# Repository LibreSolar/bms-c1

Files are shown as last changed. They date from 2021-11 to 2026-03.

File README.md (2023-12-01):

# Libre Solar BMS C1

 Tested prototype, only minor issues left.

This repository contains the files for ongoing development of the Libre Solar BMS C1.

**Remark:** This BMS was previously named **BMS 16S100 SC**. It was renamed to C1 (with C for compact/centralized) because the maximum current and supported number of cells depend on the parts actually populated on the PCB, so these specs should not be encoded in the PCB name.

The development of this BMS is funded by the [EnAccess foundation](https://enaccess.org).

Schematic: [PDF file](build/bms-c1.pdf)

Bill of Materials: [CSV file](build/bms-c1_bom.csv) or [interactive HTML BOM](https://libre.solar/bms-c1/bms-c1_ibom.html)

Firmware repository: [LibreSolar/bms-firmware](https://github.com/LibreSolar/bms-firmware)

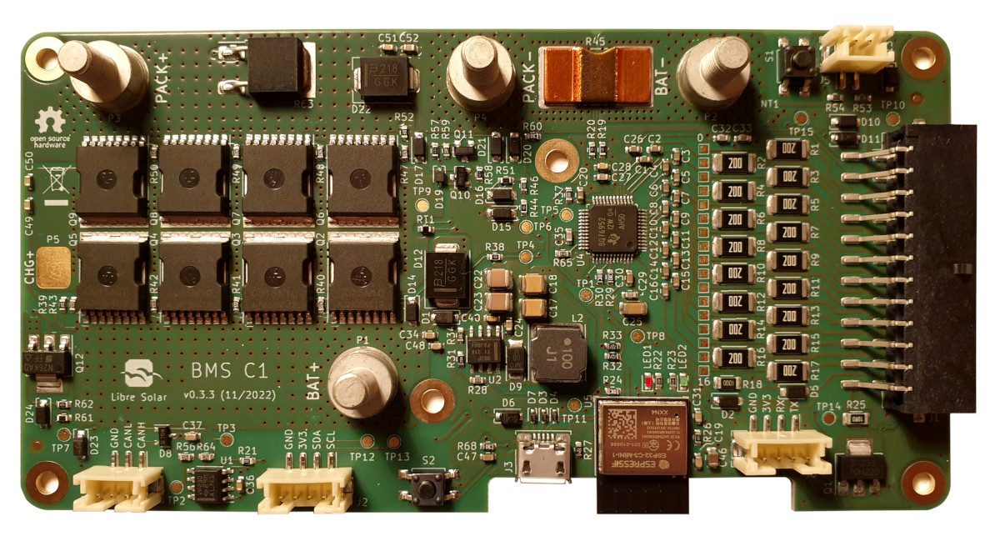
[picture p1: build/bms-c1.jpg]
BMS C1


User manual: [libre.solar/bms-c1/manual/](https://libre.solar/bms-c1/manual/)

Mechanical CAD file: [bms-c1.FCStd](housing/bms-c1.FCStd)

Mechanical BOM: [bms-c1_bom_mechanical.csv](housing/bms-c1_bom_mechanical.csv)

Heat sink drawings: [10003_BackPlateAsm.pdf](housing/10003_BackPlateAsm.pdf)

Test report: [testing/v0.3](testing/v0.3/README.md)

## Features

- 3 to 16 Li-ion cells in series
- Continuous current: 70-100A (depending on used MOSFETs and heat sink)
- Cell types: LiFePO4, Li-ion NMC and others (customizable)
- Measurements
  - Cell voltages
  - Pack voltage
  - Pack current
  - Pack (2x), MOSFET and shunt temperatures
- Based on Texas Instruments bq76952
- Integrated high-side MOSFET switch and current sensor
- Espressif ESP32-C3 microcontroller
- Communication interfaces:
  - CAN
  - RS-485 (connector shared with CAN)
  - USB (CDC-ACM and JTAG)
  - USART
  - I2C
  - Bluetooth Low Energy
  - WiFi
- Hardware features
  - 4-layer PCB
  - M5 screw terminals
  - Heat sink at back side
- Applications
  - Off-grid storage
  - Light-electric vehicles (LEV)

## Firmware

The firmware is developed in a separate repository [LibreSolar/bms-firmware](https://github.com/LibreSolar/bms-firmware).

## License

The hardware is licensed under the [CERN Open Hardware Licence Version 2 - Weakly Reciprocal](LICENCE).

Documentation is licensed under the [Creative Commons Attribution-ShareAlike 4.0 International (CC BY-SA 4.0) License](https://creativecommons.org/licenses/by-sa/4.0/).

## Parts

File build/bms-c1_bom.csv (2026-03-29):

Reference | Value | Datasheet | Footprint | Qty | DNP | Manufacturer | PartNumber | Remarks | Description
C1,C2,C3,C4,C5,C6,C7,C8,C9,C10,C11,C12,C13,C14,C15,C16,C26 | 220nF |  | LibreSolar:C_0603_1608 | 17 |  | Samsung Electro-Mechanics | CL10B224KA8NNNC | min. 25V, X7R
C17,C18 | 47µF |  | LibreSolar:C_1206_3216 | 2 |  | Samsung Electro-Mechanics | CL31A476MPHNNNE | min. 10V, X5R
C19,C21,C24,C28,C31,C34,C36,C37,C40,C48,C49,C50,C51,C52 | 100nF |  | LibreSolar:C_0603_1608 | 14 |  | Samsung Electro-Mechanics | CL10B104KC8NNNC | min. 100V, X7R
C20 | 2.2µF |  | LibreSolar:C_0603_1608 | 1 |  | Samsung Electro-Mechanics | CL10A225KP8NNNC | min. 10V, X7R
C22,C23 | 2.2µF |  | LibreSolar:C_1206_3216 | 2 |  | Samsung Electro-Mechanics | CL31B225KCHSNNE | min. 100V, X5R
C25 | 1µF |  | LibreSolar:C_1206_3216 | 1 |  | Samsung Electro-Mechanics | CL31B105KCHNNNE | min. 100V, X5R
C27,C29,C32,C33,C35,C38 | 100pF |  | LibreSolar:C_0603_1608 | 6 |  | Samsung Electro-Mechanics | CL10C101JC8NNNC | 100V, C0G/NP0
C30,C47 | 1µF |  | LibreSolar:C_0603_1608 | 2 |  | Samsung Electro-Mechanics | CL10A105KA8NNNC | min. 10V, X5R,min. 25V, X5R
C39 | 47uF |  | Capacitor_SMD:CP_Elec_10x10 | 1 |  | KYOCERA AVX | AEK1010470M100R | min. 100V
C46 | 10µF |  | LibreSolar:C_0805_2012 | 1 |  | Samsung Electro-Mechanics | CL21A106KPFNNNE | min. 10V, X5R
D1,D13 | PMEG10010ELRX |  | LibreSolar:D_SOD-123F | 2 |  | Nexperia | PMEG10010ELRX | Alternative: Nexperia PMEG10030ELPX
D2,D5,D10,D15,D16,D20 | BAT46W |  | LibreSolar:D_SOD-123 | 6 |  | Diodes Incorporated | BAT46W-7-F | Alternative: MCC BAT46WHE3-TP
D3,D4 | ESD5B5.0ST1G | https://www.mouser.de/datasheet/2/308/1/ESD5B5_0ST1_D-2311335.pdf | LibreSolar:D_SOD-523 | 2 |  | onsemi | ESD5B5.0ST1G
D8 | PESD2CANFD |  | Package_TO_SOT_SMD:SOT-23 | 1 |  | Nexperia | PESD2CANFD24V-TR | Alternative: onsemi ESDONCAN1LT
D9 | VSS8D3M10-M3/I |  | Diode_SMD:D_SOD-128 | 1 |  | Vishay | VSS8D3M10-M3/H | Alternative: Nexperia PMEG10030ELPX
D11 | 3.6V |  | LibreSolar:D_SOD-123 | 1 |  | onsemi | MMSZ4685T1G
D12 | SMCJ70A |  | LibreSolar:D_SMC | 1 |  | Bourns | SMCJ70A | Alternative: Diodes Inc. SMCJ70A-13-F
D14,D17,D21,D24 | 16V | https://www.mouser.de/datasheet/2/115/DIOD_S_A0003550771_1-2542306.pdf | LibreSolar:D_SOD-123 | 4 |  | Diodes Incorporated | MMSZ5246B-7-F | Alternative: Vishay MMSZ5246B-HE3-08
D19 | 5.1V |  | LibreSolar:D_SOD-323 | 1 |  | Diodes Incorporated | BZT52C5V1S-7-F | Vishay BZX384C5V1
D22 | MURS360 |  | LibreSolar:D_SMC | 1 |  | Diodes Incorporated | MURS360 | Alternative: Other MURS360
D23 | 75V | https://www.mouser.de/datasheet/2/115/DIOD_S_A0003550771_1-2542306.pdf | LibreSolar:D_SOD-123 | 1 |  | Diodes Incorporated | MMSZ5267BT1G
FID1,FID2 | Fiducial | ~ | Fiducial:Fiducial_1mm_Mask2mm | 2
H1,H2,H3,H4,H5,H6 | MountingHole | ~ | MountingHole:MountingHole_3.2mm_M3_Pad_TopBottom | 6
J1 | MicroFit 2x12 | ~ | Connector_Molex:Molex_Micro-Fit_3.0_43045-2410_2x12-1MP_P3.00mm_Horizontal | 1 |  | Würth | 662024231722 | Mating connector: 662024113322
J2,J6 | B4B-PH-SM4 | ~ | Connector_JST:JST_PH_B4B-PH-SM4-TB_1x04-1MP_P2.00mm_Vertical | 2 |  | JST | B4B-PH-SM4-TB(LF)(SN) | Alternative: Würth 620304124022
J3 | USB_C_Receptacle_USB2.0 | https://www.usb.org/sites/default/files/documents/usb_type-c.zip | Connector_USB:USB_C_Receptacle_GCT_USB4105-xx-A_16P_TopMnt_Horizontal | 1 |  | GCT | USB4105-GF-A
J4 | B3B-PH-SM4 | ~ | Connector_JST:JST_PH_B3B-PH-SM4-TB_1x03-1MP_P2.00mm_Vertical | 1 |  | JST | B3B-PH-SM4-TB(LF)(SN) | Alternative: Würth 620303124022
J5 | B2B-PH-SM4 | ~ | Connector_JST:JST_PH_B2B-PH-SM4-TB_1x02-1MP_P2.00mm_Vertical | 1 |  | JST | B2B-PH-SM4-TB(LF)(SN) | Alternative: Würth 620302124022
L2 | 22µH |  | LibreSolar:Bourns_SRN8040TA | 1 |  | Bourns | SRN8040-220M | Alternative: Tayo Yuden NR8040T220M
LED1 | LED red |  | LED_SMD:LED_0603_1608Metric | 1 |  | Lite-On | LTST-C190KRKT | red
LED2 | LED green |  | LED_SMD:LED_0603_1608Metric | 1 |  | Lite-On | LTST-C190KGKT | green
LOGO1 | OPEN_HARDWARE |  | Symbol:OSHW-Logo_5.7x6mm_SilkScreen | 1
LOGO2 | LIBRE_SOLAR |  | LibreSolar:LIBRESOLAR_LOGO | 1
NT1 | NetTie | ~ | NetTie:NetTie-2_SMD_Pad0.5mm | 1
P1,P2,P3,P4 | CONN_01X01 |  | LibreSolar:Wuerth_PowerOne_SMD_LF990005 | 4 |  | Erni | 225852-E | Alternative: Würth LF990005
P5 | CONN_01X01 |  | Connector_Wire:SolderWirePad_1x01_SMD_5x10mm | 1
Q1 | DMN10H220LE | ~ | Package_TO_SOT_SMD:SOT-223 | 1 |  | Diodes Inc. | DMN10H220LE | 100V, >2A, Alternative: IRFM120ATF
Q2,Q3,Q4,Q5,Q6,Q7,Q8,Q9 | IPT012N08N5 | ~ | Package_TO_SOT_SMD:Infineon_PG-HSOF-8-1_ThermalVias | 8 |  | Infineon | IPT012N08N5 | Alternative: Huayi HYG012N08NS1TA
Q10 | BSS84 |  | LibreSolar:SOT-23 | 1 |  | Nexperia | BSS84AK,215 | at least -20V
Q11 | BSS123N | ~ | LibreSolar:SOT-23 | 1 |  | Infineon | BSS123N H6327
Q12 | ZXMP10A17GTA | ~ | Package_TO_SOT_SMD:SOT-223-3_TabPin2 | 1 |  | Diodes Incorporated | ZXMP10A17GTA | Alternative: IRFL9110TRPBF
R1,R2,R3,R4,R5,R6,R7,R8,R9,R10,R11,R12,R13,R14,R15,R16,R17 | 20 |  | LibreSolar:R_2010_5025 | 17 |  | Yageo | RC2010JK-0720RL
R18 | 100 |  | LibreSolar:R_1206_3216 | 1 |  | Yageo | RC1206FR-07100RL
R19,R20,R38,R44 | 100 |  | LibreSolar:R_0603_1608 | 4 |  | Yageo | RC0603FR-07100RL
R21,R37 | 0R |  | LibreSolar:R_0603_1608 | 2 |  | Yageo | RC0603FR-070RL
R22,R23,R46 | 1k |  | LibreSolar:R_0603_1608 | 3 |  | Yageo | RC0603FR-071KL
R24,R26,R62 | 1M |  | LibreSolar:R_0603_1608 | 3 |  | Yageo | RC0603FR-071ML
R25 | 10 |  | LibreSolar:R_1206_3216 | 1 |  | Yageo | RC1206FR-0710RL
R27,R35,R53,R54 | 5.1k |  | LibreSolar:R_0603_1608 | 4 |  | Yageo | RC0603FR-075K1L
R28,R65 | 82k |  | LibreSolar:R_0603_1608 | 2 |  | Yageo | RC0603FR-0782KL
R29,R30,R60,R68,RT1,RT2 | 10k |  | LibreSolar:R_0603_1608 | 6 |  | TDK,Yageo | NTCG163JF103FT1S,RC0603FR-0710KL
R31 | 35.7k |  | LibreSolar:R_0603_1608 | 1 |  | Yageo | RC0603FR-0735K7L
R32,R33 | 2.2k |  | LibreSolar:R_0603_1608 | 2 |  | Yageo | RC0603FR-072K2L
R34 | 52.3k |  | LibreSolar:R_0603_1608 | 1 |  | Yageo | RC0603FR-0752K3L
R39,R52,R59 | 10M |  | LibreSolar:R_0603_1608 | 3 |  | Yageo | RC0603FR-0710ML
R40,R41,R42,R43,R47,R48,R49,R50,R57 | 47 |  | LibreSolar:R_0603_1608 | 9 |  | Yageo | RC0603FR-0747RL
R45 | 300µ |  | LibreSolar:R_Shunt_5931_Kelvin | 1 |  | Vishay | WSLP5931L3000FEA | Alternative: Bourns CSS2H-5930R-L300F
R51,R61 | 68k |  | LibreSolar:R_0603_1608 | 2 |  | Yageo | RC0603FR-0768KL
R56,R64 | 62R |  | LibreSolar:R_0603_1608 | 2 |  | Yageo | RC0603FR-0762RL
R58 | 470 |  | LibreSolar:R_0603_1608 | 1 |  | Yageo | RC0603FR-07470RL
R63 | 40 | https://www.mouser.de/datasheet/2/54/pwr163-777985.pdf | LibreSolar:Bourns_PWR163 | 1 |  | Bourns | PWR163S-25-40R0FE
S1,S2 | SW_PUSH |  | Button_Switch_SMD:SW_SPST_TL3305A | 2 |  | E-Switch | TL3305AF160QG
TP1,TP2,TP3,TP4,TP5,TP6,TP7,TP8,TP9,TP10,TP12,TP13,TP14,TP15 | TestPoint | ~ | TestPoint:TestPoint_Pad_D1.5mm | 14
TP16,TP17,TP18,TP19,TP20,TP21,TP22,TP23,TP24,TP25,TP26,TP27,TP28,TP29,TP30,TP31,TP32 | TestPoint | ~ | TestPoint:TestPoint_Pad_1.0x1.0mm | 17
U1 | SN65HVD230 | http://www.ti.com/lit/ds/symlink/sn65hvd230.pdf | Package_SO:SOIC-8_3.9x4.9mm_P1.27mm | 1 |  | Texas Instruments | SN65HVD230DR | Alternative: SN65HVD230QDR
U2 | SN65HVD75 | http://www.ti.com/lit/ds/symlink/sn65hvd11-ht.pdf | Package_SO:SOIC-8_3.9x4.9mm_P1.27mm | 1 |  | Texas Instruments | SN65HVD75DR | Alternative: ISL3178E
U3 | LMR38010 | https://www.ti.com/lit/ds/symlink/lmr38010.pdf | LibreSolar:SOIC-8-1EP_3.9x4.9mm_P1.27mm_EP2.4x3.1mm_ThermalVias | 1 |  | Texas Instruments | LMR38010SDDAR | Alternative: LMR38020SDDAR
U4 | BQ76952 | https://www.ti.com/lit/ds/symlink/bq76952.pdf | Package_QFP:TQFP-48_7x7mm_P0.5mm | 1 |  | Texas Instruments | BQ76952PFBR
U5 | ESP32-C3-MINI-1 | https://www.espressif.com/sites/default/files/documentation/esp32-c3-mini-1_datasheet_en.pdf | Espressif:ESP32-C3-MINI-1 | 1 |  | Espressif Systems | ESP32-C3-MINI-1-N4

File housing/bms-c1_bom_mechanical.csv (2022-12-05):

Component | Quantity | Description | Material | Supplier | Part Number / Type | Remarks
1 | 4 | Cable lugs 25mm², M5 | Copper | Klauke | 704F5 | Other supplier or cross-section possible depending on application.
2 | 4 | Nut, M5 | A2 stainless steel | any
3 | 4 | Washer, M5 | A2 stainless steel | any
4 | 6 | Screws for fixation, M3, ISO 7380-2 | A2 stainless steel | any
5 | 1 | Thermal pad | 0.5 mm, >1 W/m.K | Henkel / Bergquist | GAP PAD A2000 | Only required for high current, other supplier with similar material properties possible.
6 | 1 | Heat sink | Aluminum | Fischer Elektronik | SK553 | Only required for high current, other supplies/types possible.
7 | 1 | Cell connector | Plastic | Würth Elektronik | 662024113322
8 | 1 | Button connector + wires |  | JST | PH, 2-pin | Optional, depending on application.
9 | 1 | CAN connector + wires |  | JST | PH, 3-pin | Optional, depending on application.
10 | 1 | Serial connector + wires |  | JST | PH, 4-pin | Optional, depending on application.
11 | 1 | I2C connector + wires |  | JST | PH, 4-pin | Optional, depending on application.

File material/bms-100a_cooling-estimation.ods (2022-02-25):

Boundary conditions |  |  | Heat transfer
Ambient temperature | 40 | °C | Heat sink to ambient
Current (RMS) | 100 | A | Delta temperature | 36.0 | K
 |  |  | Temperature | 76.0 | °C
MOSFETs
MOSFET type | Infineon IPT015N10N5 |  | MOSFETs to heat sink
Rds(on) @120°C | 2 | mOhm | RthJC,single | 0.20 | K/W | typical, max: 0.4
Area below MOSFET | 90 | mm² | RthVias,single | 0.71 | K/W | approx. 30 K/W each according to KiCad calculator
Number of thermal vias | 42 | per MOSFET | RthTIM,single | 5.56 | K/W
Number of FETS in parallel | 4 |  | Rth,total | 0.11 | K/W
Number of FETS in series | 2 |  | Temperature | 77.1 | °C
Heat loss | 10 | W
 |  |  | Shunt to heat sink
Shunt |  |  | RthVias,single | 0.23 | K/W
Resistance | 0.5 | mOhm | RthTIM,single | 3.68 | K/W
Area below pads + bus bar | 136 | mm² | Rth,total | 3.91 | K/W
Number of thermal vias | 128 | incl. surrounding ones | Temperature | 95.6 | °C
Heat loss | 5 | W
Thermal interface material (TIM)
Thickness | 0.5 | mm
Heat conductivity | 1 | W/m.K
Heat sink (Fischer SK406)
Length | 140 | mm
Thermal resistance | 2.4 | K/W

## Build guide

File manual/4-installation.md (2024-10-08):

# Installation

**Attention**: The maximum operating voltage of the BMS is 60V. The 16s configuration is only feasible for LFP cells. For NMC cells, a maximum number of 14 cells may be used.

## Mechanical Design

The board dimensions are 70x135 mm² so that it can be easily integrated into existing housings with typical 18650 or 2170 cells.

BMS mounted on a heat sink

Depending on the current requirements and ambient temperatures, a heat sink may be required. For good thermal contact, a thermal interface material (e.g. Henkel/Bergquist GAP PAD A2000) is required, as shown in above picture.

## Connections

Below picture shows the connections of the cells, the 10k thermistors (NTC1 and NTC2) and the high power cables.

BMS connections for 16s

The BMS is powered through the BAT+ terminal. If only the cell connector is mounted, the power is provided through the additional BAT+ wire in the cell connector, which has to be connected to the last cell's positive terminal.

The BMS cannot be powered through the USB port only.

### Power connections

The high power terminals have an M5 thread and allow to fit wires of up to 35 mm² cross-section.

The nuts and washers should be made from stainless steel to avoid corrosion with copper cable lugs.

The wires must be properly fixed in the housing to reduce stress on the soldered terminals on the PCB.

The fixing torque for the nuts is 2.2 Nm. Use of a torque wrench is highly recommended.

### Signal connections

The MPC3 / Microfit connector must be equipped with properly crimped wires connected to the cells and the thermistors. Würth sells [pre-crimped wires](https://www.we-online.com/de/components/products/em/connectors/wire-to-board/wr_mpc3/wr_mpc3_pre_crimped_wire) so that no crimping tool is needed (the low-force type is recommended). These wires can be cut in half and connected to the application specific wiring harness.

The first signal connection and the very last one (respectively shown in grey and orange in the connection diagram) are used for powering up the BMS.

Both NTCs have to be connected and indicate a valid temperature range for the BMS to allow charging/discharging.

### Less than 16 cells

- Route the last wire of the harness (shown in orange) to the wire before the last Microfit pin.
- Short the unused cell connections:
  - on the PCB using the exposed pads as per the schematic below in cyan
  - or in the wiring harness directly.

BMS connections for 12s

See also the [BQ76952 documentation](https://www.ti.com/product/BQ76952) for further details.

### Test wiring harness

In order to test out the BMS, a test harness as shown in below picture can be used instead of an actual battery pack. The harness must be powered with a lab power supply set to 12V for the example with a 4s configuration. The resistor divider simulates individual cell voltages (here around 3V).

BMS test harness for 4s configuration

### Connection order

1. Connect the fully wired cell connector. (Note the two separate connections to the first cell's negative terminal)
2. Connect the BAT- terminal.
3. Connect the BAT+ terminal (with a fuse in line, as shown).
4. Connect load or charger.

## Communication ports

The CAN, UART and I2C communication ports use JST PH connectors. The pinout is marked on the PCB.

The I2C is shared with the BQ76952. It must be ensured that this communication is not disturbed by another component on the I2C bus.

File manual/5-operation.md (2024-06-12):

# Operation

## Firmware flashing

If no firmware is flashed on the board, make sure the board is powered through the cell connector. The power wires BAT+ and BAT- are optional.

The firmware is flashed through the USB port. Follow the instructions in the [Firmware documentation](https://libre.solar/bms-firmware/src/dev/building_flashing.html).

## Start-up

In order to wake up the BMS chip, short-press the ON/OFF button S1 (top-right corner).

If the button is long-pressed for at least 3 seconds, the BMS will go into low-power shutdown mode.

A custom push-button as part of the battery housing can be connected to the connector J5 next to the button.

## LED indications

The BMS is equipped with two status LEDs with below indications:

Red LED:

| Status | Meaning |
|---|---|
| off | Discharging finished and battery is empty |
| on | Discharging allowed (current below idle threshold) |
| blinking slowly | Discharging active (current above idle threshold) |
| flashing quickly | Discharging error (UV/OT/UT/OC/SC) |

Green LED:

| Status | Meaning |
|---|---|
| off | Charging finished and battery is full |
| on | Charging allowed (current below idle threshold) |
| blinking slowly | Charging active (current above idle threshold) |
| flashing quickly | Charging error (OV/OT/UT/OC) |

## Communication Setup

Device information, configuration values and measurements can be explored using the [ThingSet protocol](https://thingset.io/). This protocol is used for the serial interface as well as the Bluetooth communication.

For details regarding the protocol consider the specification linked above. The basic setup is explained below.

### USB Serial

The USB virtual COM port exposes log data and the Zephyr shell. Among other commands, the shell can also be used for communication using the ThingSet protocool.

A terminal program like `picocom` is recommended:

```
picocom /dev/ttyACM0
```

The shell command for the ThingSet protocol is `thingset`. Either prefix it for every command or `select thingset` to switch into ThingSet mode.

```
select thingset
?Meas
:85 {"rPackVoltage_V":13.71,"rStackVoltage_V":13.91,"rPackCurrent_A":0.05,"rBatTemp_degC":29.4,"rICTemp_degC":34.2,"rMOSFETTemp_degC":31.8,"rSOC_pct":100.0,"rErrorFlags":0,"rBmsState":3,"rCellVoltages_V":[3.495,3.497,3.486,3.495,0.000,0.000,0.000,0.000,0.000,0.000,0.000,0.000,0.000,0.000,0.000,0.000],"rCellAvgVoltage_V":3.493,"rCellMinVoltage_V":3.486,"rCellMaxVoltage_V":3.497,"rBalancingStatus":0}
```

When using the shell, the quotation marks in JSON data have to be escaped. See below for an example:

```
=Conf {\"sCellOvervoltage_V\": 3.8}
:84
```

### UART Serial

The serial interface uses a baud-rate of 115200 bps. Depending on the operating system, you can use different tools to communicate with the serial interface manually.

For Linux [CuteCom](https://sourceforge.net/projects/cutecom/) is recommended, as it stores a history of previous commands.

The [Serial2Websocket Python script](https://github.com/ThingSet/thingset-serial2websocket) can be used as a basis for own scripts to use the monitoring data.

### BLE

The generic [ThingSet app](https://github.com/ThingSet/thingset-app) can be used to connect to the BMS via Bluetooth LE.

For own developments see the BLE transport layer specification on the ThingSet website and consider the implementation of the device side in the [ThingSet Zephyr SDK](https://github.com/ThingSet/thingset-zephyr-sdk).

## Configuration

The ThingSet protocol itself allows to discover available data items for configuration, so this manual will only use some examples for demonstration purposes.

### Read measurements and battery status

Use the following command to get the current state of the battery, including all current, temperature and voltage measurements:

```
?Meas
```

### Configure battery type

The configuration for a particular cell type and battery size can be preset with suitable default values using the two executable data items `xPresetNMC` for NMC cells and `xPresetLFP` for LFP cells. The functions expect a parameter defining the nominal capacity of the battery in Ah.

For an LFP battery with 45 Ah, send the following command to the BMS:

```
!Conf/xPresetLFP [45]
```

The expected response if the parameters were successfully set:

```
:84 0
```

### Adjust thresholds

The current configuration can be determined with the following command:

```
?Conf
```

Individual parameters can be adjusted with a command as shown below (using the overvoltage threshold as an example):

```
=Conf {"sCellOvervoltage_V": 3.8}
```

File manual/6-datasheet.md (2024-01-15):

# Datasheet

--------------------------------------------------------------------------------------------
Feature                             Value                   Comment
----------------------------------  ----------------------- ------------------------------------
**Battery**

Nominal voltage range               12 V to 48 V

Maximum voltage                     70 V

Maximum current                     70 A - 100 A            Depending on ambient conditions and
                                                        heat sink

Self consumption                    < 20 mA                 Exact value t.b.d.

Shutdown current                    < 1 mA                  Exact value t.b.d.

Cell types                          LFP, NMC and others     Customizable through firmware

**Interfaces**

CAN 2.0

RS-485 (connector shared with CAN)

USB CDC-ACM

UART serial

I2C

Bluetooth

**Protection**

Over-/undervoltage

Overcurrent / Short circuit

Over-/undertemperature

**Environmental conditions**

Operating ambient temperature       -10 °C to +50 °C

Storage temperature                 -20 °C to +60 °C

Humidity                            <95%, non-condensing

**Mechanical design**

Screw terminals                     M5, torque: 2.2 Nm

Weight                              t.b.d.

Dimensions                          70 mm x 135 mm
----------------------------------  ----------------------- ------------------------------------

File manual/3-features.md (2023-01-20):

# Features

## System overview

The BMS is the heart of every Li-ion battery. It is needed to equalize series connected cells and protect the battery from current, voltages and temperatures outside the allowed operating range.

Below figure shows a complete battery system with the integrated BMS.

Overview of the BMS integrated into a Li-ion battery pack.

This BMS has the following high-level features:

- Flexible and fully Open Source design
- Suitable for 12V, 24V or 48V systems (up to 16 LFP cells in series)
- Continuous currents of up to 100A

With above specifications it is suitable for the following applications:

- Poductive use appliances like milling machines
- Energy storage for AC mini-grid applications with up to 4 kVA inverters
- Second-life batteries built e.g. from recycled EV batteries
- Generic off-grid energy storage e.g. in caravans

## Hardware

BMS Overview

### Board design

All electronics components (power and control) are integrated into a single PCB in order to reduce cost and size.

The board contains the following main subsystems:

- Power part (top left)
  - High current terminals
  - MOSFETs (4 in parallel, 2 in series for bi-directional switching)
  - Current measurement shunt

- Control part (bottom right)
  - Microcontroller: ESP32-C3
  - BMS ASIC: Texas Instruments BQ76952
  - Internal power supply
  - Communication interfaces (CAN, UART, I2C, USB, Bluetooth)

### MCU: ESP32-C3

The [Espressif ESP32-C3](https://www.espressif.com/en/products/socs/esp32-c3) is a single-core microcontroller featuring Wi-Fi, Bluetooth 5 (LE) and CAN (called TWAI by Espressif). It is based on the open-source RISC-V architecture.

### BMS IC: BQ76952

The [Texas Instruments BQ76952](https://www.ti.com/product/BQ76952) was selected as the BMS IC as it offers a good compromise between accuracy, features and cost.

Features according to Datasheet:

- Battery monitoring capability for 3-series to 16-series cells
- Integrated charge pump for high-side NFET protection with optional autonomous recovery
- Extensive protection suite including voltage, temperature, current, and internal diagnostics
- Two independent ADCs
- Support for simultaneous current and voltage sampling
- High-accuracy coulomb counter with input offset error < 1 uV (typical)
- High accuracy cell voltage measurement < 10 mV (typical)
- Wide-range current applications (±200-mV measurement range across sense resistor)
- Integrated secondary chemical fuse drive protection
- Autonomous or host-controlled cell balancing
- Multiple power modes (typical battery pack operating range conditions)
- NORMAL mode: 286 uA
- Multiple SLEEP mode options: 24 uA to 41 uA
- Multiple DEEPSLEEP mode options: 9 uA to 10 uA
- SHUTDOWN mode: 1 uA
- High-voltage tolerance of 85 V on cell connect and select additional pins
- Tolerant of random cell attach sequence on production line
- Support for temperature sensing using internal sensor and up to nine external thermistors
- Integrated one-time-programmable (OTP) memory programmable by customers on production line
- Communication options include 400-kHz I2C, SPI, and HDQ one-wire interface
- Dual-programmable LDOs for external system usage
- 48-pin TQFP package (PFB)

### Balancing

The BMS features passive balancing with up to 100 mA.

### Protective switches

The positive battery terminal can be disconnected by the BMS for safety reasons or upon demand of the user via a communicatoin interface.

The disconnect switches are N-channel MOSFETs in a back-to-back configuration to be able to interrupt current in both directions (see also BQ76952 datasheet). In order to allow the high currents, 4 MOSFETs are connected in parallel.

The bottom side of the PCB can be attached to a heat sink to dissipate the heat at high continuous currents.

The cell connector has a pin to trigger a fuse at the pack positive terminal as a secondary protection if the MOSFETs fail short.

### Current measurement

The current is measured using a shunt, located in the negative voltage path of the battery pack. The shunt voltage is amplified by the BQ76952 ASIC and read by the MCU.

Time-critical safety features like overcurrent and short circuit protection are implemented directly in the ASIC and can be calibrated via firmware.

### Cell and thermistor connectors

The cells and thermistors are connected to the BMS using [Molex Micro-Fit](https://www.molex.com/molex/products/family/microfit_30) or [Würth WR-MPC3](https://www.we-online.com/katalog/en/em/connectors/wire-to-board/wr_mpc3) series connectors.

Both series are pin-compatible and there are even more compatible connectors in the market for this popular series. The connectors can handle up to 5A, which is sufficient even for active balancing.

### Power connectors

The BMS is designed for up to 100A continuous current, depending on ambient temperatures, heat sink and actually fitted MOSFETs.

Würth high-power solder terminals with M5 threads are used for wire-to-board connections.

## Communication interfaces

One major advantage of an Open Source design is its extensibility and adaptation to specific requirements.

In order to provide the hardware interfaces required to add custom extensions, two options are offered. Communication between multiple BMSs or other devices like charge controllers can be achieved via CAN bus, while the addional interfaces like I2C and UART can be used for extension of the board with internal features like displays.

The MCU features built-in WiFi and Bluetooth communication.

The serial and Bluetooth communication interfaces use the [ThingSet protocol](https://thingset.io/) by default, which allows to read measurement values from the BMS as well as store custom configuration.

## Firmware

The firmware is based on [Zephyr RTOS](https://www.zephyrproject.org/) and thus allows for easy integration of additional communication features. The latest Zephyr long-term support release is in the process of being certified for functional safety according to IEC 61508.

Amongst all features inherited from underlying Zephyr, the BMS firmware has the additional BMS-specific features:

- Monitoring and configuration using the [ThingSet](https://thingset.io/) protocol (mapping to MQTT, CoAP and HTTP possible)
  - Serial interface
  - CAN bus
  - I2C
  - Bluetooth
  - WiFi
- SOC estimation based on coulomb counting
- Configuration options
  - Pack layout
    - Cell chemistry (LiFePO4, NMC, NCA)
    - Nominal capacity
    - Number of cells
    - Thermistor type
    - Shunt resistor
    - Custom open circuit voltage (OCV) look-up table
  - Protection
    - Discharge short circuit limit (A)
    - Discharge short circuit delay (us)
    - Discharge over-current limit (A)
    - Discharge over-current delay (ms)
    - Charge over-current limit (A)
    - Charge over-current delay (ms)
    - Cell target charge voltage (V)
    - Cell discharge voltage limit (V)
    - Cell over-voltage limit (V)
    - Cell over-voltage error reset threshold (V)
    - Cell over-voltage delay (ms)
    - Cell under-voltage limit (V)
    - Cell under-voltage error reset threshold (V)
    - Cell under-voltage delay (ms)
    - Discharge over-temperature (DOT) limit (°C)
    - Discharge under-temperature (DUT) limit (°C)
    - Charge over-temperature (COT) limit (°C)
    - Charge under-temperature (CUT) limit (°C)
    - Temperature limit hysteresis (°C)
  - Balancing
    - Enable automatic balancing.
    - Balancing cell voltage target difference (V)
    - Minimum cell voltage to start balancing (V)
    - Current threshold to be considered idle (A)
    - Minimum idle duration before balancing (s)

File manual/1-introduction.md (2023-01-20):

# Introduction

The Libre Solar BMS C1 is a flexible Open Source Battery Management System (BMS) suitable for various applications.

This manual describes the usage and most important functions of the BMS. Please visit [learn.libre.solar](https://learn.libre.solar) for general information about battery management systems, charge controllers and other devices for DC energy systems.

Read this manual carefully and make sure you understand everything before starting with installation of the BMS.

Same as the hardware and firmware of the BMS, also this manual is Open Source. If you find any errors or have suggestions for improvement, please contribute to [the repository on GitHub](https://github.com/LibreSolar/bms-c1/).

## Project background

The main target of the project behind this BMS is to provide a solid technical basis for custom developments of organizations working in the energy access sector.

The project is funded by the [EnAccess Foundation](https://enaccess.org/).



The development is driven by the Libre Solar and EnAccess Communities. Visit the following websites for most recent updates:

- EnAccess Community: [community.enaccess.org](https://community.enaccess.org/)

- Libre Solar Community: [talk.libre.solar](https://talk.libre.solar/)

Hardware and firmware source files are published on GitHub:

- Hardware Repository: [github.com/LibreSolar/bms-c1](https://github.com/LibreSolar/bms-c1)

- Firmware Repository: [github.com/LibreSolar/bms-firmware](https://github.com/LibreSolar/bms-firmware)

## Disclaimer

This user manual has been written and checked with care and to the best of our knowledge.

Libre Solar assumes no liability for the accuracy, completeness or quality of the information provided. Liability claims against the team for material, physical or immaterial damages caused by the use or non-use of the information provided or by the use of incorrect and/or incomplete information are excluded.

All information and instructions are non-binding. Libre Solar reserves the right to change, supplement or delete parts of the pages or the entire document without prior notice.

## License

This user manual document is licensed under the Creative Commons Attribution-ShareAlike 4.0 International (CC BY-SA 4.0) License.



The full license text is available at [https://creativecommons.org/licenses/by-sa/4.0/](https://creativecommons.org/licenses/by-sa/4.0/).

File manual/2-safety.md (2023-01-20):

# Safety Instructions

- The BMS shall only be used for the intended application.

- The maximum voltage and current of the connected batteries or loads must not exceed the limits of the BMS.

- Ensure that the BMS is configured correctly for the used battery type.

- Install the device considering general best practices for electrical and mechanical installations in accordance to laws in your country.

- An additional fuse must be installed as close to the battery positive terminal as possible.

- As sparks can occur during connection of the battery wires, don't install the BMS close to any flammable materials.

- The wire cross-section has to be large enough to handle at least the maximum specified current of the BMS.

- Use insulated tools only.

- Fix the wires outside the BMS to provide a strain relief and reduce forces on the terminals.

- Mount the device on a solid, non-inflammable material only. Depending on the ambient conditions and the average current, a heat sink may be required.

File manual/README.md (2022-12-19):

# User Manual

This user manual uses [Pandoc](https://pandoc.org/) to auto-generate PDF and HTML files based on markdown content.

It can be easily integrated into existing repositories and deployed via [gh-pages](https://pages.github.com).

Please install the most recent Pandoc package to get best results on your local computer.

## Content editing

The text of the manual is located in the *.md files in this folder. Images are stored in the `images` folder.

## PDF generation

PDF files are generated using LaTeX, so a working LaTeX engine needs to be installed on your system already (e.g. texlive incl. extra fonts). The manual uses the [Eisvogel](https://github.com/Wandmalfarbe/pandoc-latex-template) template.

```
make pdf
```

## HTML generation

The HTML template is based on the great [mdBook](https://github.com/rust-lang-nursery/mdBook) theme, which was simplified and adjusted a bit to suit the needs of a manual.

```
make html
```

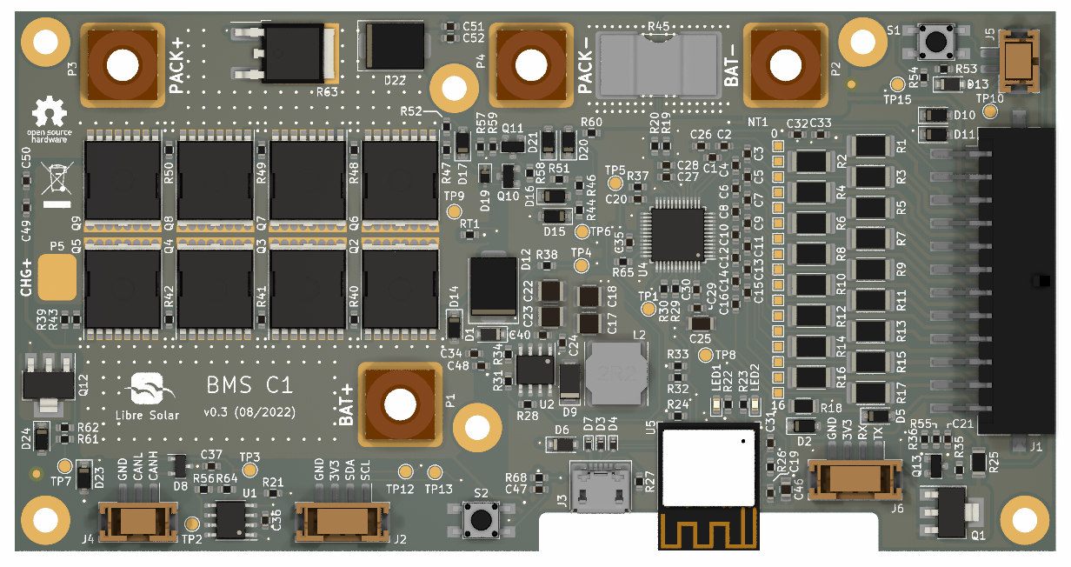
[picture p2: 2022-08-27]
manual/images/bms-c1.png

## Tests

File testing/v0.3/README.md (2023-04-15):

# Test Report

This report describes the tests performed with the Libre Solar BMS C1 v0.3 board released as part of the project funded by EnAccess foundation.

The testing was started with firmware commit [ff09cfe](https://github.com/LibreSolar/bms-firmware/tree/ff09cfed5e36c725bdfe6951e77a32af43480faa).

During testing some bugs were fixed. The final working firmware commit after testing is [408d783](
https://github.com/LibreSolar/bms-firmware/tree/408d783656e0310491120b7033ddef3bc76ef599).

## 1 Test setup and equipment

### 1.1 Test setup

Except for the balancing tests, all tests were performed without an actual battery. Instead, a bi-directional power supply (see below for equipment details) was used to simulate a battery. The cell voltages were generated with a voltage divider network between the positive and negative power supply terminal.

For the performance tests, the BMS was mounted to a heat sink. Other tests without high current requirements were partly done without a heat sink attached.

The below picture shows the setup of the BMS during testing.

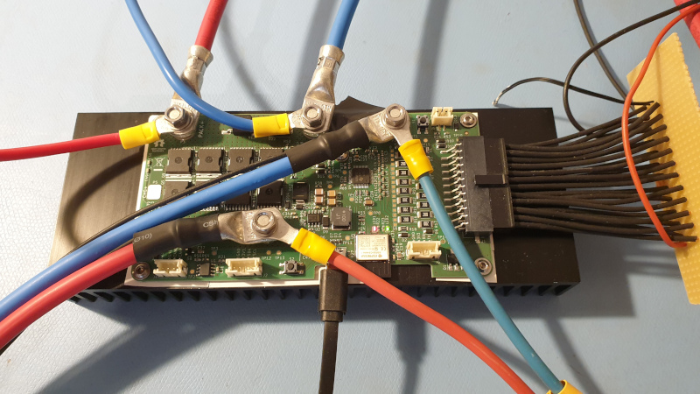
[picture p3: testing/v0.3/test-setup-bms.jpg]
Test setup: BMS


### 1.2 Used equipment

The following equipment was used for the tests:

- Elektro-Automatik EA-PSI 9200-50 power supply
- Elektro-Automatik EA-PSB 10080-120 bi-directional power supply
- Fluke 87 V Multimeter
- FLIR E8 thermal camera
- Rohde & Schwarz HMO1002 Oscilloscope
- Linux computer

Below picture shows the different power supplys during the performance test.

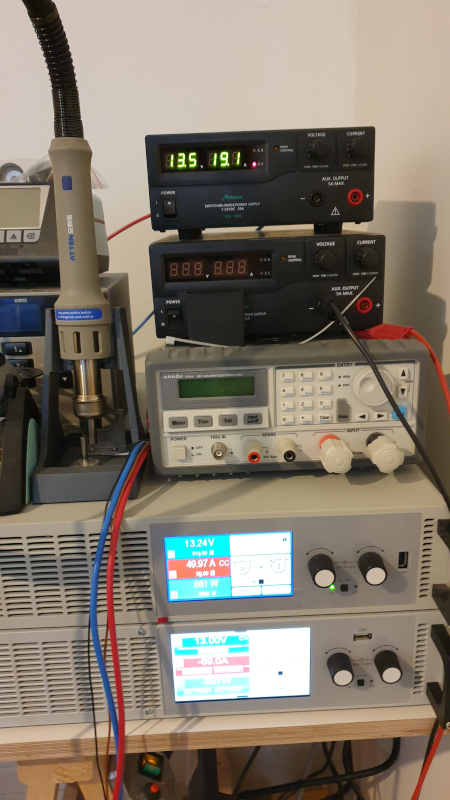
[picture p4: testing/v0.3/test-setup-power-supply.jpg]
Test setup: BMS


## 2 Communication tests

### 2.1 USB serial



#### Device under test (DUT)

Libre Solar BMS C1, v0.3.3, Node ID: D91E6099D8B390DB

#### Requirements

- Serial communication with a host computer must work reliably.
- Flashing new software through the serial port must work.

#### Test description

The BMS was powered up and connected to the host computer with a USB cable. New firmware was flashed to the board. Afterwards ThingSet commands were sent to the device and it was checked if a a valid response was received.

Previous issues with disconnected serial port during Bluetooth operation were resolved in the firmware.

### 2.2 UART serial



#### Device under test (DUT)

Libre Solar BMS C1, v0.3

#### Requirements

- Serial communication with a host computer must work reliably through a USB to serial converter (e.g. FTDI).

#### Test description

The devicetree of the BMS board (`bms_c1.dts`) was adjusted such that the `uart0` is used for ThingSet commnication.

Afterwards, a USB to serial converter was connected to the built-in connector J6 and the communication was tested (both sending and receiving direction).

### 2.3 I2C



#### Device under test (DUT)

Libre Solar BMS C1, v0.3.3, Node ID: D91E6099D8B390DB

#### Requirements

- The BMS communicates successfully with the bq76952 chip.

#### Test description

There were several issues with the Zephyr I2C driver for the ESP32-C3:

1. [Clock stretching not long enough](https://github.com/zephyrproject-rtos/zephyr/issues/51351)

    The bq76952 requires long clock stretching in the I2C communication, which was working fine with STM32 MCUs, but not with the ESP32-C3 driver. The fix was provided to Zephyr upstream, see above issue for links and further details.

2. [Pin glitches during start-up](https://github.com/zephyrproject-rtos/zephyr/issues/51250)

    This issue is still not fixed and the root cause is unknown. However, the BMS makes a second attempt to communicate with the bq76952 chip, which will succeed if the first one failed because of the glitches.

Finally, I2C communication is working reliably.

### 2.4 CAN



#### Device under test (DUT)

Libre Solar BMS C1, v0.3.3, Node ID: BD43AA35DB492F4A

#### Requirements

- The BMS completes the automatic node address assignment process as specified in the ThingSet protocol.
- The BMS sends out live measurement data.

#### Test description

The BMS was connected to a CAN bus and the traffic was logged on a Linux host system.

Output on serial debug console:

```
I: Using CAN node address 0x01
```

Messages on the bus logged on Linux host with `candump`:

```
  can0  1E007101   [5]  FA 41 3C 00 00
  can0  1E007201   [5]  FA 41 3E B8 52
  can0  1E007301   [5]  FA 00 00 00 00
  can0  1E007401   [5]  FA 41 90 66 70
  can0  1E007501   [5]  FA 41 9B 99 A0
  can0  1E007701   [5]  FA 41 92 00 00
  can0  1E007C01   [5]  FA 40 2B 3C E0
  can0  1E007E01   [1]  00
  can0  1E007F01   [1]  03
  can0  1E008001   [6]  90 FA 40 3F 8D 50
  can0  1E008101   [5]  FA 40 3F 81 07
  can0  1E008201   [5]  FA 40 3F 1A A0
  can0  1E008301   [5]  FA 40 3F BE 77
  can0  1E008401   [1]  00
```

## 3 MOSFET circuit tests

### 3.1 Pre-discharge circuit



#### Device under test (DUT)

Libre Solar BMS C1, v0.3

#### Requirements

- The pre-discharge MOSFET should charge the bus through the pre-discharge resistor before switching on the main MOSFETs.

#### Test description

The Oscilloscope was connected as follows:

- Yellow (CH1): PDSG (TP7)
- Blue (CH2): DSG (TP6)

The BMS was switched on twice under different conditions.

1. `BAT+` and `BAT-` terminals open

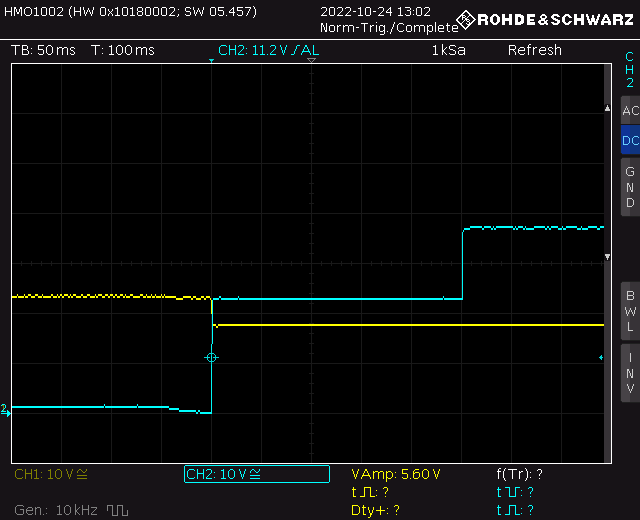
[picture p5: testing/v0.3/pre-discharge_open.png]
Pre-discharge open


2. `BAT+` and `BAT-` terminals connected to 1200 µF electrolytic capacitor

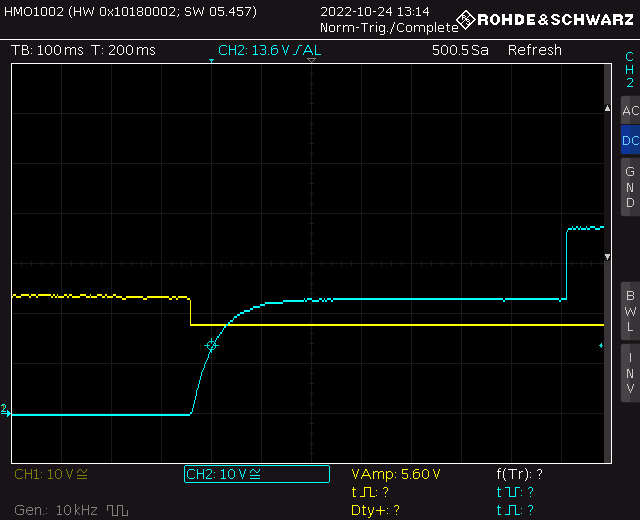
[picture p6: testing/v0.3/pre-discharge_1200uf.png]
Pre-discharge 1200uF


As shown in the second oscilloscope shot, if there is a large bus capacitance, the discharge MOSFET gate driver is switched on with a delay and only after the bus voltage has reached the battery pack voltage.

### 3.2 Switching of Power MOSFETs



#### Requirements

- The charge and discharge MOSFETs can be switched on and off individually via ThingSet.

#### Test description

Below operations were performed and the voltages measured with the multimeter.

1. The BMS is put into normal operation.
2. The ThingSet command `=Input {"wChgEnable":false}` is sent to the BMS to switch off the charge path of the MOSFETs.
3. The ThingSet command `=Input {"wChgEnable":true}` is sent to the BMS to switch on the charge path of the MOSFETs again.
4. The ThingSet command `=Input {"wDisEnable":false}` is sent to the BMS to switch off the discharge path of the MOSFETs.
5. The ThingSet command `=Input {"wDisEnable":true}` is sent to the BMS to switch on the discharge path of the MOSFETs again.

#### Test results

The following table shows the measured voltage for the individual steps.

| Step  | BAT+ | CHG+ | PACK+ |
|---|---|---|---|
| 1 | 11.97 V | 11.97 V | 11.97 V |
| 2 | 11.97 V | 11.71 V | 11.71 V |
| 3 | 11.97 V | 11.97 V | 11.97 V |
| 4 | 11.97 V | 11.97 V |  0.05 V |
| 5 | 11.97 V | 11.97 V | 11.97 V |

Both MOSFETs switch off and on as expected.

### 3.3 Balancing



#### Requirements

- Configured voltage thresholds are considered.
- No adjacent cells are balanced.

#### Test description

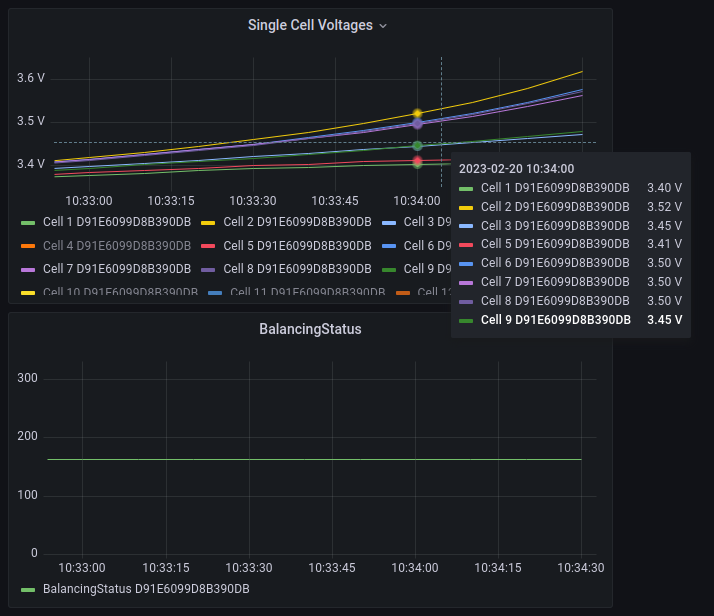
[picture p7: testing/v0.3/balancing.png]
Balancing


The balancing target voltage difference (parameter `Conf/sBalTargetVoltageDiff_V`) is set to 0.01 V (10 mV). Afterwards a battery pack with 8 cells is charged at low rate and the balancing status register is observed.

The `rBalancingStatus` has a value of `162`, which means that cells 2, 6 and 8 (bits 1, 5 and 7) are balanced.

Cell 7 cannot be balanced at the same time as it is adjacent to cells 6 and 8. The algorithm is working correctly.

### 3.4 BMS on/off button / connector



#### Requirements

- A long-press (>3 seconds) switches off the battery.
- A short press for a sleeping battery turns on the battery again.

#### Test description

Long-press the button to switch off the BMS and turn it on afterwards.

The button works as required.

## 4 Protection tests

These tests go beyond the requirements of IEC 62619, which does not contain an undervoltage test.

The following configuration for LFP cells is used for the protection tests (the current thresholds were set to very low limits for testing purposes):

| `Conf` Parameter | Value |
|---|---|
| `sNominalCapacity_Ah` | 50.0  |
| `sShortCircuitLimit_A` | 200.0 |
| `sShortCircuitDelay_us` | 195 |
| `sDisOvercurrent_A` | 13.3  |
| `sDisOvercurrentDelay_ms` | 320 |
| `sChgOvercurrent_A` | 13.3  |
| `sChgOvercurrentDelay_ms` | 320 |
| `sDisMaxTemp_degC` | 45.0  |
| `sDisMinTemp_degC` | -20.0 |
| `sChgMaxTemp_degC` | 45.0  |
| `sChgMinTemp_degC` | 0.0 |
| `sTempLimitHysteresis_degC` | 5.0 |
| `sCellOvervoltage_V` | 3.8 |
| `sCellOvervoltageReset_V` | 3.4 |
| `sCellUndervoltage_V` | 2.5 |
| `sCellUndervoltageReset_V`  | 3.1 |
| `sBalTargetVoltageDiff_V`:  | 0.010 |
| `sBalMinVoltage_V`: | 3.3 |
| `sBalIdleDelay_s`: | 1800  |
| `sBalIdleCurrent_A`: | 0.1 |

### 4.1 Overvoltage protection



#### Requirements

The BMS switches off the charge MOSFET when the overvoltage threshold `Conf/sCellOvervoltage_V` is reached and switches the MOSFET on again after the voltage drops to threshold `Conf/sCellOvervoltageReset_V`.

#### Test description

The voltage at the power supply is increased from 3.3 V to approx. 3.7 V per cell. After a few seconds the voltage is further increased to approx. 3.9 V per cell.

At the end, the voltage is decreased below 3.4 V per cell.

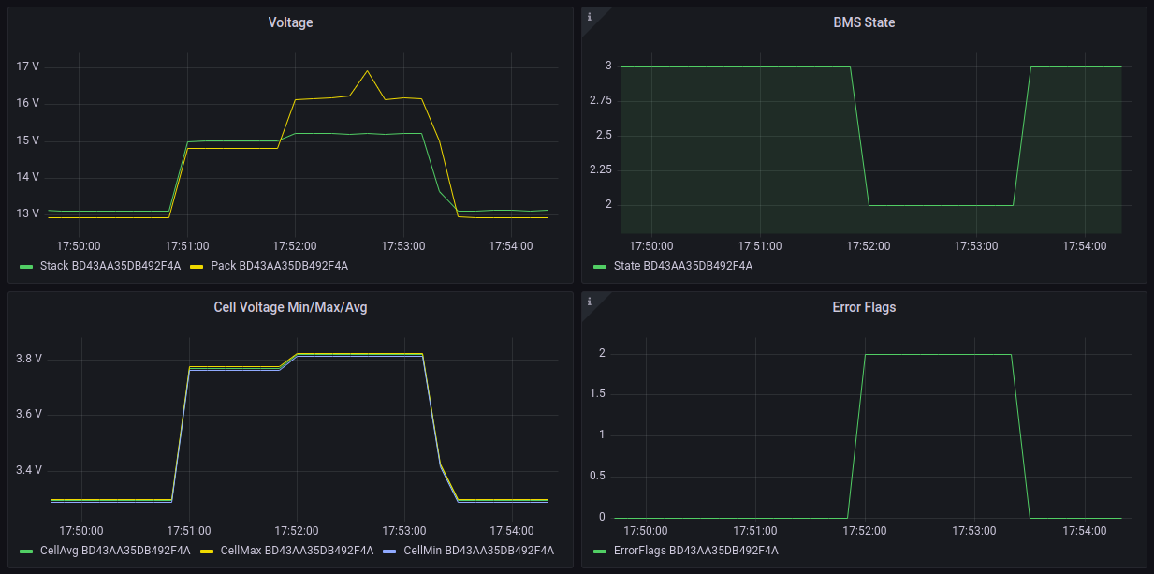
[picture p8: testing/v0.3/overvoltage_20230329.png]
Overvoltage test


As shown in above picture, the overvoltage is detected correctly and the BMS flags a cell overvoltage error. The charge MOSFET is disabled (state 2).

After reaching voltages below the reset threshold of 3.4 V again, the BMS goes back to normal operation.

### 4.2 Undervoltage protection



#### Requirements

The BMS switches off the discharge MOSFET when the undervoltage threshold `Conf/sCellUndervoltage_V` is reached and switches the MOSFET on again after the voltage rises above threshold `Conf/sCellUndervoltageReset_V`.

#### Test description

The voltage at the power supply is decreased from 2.6 V to approx. 2.4 V per cell.

At the end, the voltage is increased above 3.1 V per cell.

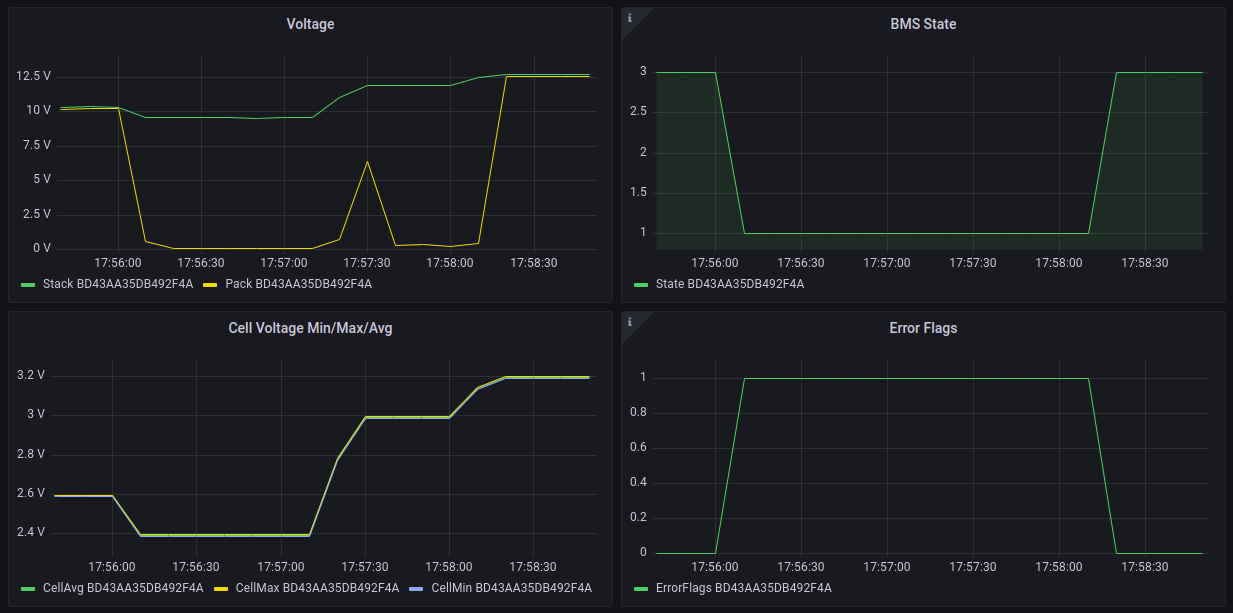
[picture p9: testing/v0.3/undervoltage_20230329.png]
Overvoltage test


As shown in above picture, the undervoltage is detected correctly and the BMS flags a cell undervoltage error. The discharge MOSFET is disabled (state 1).

After reaching voltages above the reset threshold of 3.1 V again, the BMS goes back to normal operation.

### 4.3 Charge overcurrent protection



#### Requirements

The BMS switches off the charge MOSFET when the charge overcurrent threshold `Conf/sChgOvercurrent_A` is reached and switches the MOSFET on again after the current changes direction.

#### Test description

A power supply is connected to the PACK terminals and provides charging current (positive sign) of around 13 A. After a few seconds, the current is increased to 14 A.

To reset the error, a discharging current of 1 A (negative sign) is applied via an electronic load.

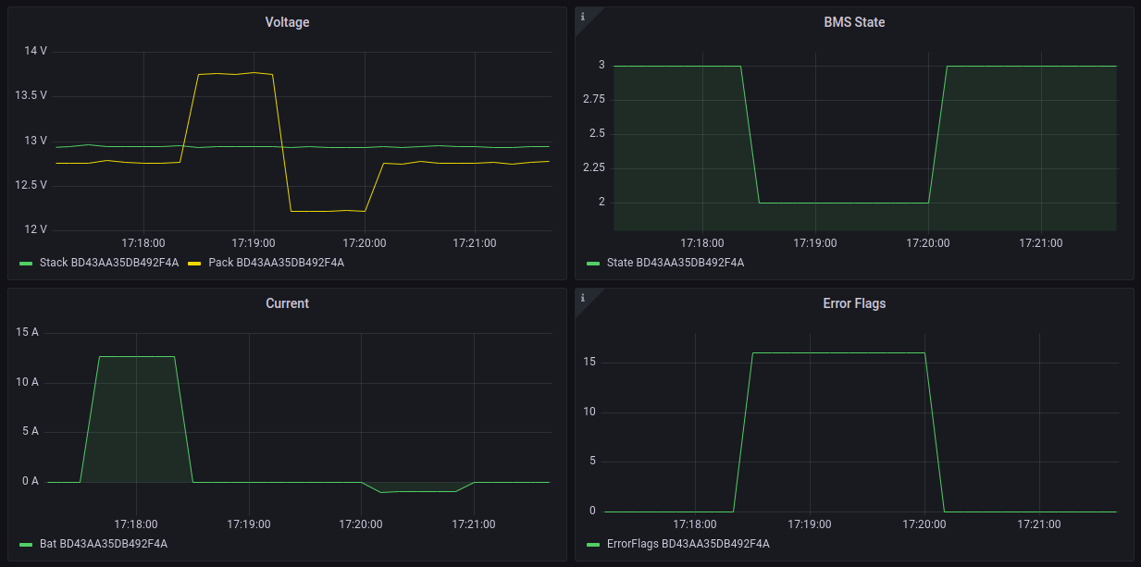
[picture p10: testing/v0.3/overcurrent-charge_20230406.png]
Charge overcurrent test


As shown in above picture, the charge overcurrent is detected correctly and the BMS flags a charge overcurrent error (16). The charge MOSFET is disabled (state 2).

After observing the current in the opposite direction, the error is cleared and the BMS goes back to normal operation.

### 4.4 Discharge overcurrent protection



#### Requirements

The BMS switches off the discharge MOSFET when the discharge overcurrent threshold `Conf/sDisOvercurrent_A` is reached and switches the MOSFET on again after the current changes direction.

#### Test description

An electronic load is connected to the PACK terminals and provides discharge current (negative sign) of around 13 A. After a few seconds, the current is increased to 14 A.

To reset the error, a charging current of 1 A (positive sign) is applied via a power supply.

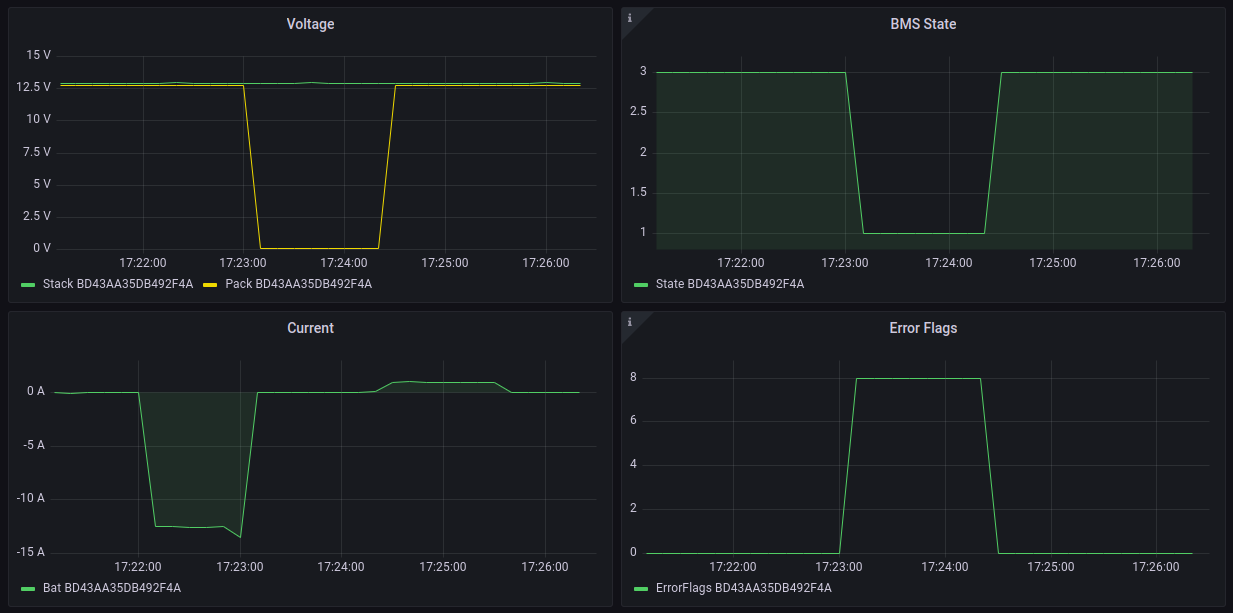
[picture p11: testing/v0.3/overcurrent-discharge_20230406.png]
Discharge overcurrent test


As shown in above picture, the discharge overcurrent is detected correctly and the BMS flags a discharge overcurrent error (8). The discharge MOSFET is disabled (state 1).

After observing the current in the opposite direction, the error is cleared and the BMS goes back to normal operation.

### 4.5 Overtemperature protection



#### Requirements

The BMS switches off the discharge MOSFET when the temperature threshold `Conf/sDisMaxTemp_degC` is reached and switches the MOSFET on again after the tempreature drops below above threshold by `Conf/sTempLimitHysteresis_degC`.

The BMS switches off the charge MOSFET when the temperature threshold `Conf/sChgMaxTemp_degC` is reached and switches the MOSFET on again after the tempreature drops below above threshold by `Conf/sTempLimitHysteresis_degC`.

#### Test description

The cell temperature sensor is heated up with a hot air gun so that it reaches approx. 50 °C. Afterwards the sensor is allowed to cool down to ambient temperature.

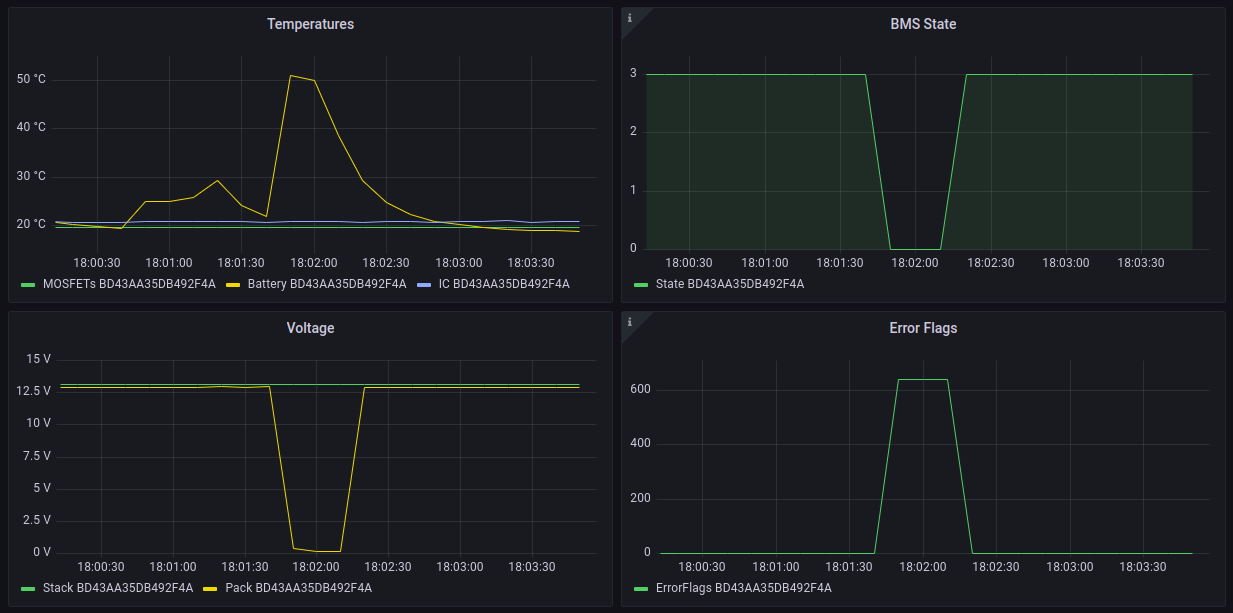
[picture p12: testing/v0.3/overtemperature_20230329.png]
Overtemperature test


As shown in above picture, the overtemperature is detected correctly and the BMS flags a discharge and charge overtemperature (512 + 128). Both MOSFETs are disabled (state 0).

As soon as the temperature drops below the reset threshold, the BMS goes back to normal operation.

## 5 Performance tests

### 5.1 Thermal performance



#### Requirements

The MOSFET and shunt temperatures should stay below 80 °C at 20 °C ambient temperature for the maximum rated current over a period of 60 minutes.

80 °C is a rather conservative requirement which may be adjusted depending on the actual application.

#### Test description

The available test equipment only allowed to sink the maximum rated current of 100 A, but not source the same amount of current. For this reason, the 20 A power supply and the 50 A power supply were connected in parallel.

As the voltages of the small power supply were unstable at 20 A, its current was reduced to 19 A, leading to a total of 69 A provided as charge current through the PACK terminals. The bi-directional power supply was connected to the BAT terminals to sink the same amount of current. The BAT voltage was set to 13 V.

#### Test results

Below graph shows the current profile and temperature rise of the internal sensors over time. The ambient temperature was approx. 18 °C.

Temperatures during performance test

Below thermal camera image shows the temperature distribution at the end of the test (after 60 minutes).

Thermal Image: Performance Test

As it can be seen, the shunt resistor is the most critical component and rises to 45.6 °C, equivalent to a delta of 27.6 K vs. ambient.

Assuming linear behavior, the expected temperature increase of the shunt resistor for 100 A can be estimated with:

$$
\Delta T_{100A} = \Delta T_{69A} * \frac{100^2}{69^2} = 58 K
$$

This means that the temperature would stay slightly below 80 °C at an ambient temperature of 20 °C.

The MOSFET internal resistance increases with temperature, leading to higher losses at higher temperatures. However, the MOSFET temperatures are only around 40 °C during the test, so there is more margin than for the shunt resistor.

The performance requirements of the BMS are met.

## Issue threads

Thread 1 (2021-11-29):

Choosing internal power supply buck regulator

EarthLord, 2021-11-29:
Some options are

- Rohm's [BD9G341](https://octopart.com/search?q=BD9G341&currency=USD&specs=0) or [BD9G500](https://octopart.com/search?q=BD9G500&currency=USD&specs=0)
- [MIC28512](https://www.mouser.in/c/?q=mic28512) available in Mouser. 2A output capability may not be enough if you want to support power for driving contactors and also a cellular modem. There are higher rating Microchip parts but they aren't available.

martinjaeger, 2021-11-29:
Hi Prithvi and thanks for your suggestions!

I'm currently considering the [TI LMR16020](https://www.ti.com/product/LMR16020), which is in stock at TI and at LCSC. There is also a 3A version (LMR16030) available.

Only problem: The 65V absolute maximum input voltage is a bit tight for 48V applications. There is also the [LMR38020](https://www.ti.com/product/LMR38020) with 80V nominal max, but it's not in stock anywhere. You can only get some pre-production samples from TI.

Compared to the proposed Rohm part, the LMR16020 has much better light load efficiency, which is quite important for this application, I think. The MIC28512-1 variant looks good as well in terms of light load efficiency. However, it has a quite unique footprint and I guess it would be easier to find a second source part for an SOIC-8 footprint (even though manufacturers seem to deliberately choose pin assignments that are incompatible to other parts, even e.g. within TI).

At the moment I'm not planning to add contactor drivers to the power PCB, as it will have the MOSFETs.

I was planning to set the power supply output voltage to 4V so that it can feed a GSM modem. The MCU and other parts of the circuit would then be powered by a low-current LDO providing 3.3V output. Do you think that makes sense?

EarthLord, 2021-11-29:
LMR38020 looks great with 45uA Iq. We had done a survey a few months ago and this wasn't available then.

65V absolute limit is a no go when considering various battery pack possibilities, especially since 15s NMC packs can reach quite close to this limit. We got some 2nd life EV packs of this sort.

Yes, we have a similar architecture of 4.2V and then an LDO for 3.3V. 4.2V because it also powers a charger IC for a backup battery. In case of this BMS, even 3.7 or 3.8V could work to reduce some loss from the LDO, depending on the dropout voltage of the LDO.

martinjaeger, 2021-11-29:
Good to know that you have 15s NMC packs. I wonder why they are 15s. Did you choose to put that many cells in series or did they come as a pre-assembled module with that many cells. As far as I know, most 48V batteries in automotive applications based on NMC cells only have 12s or 13s.

One option to be able to use a 60V-rated SMPS is to add a source follower between battery and input to reduce the voltage for such (I guess seldom) types of batteries. I've done that for the [MPPT 2420 HC](https://github.com/LibreSolar/mppt-2420-hc/) in order to allow power supply from up to 80V at the solar panel side. This will of course impact efficiency. It would be better to avoid this extra effort and have an SMPS that supports enough input voltage.

We could just try to get the pre-production sample of the LMR38020 from TI and hope that towards the end of next year it will be available from actual production. We can't really predict availability of parts anyway and whichever SMPS we choose, there will be some risk involved that it's not going to be available.

EarthLord, 2021-11-29:
The 15s pack was from the EV OEM. I guess they were aiming for 60V pack.

Yes, looks like LMR38020 is the best bet at this time.

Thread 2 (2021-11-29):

WSMS5515 as shunt resistor

EarthLord, 2021-11-29:
Two possible issue with this resistor

- 5% tolerance, although this can be mitigated by storing a calibration value in the MCU on manufacturing
- Using this resistor as a connection point for BAT- and PACK- would put quite a bit of mechanical stress on the resistor with lugs connection with 25 mm2 wires.

What value of resistance is planned to be used and is 3W power dissipation with the resistor enough?

EarthLord, 2021-11-29:
An alternative could be to use Wurth connectors for BAT- and PACK- and use a 1% SMD shunt resistor such as this [8W, 1%, 0.5 mOhm SMD resistor](https://www.mouser.in/ProductDetail/KOA-Speer/PSL2NTEBL500F?qs=5aG0NVq1C4yLtsrj1PD%252BsQ%3D%3D) with a layout like as described in this [article](http://www.analog.com/media/en/analog-dialogue/volume-46/number-2/articles/optimize-high-current-sensing-accuracy.pdf) by ADI to implement Kelvin connection.

martinjaeger, 2021-11-29:
Yep, 5% tolerance is indeed not ideal, but it could be calibrated in firmware during end-of-line check to increase accuracy.

I do agree that the connection could create stress. We could try to support the shunt using the plastic enclosure.

Based on maximum heat dissipation in the shunt (3W), the ideal value would be 300 µOhm (for 100A max. continuous current). However, this variant is currently not in stock anywhere. Mouser only has the 100 µOhm type. I've still got to check the resulting resolution for the bq76952.

The alternative SMD resistor you suggested looks good. I've used similar parts from Bourns in the [BMS 8s50 IC](https://github.com/LibreSolar/bms-8s50-ic). However, I'm a bit concerned with the 100A current pushed through one rather small SMD soldering connection. Also 8W heat dissipation seems quite a lot for such a small component without attaching it directly to a heat sink.

Many other BMSs use multiple SMD resistors in parallel, see e.g. this [Pylontech teardown](https://powerforum.co.za/topic/8524-pylontech-us2000-plus-teardown/).

Do you have experience with current in the 100A range on "normal" PCBs? Which copper thickness would you think is required for the PCB?

Thanks also for the link to the document regarding kelvin connection. I've always connected from below in the center of the resistor, but if the other connection is more accurate I'm happy to follow the paper. Might get tricky if we have multiple resistors in parallel, though.

EarthLord, 2021-11-30:
The manufacturers of the SMD resistors seem pretty confident of their capability to handle the power dissipated. For example [PSJ2NTEBL500F](https://www.digikey.in/en/products/detail/koa-speer-electronics-inc/PSJ2NTEBL500F/10396748) says the thermal resistance is 6.7 °C/W, so with say a bad ambient temperature of 50°C, a 100 A current through this will get it to 83.5°C, while still staying within the rated power.

Yes, I saw the Pylontech teardown recently too. I'm wondering how the accuracy of such a system is. The ADI article says how the soldering is done will influence the resistance quite a bit, although considering stencil and reflow soldering should give uniform current split among the resistors. The advantage of this is possible lower cost of say 8 quantity of 1%, 4 mOhm resistors than 1 of 0.5 mOhm 1% resistor of higher wattage.

The [tool to graph the error](https://www.ti.com/product/INA228#order-quality) of INA228 is interesting, if you've not seen it before. I guess something similar is also valid for bq76952 and this is important for Coulomb Counting.

We have not developed any circuitry with currents of magnitude of 100A. I'll get back here with results of testing another BMS's PDU of 2 Oz Cu and 75A continuous current.

Also take a look at LiBal's [iBMS](https://ehv.mydigitalpublication.co.uk/publication/?i=699826&article_id=3974942&view=articleBrowser&ver=html5). Its crazy what they have achieved in a 65mmx200mm board. Its capable of 100A continuous current and 200 mA balancing current.

martinjaeger, 2021-11-30:
The LiBal BMS is indeed very cool. Looks like the MOSFETs are on the bottom. I wonder how they can be attached to a heat sink.
Unfortunately, there is not much further information available. They'll probably have MOSFETs + current sensing in series on the high-side and GND is connected via one of the small connectors. Saves two high-power connections, but is not possible with bq76952. I wonder what the huge hole in the PCB on the right is for...

EarthLord, 2021-12-03:
Here's a result from a test where at the end of 12 min test the recorded temp is 80C (Flir camera shows 5C more than a Fluke thermal gun). The conditions are

- 30C ambient temperature
- 78A charging current
- IPB048N15N5ATMA1 MOSFET with Rds on max of about 5 mOhm
- Test time of 12 min
- 2 Oz Cu board

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

We'll do a longer test and get back.

martinjaeger, 2021-12-03:
Thanks for uploading the test results. So the heat dissipation should be around 5 Ohms / 6 * 2 * (80A)^2 = 10.6W, which is quite similar to the configuration mentioned in #3 at 100A. So it looks promising in general. Did you have any heat sink / spreader attached at the bottom or was it just in free air?

EarthLord, 2021-12-04:
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

There are two bus bars at the bottom and it was in free air.

martinjaeger, 2023-04-15:
The chosen SMD shunt performs well for 100A, see test report.

Closed 2023-04-15.

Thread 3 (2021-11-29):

Necessity for two WP-BUCF connectors in parallel?

EarthLord, 2021-11-29:
Two Würth WP-BUCF power connectors are planned for Bat+ and Pack+ each. The possible issues with this are

- majorly the increase in cost for 2x of these costly connectors
- Lugs are designed in such a way that the bottom surface is made completely flat and thus provide max contact with terminal block. The 180 degree flip of one lug may not provide enough contact.
- Also depending on torquing of the screw, the resistance of connection would vary, thus not splitting the current in half.

An alternative would be to use one of [7461383](https://octopart.com/search?q=7461383&currency=USD&specs=0) only such that it can handle all the current with its greater mating points with PCB and it is also sightly less expensive. For applications with vibrations it'll also be easier to apply thread lock glue.

If some space can be made at the corner of the PCB by moving the RJ45 connectors, M6 part also could be an option.

EarthLord, 2021-12-01:
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
A possible option would be to use parts from [Lugs Direct](https://lugsdirect.com/PCBsolderable-lugs.htm). The wires would have to use [these kind of termination](https://www.swaonline.co.uk/cable-terminations/copper-pin-terminals/uninsulated-reducing-pin) in order to use them, bare wires get corroded and increase resistance.
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

In an upcoming BMS from another vendor we'll be using [B2C-PCB-PT-HEX](https://lugsdirect.com/heavy-duty-pcb-terminals-pt-pcb.html) (shown in pic above). These particular connectors are used in APC inverters. It is rated to 115A and there are other connectors with higher rating with the same company.

As for as the connector in your screenshot, the max I've seen on [Aliexpress](https://www.aliexpress.com/item/32758412452.html) is M5 screw based that is supposedly rated upto 100A.

Yes, it makes assembly simpler with soldering than press fit, which is important for an open source project.

martinjaeger, 2021-12-01:
I'm currently checking out a new approach which avoids the expensive terminals completely. The idea is to use a custom-made (yet simple) copper bus bar of e.g. 2 mm thickness with a clinch nut pressed in from the back. The bus bar would be soldered directly onto the PCB and can spread the current as well as heat.

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

By using only SMD parts, we have a plain surface at the bottom which can be easily attached to a heat sink. It would need some milling to provide space for the clinch nuts, though. Maybe even a thick aluminum heat spreader is sufficient for cooling purposes, if e.g. attached to a housing outside wall.

This suggestion addresses some of the other points raised by @EarthLord aswell.

Ideal MOSFET in terms of heat dissipation would be [IPT015N10N5](https://www.infineon.com/dgdl/Infineon-IPT015N10N5-DS-v02_02-EN.pdf?fileId=5546d4624a75e5f1014ac94680661aff), where 4 in parallel should be sufficient. Rds(on) at 80°C is max. 2 mOhm, leading to a total of 1 mOhm (4p2s) and 10W of heat dissipation at 100A.

There are cheaper alternatives with higher Rds(on), also from other manufacturers.

EarthLord, 2021-12-02:
Looks great in many aspects - components assembly, connection of lugs, lowering resistance between MOSFETs and connectors, lower PCB copper thickness requirement and aesthetics. If needed the length of the board can be increased to have either 1. more spacing between the MOSFETs for better thermal performance or 2. make it 5p2s with maybe some DNP if its a lower rated requirement. H1, H2, H3 holes for attaching heat sink is also a good idea!

Feedback from our mechanical engineer - thing you've to keep in mind is not to use steel clinch nut with copper. They have different hardness and thermal expansion. So steel clinch nut won't be secure for longtime over multiple thermal cycling. Copper clinch nut on the other hand would be good, if they can be found.

martinjaeger, 2021-12-06:
> Feedback from our mechanical engineer - thing you've to keep in mind is not to use steel clinch nut with copper. They have different hardness and thermal expansion. So steel clinch nut won't be secure for longtime over multiple thermal cycling. Copper clinch nut on the other hand would be good, if they can be found.

I talked to [KVT](https://www.kvt-fastening.de/en/products/brands/pem/) about above point and they don't see any issue with different hardness and thermal expansion. The stainless steel nut (CLS variant) is suitable for copper and aluminum material. It is used in multiple different high-current applications. Also the old Tesla model S battery (and potentially newer ones as well, but I don't know) uses a clinched nut in a copper shunt.

photon-delight, 2022-02-19:
> The bus bar would be soldered directly onto the PCB and can spread the current as well as heat

How would these bus bars be soldered?

martinjaeger, 2022-02-25:
> How would these bus bars be soldered?

The idea is to solder them together with other components during the reflow process.

I have changed the design of the busbars to have press-fit studs instead of press-fit nuts because it avoids milling of the heat sink and it should also be easier for assembly because the cable lugs are kept in place already without the bolt. You can find an updated image in the main Readme of the repository.

Closed 2023-04-15.

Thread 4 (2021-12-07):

Plan for board to board connections

EarthLord, 2021-12-07:
What would be the plan for board to board connections? As I can see one would be for BMS <-> PDU and other would be for BMS <-> wireless communication board.
Is the plan to use direct board to board connection or with a cable, say FRC cable in between?

martinjaeger, 2021-12-07:
That's exactly what I've started to work on yesterday. I'm currently thinking of a simple pin header between power board and control board.
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

For connection of the comms board I'd suggest to use the UEXT connector, which works both with ribbon cables or a direct pin-header connection. A GSM board would need an additional power connector (e.g. JST XH or PH) as the ribbon cables are too small for 2A over a longer distance.

I'm also considering to remove the RJ45 connectors from the board and route CANH and CANL into another MicroFit type connector. The RJ45 jacks should be accessible from the outside of the battery housing. Having them directly at the board of the BMS would restrict the design of the battery housing quite a lot.

What do you think?

EarthLord, 2021-12-09:
For UEXT connector board to board mounting, you are planning to use generic 5x2 female pin header?

Considering that UEXT standard specifies 3.3V for power, 4V can't be used for GSM communication anyway too. Like you said, a thicker wired 2 pin connector for 4V can be used present in case a module needs it.

With respect to BMS <-> PDU, would it be good to also have the possibility to have an option to mount the two separately, not one on top of other? Especially considering the PDU can heat up and this can affect the BMS in terms of accuracy and balancing current.
For this maybe a UEXT connector model would work for BMS <-> PDU?

With respect to CAN, yes a MicroFit type of connector makes more sense for the reason you mentioned.

martinjaeger, 2022-02-25:
I've had lots of back- and forth thinking for the connection between the control PCB and the power PCB and finally decided to go with two rather simple 1x6 pin sockets/headers with 2mm pin pitch.

Control PCB:

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

Power PCB:

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

## Reasons

- Cheap solution compared to other board-to-board connectors
- Stacking height is lower than with 2.54 mm pitch connectors (approx. 8 mm total)
- There was no space in the middle of the control PCB because of balancing resistors, etc.

Unfortuntately the connectors on the top PCB require an additional THT soldering process, but I did not find any viable solution for reflow soldering on top side. Bottom-entry sockets [like this one](https://www.we-online.com/katalog/de/PHD_2_54_SMT_DUAL_SOCKET_HEADER_BOTTOM_ENTRY_6100XX243021) are very expensive and require longer than normal pins at the bottom side.

BTW: All other parts on the top PCB are SMT. Only the optional UEXT header and the additional 5V aux. power supply connector are THT, but they will not be needed in many applications. The programming connector is press-fit (will post another issue with more details).

## Considered alternatives

- Flat ribbon cable -> not ideal from EMC perspective as the current sense connection should be as short and close to the BMS ASIC as possible.
- FPC -> similar issues as with flat ribbon cables
- Other board-to-board connectors: Usually very short distance between PCBs so that the MOSFETs and busbars of the bottom PCB don't fit anymore.

EarthLord, 2022-02-28:
Lots of valid points, makes sense to have this solution that you've proposed. Would it be better to have the two connectors next to each other so that FRC is also an option when developing/debugging when both boards need to be accessible?
Which means it'll be a dual row connector on both the sides and it'll be 2.54 mm pitch which increases the height too.
The other option is building a custom cable for the two 1x6 connections when debugging if needed when the two boards can't be stacked.

photon-delight, 2022-02-28:
I'm a bit concerned about the strength of these SIL SMD headers on the power PCB.  I would be more inclined to use  DIL SMD headers as they would be a bit more resilient against lateral force, and there seems to be enough space on the power PCB.  I understand that the two boards are mechanically secured using the 3 standoffs, but it would reduce the fragility of this PCB before being mechanically secured.

b0661, 2022-02-28:
Some thoughts about production when looking at the pictured boards:

- Usually you take the "long" side of a board to support in pick & place and soldering. One "long" side is only half, which is not optimal for mechanical support during production.
- Some of the components are very close to the board border which increases the risc of breakage during production. Also if you panelize several boards this is a risk of failure due to mechanical stress when cutting the boards .
- Are the board cutouts really necessary? Boards without cutouts are usually cheaper.
- There is only one fiducial in the picture, at the edge of the board (None on the power board?). Fiducials should (also) be placed near to the high density components. There is a higher risk of misplacement by one pin.

martinjaeger, 2022-02-28:
Thanks for all your feedback.

@photon-delight Would you suggest two 2x3 pin headers instead of the two 1x6 pin headers? Wouldn't they also have 6 legs soldered to the PCB, so the maximum lateral force would be the same?

@b0661

> * Usually you take the "long" side of a board to support in pick & place and soldering. One "long" side is only half, which is not optimal for mechanical support during production.

What do you mean exactly by long side? Do you mean that the ratio between long and short side is high for the power PCB so that it could bend?

> * Some of the components are very close to the board border which increases the risc of breakage during production. Also if you panelize several boards this is a risk of failure due to mechanical stress when cutting the boards .

Good point, the one large MLCC is really close to the edge. I'll try to move it further inside. In general the space was quite limited in some locations so that I couldn't keep much space at the edges.

> * Are the board cutouts really necessary? Boards without cutouts are usually cheaper.

Yes, I think they are necessary. The board height is limited to 65 mm so that it can fit at the end of a pack with typical 18650 Li-ion cells. Thats also why all connectors have to go out at the short sides of the PCB. The ESP32-C3 module antenna is best placed at the board edge, so we need to cut out the board in order to stay below the maximum height of the assembly. The smaller cut-outs next to the cell connector are necessary for the tool of the nuts for the cable lug.

> * There is only one fiducial in the picture, at the edge of the board (None on the power board?). Fiducials should (also) be placed near to the high density components. There is a higher risk of misplacement by one pin.

There are 2 fiducials on each board, but they don't have a `FID` marking. I actually forgot to make the `FID1` marking invisible because I don't think they need an identifier.

martinjaeger, 2022-02-28:
> Lots of valid points, makes sense to have this solution that you've proposed. Would it be better to have the two connectors next to each other so that FRC is also an option when developing/debugging when both boards need to be accessible? Which means it'll be a dual row connector on both the sides and it'll be 2.54 mm pitch which increases the height too. The other option is building a custom cable for the two 1x6 connections when debugging if needed when the two boards can't be stacked.

Probably we'd have to build a custom cable for debugging, as also the signals in the top and bottom connector are chosen such that they are close to their source/sink (e.g. discharge MOSFET side or charge MOSFET side), so they don't have to be routed across the entire board.

Light411, 2022-03-04:
Hey,

I do share concerns with what have been said above regarding the pin headers.
Have you considered pogo pins ? It has some perks, as it won't suffer from lateral forces and will have less chances to get teared out on the long term.
This is what I used to replace most of my headers in mezzanines and I'm really have with it. You basically separate the mechanical constraints from the electrical contact which is great.
https://www.mouser.fr/ProductDetail/Mill-Max/0906-0-15-20-76-14-11-0?qs=DGF5YW3GH8vs5H4c8CyXhQ%3D%3D

martinjaeger, 2022-03-11:
I have now updated the footprint such that the pad is below both sides of the connector. This allows to use parts with pin 1 left or right and in addition to that increases rigidity a bit as the pad size is bigger.

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

I'll try this out for the first batch and if it is not sufficiently stable we can use the 2x6 connector instead.

The pogo pins as suggested by @Light411 are quite expensive IMO. Also they don't seem long enough to cover the required distance between the board, so I'll keep that in mind as a backup solution if the current solution does not work well.

martinjaeger, 2023-04-15:
Board-to-board connections are not required in most recent design anymore.

Closed 2023-04-15.

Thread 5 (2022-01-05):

Footprints for thermal jumpers?

EarthLord, 2022-01-05:
Add footprints for thermal jumpers such as 0612 variants of [THJP series by Vishay](https://www.vishay.com/docs/60157/thjp.pdf)? The footprints can be from the common drain points of the MOSFETs and send heat to their source planes as well. They can be populated if necessary for additional heat sinking.
This [video by EEVBlog](https://www.youtube.com/watch?v=q3RhWuXFixU&t=782s) was where I got my insight into this interesting part.

martinjaeger, 2022-02-25:
Hi @EarthLord. Thanks for the suggestion.

I've just uploaded some thermal calculations for the heat sink. At least for the MOSFETs the transfer from the MOSFETs to the PCB and to the heat sink is not an issue. The thermal bottleneck is more the heat transfer from the heat sink ambient. So for applications with 100A requirement, the BMS will have to be thermally attached to the battery housing to transfer the heat out of the enclosure.

The shunt resistor is more critical in terms of temperature increase (as you also mentioned via e-mail). However, I hope that the bus bars will act as heat spreaders and improve the heat transfer towards the heat sink. As this is 3-dimensional heat transfer, it is more difficult to estimate, so I will have to do some testing.

EarthLord, 2022-02-25:
Okay yes, looks like shunt will get more toasty. Looking at the power derating curve of the [shunt resistor](https://www.koaspeer.com/pdfs/PSJ2.pdf), it looks like at higher current the temp increases which further decreases the power rating.

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

How about a shunt like one in this pic from Seplos BMS? I don't have any part numbers for this yet.

EarthLord, 2022-02-28:
I am unable to get the part number for shunt like the one in the pic above, which seems apt as it'll remove the need for bus bars as well for the -ve terminals as well as have better thermal performance. Its from [Seplos BMS](https://www.seplos.com/sale-13707067-can-bus-rs485-48v-200a-5-500ah-8s-16s-lithium-iron-phosphate-lifepo4-bms-monitoring-system-battery-m.html) where they are using this shunt for up to 200A.
It shouldn't be too expensive too since they are selling a BMS at 125 USD at single quantity.

martinjaeger, 2022-02-28:
The thermal performance could even be compared without a board change, as the WSBS8518 needs to be mounted somewhere outside the board anyway. It exceeds the maximum board height of 65 mm defined by the 18650 cells. The one in the Seplos BMS looks shorter, but I couldn't find any comparably small shunt resistor either during my previous research.

The problem with the solution with these large shunt resistors is the additional cost for the screw terminals on the PCB and that the Kelvin connection to the board is somewhat tricky.

Maybe we just need to go for 0.3 mOhm if the 0.5 mOhm SMD resistor gets too hot.

martinjaeger, 2022-03-10:
I won't add the thermal jumpers or the shunt resistor for the first batch, but we'll keep this open in case testing shows that performance of current design is not sufficient.

martinjaeger, 2023-11-02:
Testing showed that 100A work well without thermal jumpers.

Closed 2023-11-02.

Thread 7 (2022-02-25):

Choice of ESP32 variant

EarthLord, 2022-02-25:
C3 Mini module of ESP32 is chosen. Any reason for C3 vs say S2?

martinjaeger, 2022-02-25:
It's mainly due to space constraints. The "larger" ESPs are not available with a small footprint module. And compared to the STM32G0B1 the ESP32-C3 is still more powerful.

Would you have any particular use case which requires an ESP32-S2?

martinjaeger, 2022-02-25:
I just see that the S2 doesn't even have Bluetooth, which is the main reason for me to have ESP32 support.

Also I kind of like that the ESP32-C3 has a RISC-V core :)

EarthLord, 2022-02-25:
Sounds good. Just asked to understand your decision process. Yes, was quite a pleasant surprise when ESP32 C3 came out with a RISC-V ISA based core.

Closed 2022-02-28.

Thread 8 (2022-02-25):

Connector for programming

martinjaeger, 2022-02-25:
In previous designs I usually used normal 2.54 mm pin-pitch headers for programming. However, it is often quite tricky to connect the pins correctly with jumper wires during testing and even more for re-flashing in the field during prototype evaluation.

As a solution, there is the [Tag Connect](https://www.tag-connect.com/), which is widely used in the industry. However, it's around 40€ for a simple cable, which is available from a single vendor only.

Würth offers a [2.54mm pitch press-fit connector](https://www.we-online.com/catalog/en/REDFIT_IDC_SKEDD), which can be used with standard ribbon cables. The connector can be mounted permanently or it can be used temporarily for flashing and debugging only (using slightly larger hole diameters). There is also a [white-paper about use of this connector for debugging](https://www.we-online.com/catalog/media/o181100v410%20ANE004%20REDFIT%20IDC%20SKEDD%20Connector.pdf).

The connector is available e.g. via Digikey. I didn't look for compatible second sources, yet. However, also two normal 2.54 mm pin header rows could be soldered to the footprint to interface with jumper wires as a quick workaround if someone doesn't have the connector.

I suggest the following pinout:
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

A reset pin is not needed for SWD, as the MCU can be reset via the SWD interface itself. This leaves space for a serial interface for debugging in a 6-pin connector.

Let me know if there is a preference for a changed pinout. The boards are not ordered, yet.

CC @EarthLord

EarthLord, 2022-02-25:
Although we use Tag Connect, I agree that its quite costly for a simple cable. Würth connector is quite interesting, only somewhat bigger. Also I recently came across this idea for a programming connector, quite ingenious. Thoughts?
https://avdweb.nl/arduino/misc/mini-isp-connector

Once I had an experience where after entering deep sleep with STM32 I couldn't program it again without the reset pin. So maybe have reset instead of 3.3V? In any case the board can get power supply from elsewhere - even UEXT connector in the rare scenario where the board is not powered from a battery and it needs to be programmed/debugged.

If you can confirm reset isn't needed to program in any sleep state, then the current pinout is fine.

martinjaeger, 2022-02-25:
Ok, thanks for the insight regarding your issues with the reset from deep-sleep. So we should at least break out the reset pin to a test point so that it can be reached during debugging, just in case.

Unfortunately, the voltage pin is needed. It is not for powering the board, but for the programmer to detect the system voltage. As far as I understand, it is mandatory e.g. for Segger J-Link and also the STM32 nucleo boards have it.

The zigzag connection is neat, indeed. I knew the zigzag footprints as a soldering aid from Sparkfun Eagle libraries, but for programming it's also a nice idea.

I also like this one: https://hackaday.com/2016/02/08/local-hacker-discovers-card-edge-connectors/

But inside an enclosure the board edge may be hard to reach, so accessing it from the top is a must, IMHO.

martinjaeger, 2022-02-25:
Here is another [edge-connected solution](https://hackaday.com/2020/11/28/this-debug-connector-brings-your-issues-to-the-edge/) with an open standard: https://debug-edge.io/

It confirms that SWD cannot be used without the voltage pin (see the 4-pin version).

EarthLord, 2022-02-28:
Yes, the voltage sensing is needed for a programmer/debugger, although I usually connect this sensing pin to the 3.3V from the programmer itself, especially with nRF-DK boards to trick the programmer to think the power is fine.

As you say if accessing from top is needed, we can do the zig-zag pattern?

martinjaeger, 2022-02-28:
Yeah, I think I'll actually switch to normal pin header with zig-zag. I like the idea.

I'd probably keep 2.54 mm pin-pitch headers, though. The link you posted above seems to have 1.27 mm pitch. What do you think?

Maybe I'll just leave out the serial, so that one has to take the serial from the UEXT connector for debugging. It would leave us with a 5-pin single-row header, which is small enough.

EarthLord, 2022-02-28:
Regarding the pin header pitch, not sure if 2.54 mm one is be harder to insert in zig-zag because it is thicker and not as easy to bend. Its a small risk to figure out the zig-zag offset for 2.54 mm pitch. If there is space, can be experimented in first version.
Also, leaving the serial on UEXT for GSM would be good, so a UART dedicated for debugging/manufacturing would be useful.

martinjaeger, 2022-03-15:
I have switched to normal 2.54 mm pin headers now in order to get started with something that definitely works. I kept the debug serial as well.

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

For the zig-zag placement I'll maybe make a separate test board with multiple different hole patterns, but it's not top priority at the moment.

Closed 2023-10-09.

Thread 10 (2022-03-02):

Creepage distance Battery voltage

JochenKr, 2022-03-02:
The creepage distance for the battery voltage is only 0.3mm to GND.
To reduce the risk of arcing, it makes sense to increase the distance to at least 0.7mm in respect to IPC9592.

example:
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

martinjaeger, 2022-03-10:
Swapped the pins and increased the GND plane gap on top layer from 0.3 mm to 0.5 mm:

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

You suggested 0.7 mm, which would make quite a few GND planes on the top layer disappear. I'm wondering if 0.7 mm is only required for dirty / moisty environment, as it is violated by the IC anyways:

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

PDSG pin is pulled up to the battery voltage during normal operation and it's right next to a GND pin:

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

martinjaeger, 2022-03-15:
The influence of the impedance makes sense.

I've swapped the pins as suggested and increased the gaps to 0.5 mm for now. Leaving this open so that future revisions can be further improved.

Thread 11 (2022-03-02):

Ground on BQ76952

JochenKr, 2022-03-02:
The ground loop around the IC can be improved.
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

the best would be to have a solid GND plane below the IC. This seems not to be easy.
An improvement could be to put TS3 signal to bottom layer. By this there is a solid connection of GND on top layer possible,
By slightly moving RST_SHUT and TEMP4 it is possible to add two additional vias in that area to connect the planes.
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

martinjaeger, 2022-03-03:
Good spot. I also realized that the routing around the IC with the many traces in the bottom layer is not ideal. But also didn't want to go for a 4-layer PCB just because of that. I'll try to move things around a bit so that the top plane bridges the gaps created by the traces in the bottom plane better.

martinjaeger, 2022-03-10:
After watching [this amazing video](https://www.youtube.com/watch?v=ySuUZEjARPY&ab_channel=Altium) as recommended by @Light411 I finally decided to switch to a 4-layer PCB. I thought I'd get away with the cheaper 2-layer version, but routing around the IC proves to be really difficult. I guess the small cost increase will be worth the improved performance.

Light411, 2022-03-11:
Super happy that it was helpful ! I'm sure it will greatly improve the ground loops issues.
What layer stack-up will you choose ? Will you do

- Signal
- Ground
- Ground
- Signal

as suggested by Rick, with a routed VCC ?

martinjaeger, 2022-03-11:
Yes, exactly. I was previously mostly using:

- Signal
- Ground
- VCC (3V3)
- Signal

But after watching his video it seems to make more sense to have two GND layers and a routed VCC. Maybe the VCC can be partly flooded on the bottom layer, otherwise there would be very few traces only.

Closed 2022-03-15.

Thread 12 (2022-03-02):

Gate protection diodes of Mosfets

JochenKr, 2022-03-02:
The protection Z-diodes and pulldown resistors might not help against transients, as they are not close to the gates of the Mosfets.
For the case that transients occur, it might make sense to have a second pair of z-diodes for the left side Fets.

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

martinjaeger, 2022-03-11:
Done. Will be updated in next commit.

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

Closed 2022-03-15.

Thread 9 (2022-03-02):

5V Buck converter

JochenKr, 2022-03-02:
Noise on the Vcc of 5V supplied devices should be better if the GND is connected on the output caps of the buck converter.
An additional 0603 100nF Cap on the output side could improve noise on the 5V.

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

EarthLord, 2022-03-03:
Yes, also for all decoupling caps it'll be good to have vias close to its GND pad to reduce inductance. Page 29 of this slide has the recommendations https://web.mst.edu/~jfan/slides/Archambeault1.pdf

Its great to see the tight input-output and diode-output loops of the buck regulator :)

martinjaeger, 2022-03-03:
For the connection to GND I was roughly following the TI recommendations in the [LMR16030 data sheet](https://www.ti.com/lit/ds/symlink/lmr16030.pdf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):

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

In the datasheet of the LMR33630 it is even made more clear that they suggest to place the ground connection close to the IC and not close to the caps:

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

I've had devices with the LMR33630 in the EMC lab and they were perfectly fine, so I took a similar approach here.

In my understanding it is most important to have a **single** connection between the power supply GND and and the GND plane of the circuit. We could probably also place it close to the capacitors, but in that case we'd have to cut the plane on the top layer close to the U2 marking in order to avoid two different paths.

For the output side a smaller cap for high-frequency noise is probably not as important as for the input side, but looks like there is enough space, so I'll add one.

JochenKr, 2022-03-03:
Probably they did it to cool the IC?

It's definitely not urgent, especially as the currents will be very low.
I agree that the best solution should be to have one single GND connection.

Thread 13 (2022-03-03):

Thermal performance of balancing bleed resistors

EarthLord, 2022-03-03:
BQ76952 has 100 mA balancing current, relatively less. In any case, since the control board is small, just wanted to check if any rough thermal analysis was done on this matter?

martinjaeger, 2022-03-03:
Good point. I did thermal camera shots with the bms-8s50-ic in the past and the temperature increase was very low, something around 40°C at 20°C ambient. But it was a 4-layer PCB and the resistor value was 33R, so the situation will be a bit different here. I'll double-check and potentially try to add a bit more copper below the resistors.

martinjaeger, 2022-03-10:
As mentioned in the other PR, I'm switching to 4-layer PCB. In addition to that I added large pads on the top and bottom layers connected through thermal vias to spread heat, see below:

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

The picture doesn't show the two inner layers which provide another copper pour for heat spreading. This is very similar to previous designs and I'm confident it will provide enough heat removal.

martinjaeger, 2022-03-15:
Closing this now as I don't think there will be any issue with the updated design anymore. If testing shows different results we can re-open the issue.

Closed 2022-03-15.

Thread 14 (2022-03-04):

Voltage rating of D1 and D2 in bms-power-100a

EarthLord, 2022-03-04:
Considering we can use 16s NMC cells too, it would be better to get the 64V or next higher Reverse Stand off Voltage Vr rated SMC TVS diode in bms-power-100a boards for D1 and D2.

martinjaeger, 2022-03-10:
Currently we cannot use 16s NMC cells because of the limited voltage range of the power supply.

SMCJ70A have a maximum clamping voltage of 113V, which is beyond the rating of the MOSFETs. So we'd probably have to choose different TVS diodes and MOSFETs depending on the maximum number of expected cells. For usual 48V applications with 60V max the SMCJ60A are the right choice, I think. Do you agree?

EarthLord, 2022-03-11:
Oh, just saw that LMR16030 is only up to 60V. Would it be good to limit the number of cells usable with NMC just because of the power supply?
We have got supplies of 15s NMC packs, not 16s as of now. So it would be good if at least 15s NMC is supported. Unfortunately as you mentioned earlier, these SOIC parts aren't pin compatible.

For power supply some options that I can think of are

- Move to LMR38010 which is available and pin compatible with LMR38020. With this approach we can
  - support higher cell count with NMC
  - replace with LMR38020 when it becomes available and then GSM can be supported as well. Before that we can figure out external supply for development
  - TVS can be moved to SMCJ70A to support higher number of cells. With max clamping of higher voltage, yes the protection is reduced. For small power spikes, this 1.5kW TVS can work too, although there are 5kW and 8kW TVS in the same package too, which will offer better clamping if the developer thinks the application would experience higher spikes.
  - MOSFET could be 100V Vds for now I guess.
- Other option for higher input voltage options like we discussed in this https://github.com/LibreSolar/bms-16s100-sc/issues/1 What about the Rohm parts in there?
- Or LMR16030 for the first version and then hope there's better alternatives for the 2nd version so that higher num of cells can be catered to. Only thing is that it'll be an untested part of the 2nd version.

martinjaeger, 2022-03-11:
I'm afraid that the only viable option right now is to wait for the LMR38020 to become available and till then use the LMR16030.

- The LMR38010 seems to be a very new part (didn't know it before) and it is only available in TI stock, but for some reason I'm not able to order at TI, at least it was not possible in the past. They seem to ship only to distributors or US companies.
- As discussed before, the ROHM parts have bad light load efficiency, so they are not suitable for a BMS.

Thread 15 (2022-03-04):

Option for CAN bus split termination

EarthLord, 2022-03-04:
Can a split CAN termination be added with DNP marking so that there is an option to add this if needed

martinjaeger, 2022-03-10:
As far as I know, there is no SOIC-8 transceiver with standby pin, 3.3V I/O and split termination due to lack of pins.

Apart from that, I think it is necessary to leave termination to the application where the BMS is embedded into. If we add the termination to the PCB, how can we have multiple BMSs in parallel? Would we need to have different PCB versions with and without termination so that the ones in the middle of a bus would not have the termination resistors?

Victron and several other manufacturers use termination connectors which can be plugged into the first and last device of the daisy chain. Maybe these connectors can also have a basic form of split termination if they have a GND pin.

EarthLord, 2022-03-10:
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
Pic from this [TI article](https://e2e.ti.com/blogs_/b/industrial_strength/posts/the-importance-of-termination-networks-in-can-transceivers)
For split termination just GND of CAN transceiver is needed, right? Why would standby pin, 3.3V I/O be needed?

Yes, its a valid point that when multiple BMS are used or when other CAN devices are used, can termination can be designed according to the application. In any case if the footprint is there in the PCB, since it is an open source board if the developer wants, there is an option to populate the termination resistors. It adds to the flexibility the board offers.

In your schematic it is a Do Not Populate (DNP) part which is left open by default.

martinjaeger, 2022-03-11:
I meant that e.g. the TJA1042 transceiver we are using is available in a special variant for split termination, see [datasheet](https://www.nxp.com/docs/en/data-sheet/TJA1042.pdf), which stabilizes the voltage at 0.5 * VCC. However, the variant with split termination is only available for 5V I/O. If you want that spit pin + 3.3V I/O + standby, a larger package with >8 pins is needed.

Probably the split termination without the dedicated split pin is still better than standard termination, so we can consider it.

The space around the CAN transceiver and connector is pretty packed. I'll see if I find some space and if yes I can add the parts as DNP (as suggested).

EarthLord, 2022-03-11:
Thanks Martin. Didn't know of the Split potential output feature of transceivers, good to learn.

martinjaeger, 2022-03-15:
I didn't find the space for the 3 additional components without lots of shifting of other parts, so I'll leave this enhancement for a next revision.

martinjaeger, 2022-08-27:
Split termination was added in new design:

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

Closed 2022-08-27.

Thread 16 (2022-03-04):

Via for all decoupling caps to GND layer

EarthLord, 2022-03-04:
For all the decoupling caps in the project, it would be good to have one or two via to GND in layer 2 to have low inductance from capacitor GND pad. This is as described in https://web.mst.edu/~jfan/slides/Archambeault1.pdf especially page 29

martinjaeger, 2022-03-15:
Thanks for the link to the presentation. Very interesting.

I don't agree, though, that the top right one is **always** the best solution:

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

In the presentation the GND connection from the cap always goes to the GND plane and afterwards to the IC, which may be relevant for BGA packages. For packages with pins I would usually place the caps such that there is no via between the cap and the IC at all. The via is only used for topping up the cap with energy. This means that in order to make sure current for the IC only comes from the cap, the vias to supply the caps must be on the opposite side of the cap than the IC, so that the cap cannot be bypassed.

Here is an example for the CAN transceiver:
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

The 3V3 supply is probably ideal, whereas the 5V corresponds more to the "ugly" in the picture. However, I doubt that the "better" placement would make any difference. If it does, please let me know why.

Normally I do put vias very close to all decoupling caps, just not below the cap as this would require smaller via sizes and increase production cost. Did you spot any cap that was particularly flawed in terms of connection to GND / supply rail plane?

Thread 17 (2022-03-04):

Tracks running under Y1 resonator

Light411, 2022-03-04:
I do see two tracks running under Y1. I think it is possible to pull it a bit apart from the MCU to make sure there is no tracks beneath it.
I've read that the good practice is to have ground keepout under the crystal / resonator, with a ground island dedicated to the resonator and a via fence surrounding this ground island.
This helps protecting surrounding signals and prevent unwanted capacitance to disturb the crystal.
I would also suggest to have symmetrical tracks for Y1 to the MCU.

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
This is one of my most recent attempts at routing a crystal and taking these consideration into account.

martinjaeger, 2022-03-15:
Thanks for the valid comment. I've made the two traces with equal distances now and added some GND guard around the resonator.

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

Completely removing all traces close to below the resonator was not easily possible, but as the board has 4 layers now I don't think there will be any cross-talk through the layers.

Closed 2022-03-15.

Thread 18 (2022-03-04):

How to better stitch the ground plane ?

Light411, 2022-03-04:
I do have a concern regarding the bottom tracks that kind of break your ground plane apart.
I understand the routing constraints here, as it is a 2 layer PCB, but you should consider adding more via stitching from top to bottom to permit return currents to cross this ground plane discontinuity.

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

martinjaeger, 2022-03-15:
Board is now 4-layer with two inner layers being GND. There should not be any issue with interrupted GND plane anymore.

Closed 2022-03-15.

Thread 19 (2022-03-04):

U1 regulator might get hot

Light411, 2022-03-04:
It looks like it doesn't have a solid copper pour beneath it to share the world its heat :)
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

martinjaeger, 2022-03-15:
Added a copper plane for the 5V rail:

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

In addition to that, the board is now 4-layer, which will improve heat spreading as well.

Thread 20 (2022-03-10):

What dose this P-MOSFET do?

shivanshumahim, 2022-03-10:
Hi,
I am trying to understand the significance of this P channel MOSFET (Q9) in the Power section of the BMS.
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

I want to understand it's significance in both charging and discharging condition. I made a Falstad simulation with 1 discharge N MOSFET (Q5) and the P MOSFET. Relevant switches can be used to put the simulation in Charging/Discharging mode.
Simulation is in this [link](https://www.falstad.com/circuit/circuitjs.html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).

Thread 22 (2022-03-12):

Internal power supply paths

martinjaeger, 2022-03-12:
There are multiple options for the internal power supply of the BMS IC and the MCU. This issue collects some ideas and describes the current implementation.

The power supply has to fulfill the following features:

1. Not damage any parts of the circuit if the cells are connected before there is a solid GND connection through the BAT- wire.
2. The internal power supply shall not influence the cell voltage measurements (i.e. ideally not go through the balancing wires).
3. The system must go into a defined and safe state if the BAT+ wire is not connected (e.g. because the fuse between the BMS and the top-most cell is blown).

I have re-wired the cell connector such that there is an additional GND wire (also going to negative terminal of the first cell). This wire provides the GND connection for the BMS and is required according to the bq76952 datasheet (point 1 from above).

If the BAT+ pin is not connected, the MCU will currently not be powered and the bq76952 chip should stay in a low power mode. Other options would be to power only the MCU, but put it into a low power (emergency) mode, supplied from Cell 16+ through the balancing wire. There are some stuffing options and 0R resistors on the board for experimentation with different power supply paths.

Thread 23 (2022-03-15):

Via stitching between layer IN1 and layer IN2

Light411, 2022-03-15:
Hey Martin,

4 layers clearly made a difference :)
May I suggest you to add some more GND vias to better stitch your 2 internal ground layers ?
You do have quite a lot of signals transitioning from top to bottom but the return path has to also find it's way between In1 and In2 to follow the signal. You do have some spare space under U3 IC to add some extra GND vias, and also under and around U4.
This way you will make sure that at medium frequency, the return path will still be on the right GND plane at the closest to your signal, both on the top and bottom side.

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

martinjaeger, 2022-11-11:
Fixed with new v0.3 board design (now called BMS C1).

Closed 2022-11-11.

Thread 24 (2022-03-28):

C39 must be 100V and larger package

martinjaeger, 2022-03-28:
It exposed to battery voltage and should not be the usual 0603 50V type.

martinjaeger, 2022-08-27:
The power supply options of the bq chip are not used anymore in the new design. Issue is resolved.

Closed 2022-08-27.

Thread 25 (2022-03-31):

Power PCB: R2 has wrong package

martinjaeger, 2022-03-31:
Should be TO-263 and not TO-252.

EarthLord, 2022-05-13:
There are TO-252 based resistors as well. What load capacitance are you using to calculate the wattage of precharge resistor?

martinjaeger, 2022-05-13:
I assumed 5 mF bus capacitance and 60V.

Just realizing that the datasheet does actually say DPAK style: https://www.bourns.com/docs/Product-Datasheets/PWR163.pdf

It's definitely considerably larger, so I'll double-check the footprint dimensions.

martinjaeger, 2022-08-27:
Package is fixed in new revision.

Closed 2022-08-27.

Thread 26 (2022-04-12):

Switching off with button does not work

martinjaeger, 2022-04-12:
The TS2 / WAKE pin of the bq76952 is only pulled up during shutdown mode, but not during operation. Thus, the MCU cannot detect if the button is long-pressed to put the battery pack into sleep mode.

Even though the TS2 pin is a multi-purpose pin, it cannot be configured as an output, but only as a general purpose ADC input.

We need something like an additional external pull-up to the 3V3 rail.

EarthLord, 2022-05-13:
Not sure if I understand this situation completely, wouldn't the internal pull up on STM32 help?

martinjaeger, 2022-05-13:
You are right, that's probably sufficient. Will double-check this next week.

martinjaeger, 2022-08-27:
New circuit introduced in new design. Will close the issue after testing.

martinjaeger, 2023-04-15:
Fixed in current board design.

Closed 2023-04-15.

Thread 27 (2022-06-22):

Thermal performance of N-MOS switches

EarthLord, 2022-06-22:
Hello, just curious to see if any thermal performance numbers have come up from any initial tests.

EarthLord, 2022-07-06:
https://lcsc.com/product-detail/MOSFETs_HUAYI-HYG022N10NS1TA_C2925050.html might be an alternative that can be used in the interim.

martinjaeger, 2022-08-02:
Those HUAYI MOSFETs are indeed quite interesting. There is even one with almost the same specs as the originally planned IPT015N10N5: https://lcsc.com/product-detail/MOSFETs_HUAYI-HYG015N10NS1TA_C2979263.html

I did some research about the quality of that manufacturer and found that they actually produce for Infineon, so those MOSFET may be of good quality, but lower price: https://www.mouser.com/PCN/Infineon_20176A.pdf

@EarthLord do you have any experience with them?

EarthLord, 2022-08-04:
No, don't have experience with this manufacturer yet. I found them while looking for TOLL8 package mosfets during this shortage season. Maybe good to try them out based on your finding that they manufacture for Infineon.

martinjaeger, 2023-04-15:
Final test report including thermal performance tests was added to the repo:
https://github.com/LibreSolar/bms-c1/blob/main/testing/v0.3/README.md

Closed 2023-04-15.

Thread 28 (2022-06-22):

Current shunt footprint recommendation

EarthLord, 2022-06-22:
https://www.analog.com/media/en/analog-dialogue/volume-46/number-2/articles/optimize-high-current-sensing-accuracy.pdf This article of ADI provides some recommendation for a 4 point footprint for shunt. Would something like this be done in the next version?

Also based on thermal performance, a 5931 package SMD shunt might be better than a 3920 one?

martinjaeger, 2022-07-05:
Yes, taking the larger footprint makes a lot of sense and will be implemented in the next revision. The cost increase is quite low.

I will also update the sense traces, but probably not exactly like in the paper you linked, which is designed for much lower current. I don't want to waste any trace width in the high current path with the via outside the shunt, so I would place the traces towards the center of the shunt.

martinjaeger, 2022-08-27:
Implemented in newest revision:

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

Closed 2022-08-27.

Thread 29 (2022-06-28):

Charge pump capacitor value estimation

B-hafedh, 2022-06-28:
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

How do you estimate the charge pump capacitor value ?
 4*16nF*10=680nF

B-hafedh, 2022-06-28:
>
Thank you,
but there is no information about it in bq76952 datasheet, can you provide me the document please.
and i have another question: what is the role of the schottky diode & zener diode connected to VC0, i thought they are used for reverse polarity protection, but you already used a schottky diode connected to VC16.

martinjaeger, 2022-07-01:
It was not necessarily the datasheet. There are lots of documents for this chip provided by TI, I don't remember which one it was.

In any case you can also estimate the value yourself. It is a trade-off between startup-time (faster if capacitance is lower) and voltage drop during switch-on event (lower if capacitance is higher).

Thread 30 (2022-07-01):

ESP32 CAN bus

B-hafedh, 2022-07-01:
The ESP32 offers a CAN 2.0B interface(up to 1Mbit/s), and you use the STM32G0B1 CAN(FD) interface (up to 15Mbit/s).
So, my question is: can i use the ESP32 CAN to command an E-scooter Motor Control Board for example, or a 1Mbit/s speed is not enough ?

martinjaeger, 2022-07-01:
It depends on the E-scooter motor controller. Most probably classical CAN with around 500 kbit/s will be fine.

Closed 2023-11-02.

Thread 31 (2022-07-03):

BAT+, CHG+ and PACK+ voltage measurment

EarthLord, 2022-07-03:
I just realized that there's no provision for BAT+, CHG+ and PACK+ voltage measurement or did I miss it in some corner of the schematic? Or can BAT+ be measured independently by the BQ chipset?

martinjaeger, 2022-07-05:
Yes, you're right, it was missing. I've already included a PACK+ measurement in the next revision of the board (to be finished and published in a few weeks).

For bus pre-charge I think PACK+ is sufficient. What do you think CHG+ voltage measurement would be useful for?

EarthLord, 2022-07-05:
CHG+ is useful for triggering some alarm by detecting if there is an MOSFET issue of short circuit by measuring CHR+ when MOSFET.

martinjaeger, 2022-07-05:
Not sure if I understand what you mean. Could you elaborate a bit more?

I'd like to avoid a resistor divider at the CHG+ because it would continue draining the battery through the CHG MOSFET body diode even if the battery is in deep sleep.

EarthLord, 2022-07-06:
Sorry for the bad explanation. MOSFETs when stressed with over current go bad by short circuiting without gate control - but in our case the short circuit will have higher resistance than when turned on when operational. My intention was to be able to detect this situation. I forgot when I posted this that the MOSFET configuration is with the drains tied together. With source tied together its easier by checking the common source voltage when both MOSFETs are turned off.

With drain tied together it might be possible by accounting for the diode forward drop. Which ADC do you want to use for BAT+ and PACK+ measurement?

martinjaeger, 2022-08-27:
The bq does actually have its internal BAT+ and PACK+ measurements, so I decided to not use the MCUs ADC for this sort of measurement, as the voltage divider would also result in an additional continuous (very small) current flow. In addition to that, the ADC of Espressif chips is usually not very good...

Closed 2022-08-27.

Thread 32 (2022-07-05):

Cell Balancing

B-hafedh, 2022-07-05:
Do you think that internal cell balancing with I_Balance ~= 65 mA is sufficient for most applications, and why ??
what about power dissipation and the resulting heat ?

martinjaeger, 2022-07-05:
The resulting heat is not really an issue, but 65 mA may not be enough for applications with very large cells or cells with very inhomogeneous capacity or self discharge rate.

As always, it's a tradeoff between amount of functions/applications and cost. Active balancing costs **much** more than this rather simple passive balancing. That's why it was discarded for this BMS development targeting very cost-sensitive energy access applications.

Closed 2022-08-27.

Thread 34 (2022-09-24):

GPIO9 (BOOT) pin not broken out

martinjaeger, 2022-09-24:
Stupid mistake: I forgot to break out the above pin to enter the serial bootloader.

It's not an issue for normal flashing via the USB port with built-in Serial/JTAG interface, but having it available is very helpful if something goes wrong and the bootloader has to be triggered manually.

Closed 2022-09-30.

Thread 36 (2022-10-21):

Q12 has wrong pinout

martinjaeger, 2022-10-21:
This MOSFET should use the Q_PMOS_GDS symbol instead of Q_PMOS_GSD to fix the pinout.

Closed 2022-11-07.

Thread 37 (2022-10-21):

Hardware v0.3 Testing - Tracking Issue

martinjaeger, 2022-10-21:
This issue serves as a tracking issue for ongoing testing of the v0.3 hardware.

- [x] USB serial communication
- [x] UART serial communication
- [x] I2C communication (see https://github.com/LibreSolar/bms-firmware/issues/25)
- [x] CAN communication (see also https://github.com/zephyrproject-rtos/zephyr/pull/51100)
- [x] Pre-discharge circuit (see also https://github.com/LibreSolar/bms-c1/issues/36)
- [x] Turn on/off MOSFETs
- [ ] Balancing
- [x] BMS on/off button / connector
- [x] Voltage measurement
- [x] Current measurement
- [x] Temperature measurement
- [ ] Thermal performance
- [ ] Fuse circuit

martinjaeger, 2022-10-24:
Pre-discharge circuit is working with latest firmware (https://github.com/LibreSolar/bms-firmware/commit/45df96b652b82a5a4ae333608ed071bd70f83ed5). Below tests were performed with a 24V LFP-Battery.

Yellow (CH1): PDSG (TP7), Blue (CH2): DSG (TP6)

1. BAT+ and BAT- terminals open.

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

2. BAT+ and BAT- terminals connected to 1200 uF electrolytic capacitor.

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

The PDSG MOSFET is enabled first (P-channel MOSFET, i.e. gate pulled low) and pulls up the bus voltage through the resistor. The DSG follows the bus voltage. 250 ms after the bus voltage reached the battery voltage, the DSG FETs are enabled (gates 12V above battery voltage)

martinjaeger, 2022-11-01:
The current and voltage measurement results from the bq76952 are less accurate than expected.

An example from testing:

- Pack current
  - BMS 3.76 A
  - Fluke multimeter: 3.95 A
- Pack voltage
  - BMS 26.98 V
  - Fluke multimeter: 27.20 V

The root cause has yet to be investigated. The bq76952 features different calibration features which can be leveraged to improve the accuracy.

martinjaeger, 2022-11-14:
Which circuit problem do you have?

The LDO cannot handle the current required for the ESP32-C3.

martinjaeger, 2022-11-15:
It really depends. Also a CAN transceiver can draw considerable amount of current. I didn't do the math, but dropping voltage from 60V to 3.3V will dissipate a lot of heat even for very small currents. For ESP32-C3 with WiFi it's not feasible for sure.

Let me know if you did some calculations and you think it may be doable with LDO only.

martinjaeger, 2023-04-15:
Final test report was added to the repo, closing this issue.

https://github.com/LibreSolar/bms-c1/blob/main/testing/v0.3/README.md

Closed 2023-04-15.

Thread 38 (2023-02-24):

BMS-C1: Kicad Library

joshuasiumao, 2023-02-24:
Where can I find Kicad's library for those symbols, footprints,  and 3D files?

martinjaeger, 2023-02-24:
The symbol library is here: https://github.com/LibreSolar/kicad-symbols

Normally it should also work without the correct library path, as KiCad stores the symbol inside the schematic since v6.0.

Unfortunately I cannot publish the 3D files as they were partly downloaded from companies like Würth and they don't have an open license.

Closed 2023-02-24.

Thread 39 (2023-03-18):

Intention of CHG+ pad

nik21-nik, 2023-03-18:
Hi,

I have already checked the manual (I hope I have not overlooked anything, then sorry for that). I am not sure what the intention of the CHG+ pad in the PCB layout is. Obviously the port powers the I would call it "Predischarge circuit".
Is the exposed for the charger connection? Then why would I solder a cable onto a pad instead of using the power port connector like you did with BAT+, BAT-, PACK+ and PACK-.

Thank you!

martinjaeger, 2023-03-18:
The CHG+ pad is for experimenting. That's why it only got a zero-cost pad instead of a proper terminal.

Some users were suggesting to have separate charge and discharge paths as seen in many e-bike BMSs. However, in e-bikes these paths are in parallel, such that accidental overcharging through the discharge path cannot be interrupted. This was not an option for our BMS for safety reasons.

Using the CHG+ pad for chargers slightly increases the efficiency, as the heat dissipation in the DIS MOSFET can be avoided. In addition to that, a charger may be able to detect the battery even if it is in deep sleep mode.

nik21-nik, 2023-03-20:
Thank you very much for the explanation.

Closed 2023-03-20.

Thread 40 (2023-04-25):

D16 Schottky diode inverted?

LorenzoGuerro, 2023-04-25:
Hello,

I simulated the reverse polarity protection circuit and it somehow doesn't work. There is a whole amount of current flowing over the DSG pin through the Schottky diode D16 with a reversed charger. A Texas Instrument application document shows this diode inverted. Is not the R51 68k resistor meant to drive the gates and the (then inverted) diode to turn off the discharge MOSFETs faster?

Then, if there is a reversed charger connected, voltage drops over the R51 68k resistor.

martinjaeger, 2023-04-28:
Hi Lorenzo.

Thanks for reporting your findings.

As far as I can see, the [TI reference design](https://www.ti.com/tool/TIDA-010208) has the diode D37 in the same direction.

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

That being said, I haven't tested the reverse polarity circuit in real life yet, as I didn't have too many boards yet to potentially destroy them. I'll try to test it with one of the early prototypes by slowly increasing the reversed voltage with a current-limited power supply to see what happens.

Which software did you use for simulation of the circuit. Would you mind sharing the file if it's a freely available software like LTSpice?

LorenzoGuerro, 2023-05-02:
Please find here the simulation I made in Falstad Circuit Simulator: [simulation.zip](https://github.com/LibreSolar/bms-c1/files/11370771/simulation.zip)

Things I am unsure about:
The DSG pin outputs about 40V to drive the MOSFETs. Let's say we connect an inverted charger. Will the DSG pin still be on 40V or will it go to 0V?

Either way, if the DSG pin stays on 40V it will draw about 59mA with an inverted charger, which seems a lot. With DSG pin at 0V it will still draw around 6mA. Trying to invert the diode D16, almost no current will be drawn from the DSG pin, since voltage now drops over the 68kOhm resistor. (And of course turn off/on times of the MOSFETs change: What do we want? Fast turn off and slow turn on? Seems like we can't have both here.)

Please check the attached image of another TI design reference: [https://www.ti.com/lit/an/sluaa09a/sluaa09a.pdf](url)
The marked diode is inverted there.

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

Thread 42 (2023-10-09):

Thermal Performance Tests

pasrom, 2023-10-09:
### Introduction:
Our aim was to conduct a thermal investigation of the BMS to determine how hot it gets at a current of 100 A or more.

### Test Setup:
The picture below illustrates the BMS setup during the testing phase (with heatsink). The tests were performed without actual battery, as described [here](https://github.com/LibreSolar/bms-c1/blob/main/testing/v0.3/README.md#11-test-setup).
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

### Used Devices:
- Power source: E/A Power Supply PSB 10750-120
- Sink: Deutronic xxx
- Temperature measurements: "TIM QVGA/HD" thermal imaging camera
- Linux & Windows Computer

### Boundary Conditions:
- Ambient Temperature: ~24°C

### Test Scenarios:
Three different scenarios were tested:
1. **Without Heatsink**:
   - Current: 100 A
   - Measured Temperature: ~91°C after 35 minutes
   - BMS Position: horizontally on the table
   - The thermal camera image below displays the temperature distribution upon concluding the test, highlighting the MOSFETs as the area of highest temperature.
   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

2. **With Heatsink (1)**:
   - Current: 100 A
   - Measured Temperature: ~49°C after 25 minutes
   - BMS Position: 5 cm above the table (floating, cooling fins facing down to the table)
   -  The thermal camera image below displays the temperature distribution upon concluding the test, with the PCB layer of the shunt being the hottest area.
   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

3. **With Heatsink (2)**:
   - Current: 122 A
   - Measured Temperature: ~66°C after 4 hours
   - BMS Position: identical to Measurement 2
   - The thermal camera image below displays the temperature distribution upon concluding the test, with the PCB layer of the shunt being the hottest area.
   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

   - Below graph shows the current profile, temperature rise of the internal sensors and thermal camera temperature areas over time.
   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
### Conclusion
The BMS can comfortably manage over 100 A while maintaining a temperature within an acceptable range.
If feasible, the PCB layer should have a thickness greater than 70 µm to minimize the heating around the shunt.
Further work could involve identifying the maximum current that results in a temperature of around 80°C.

pasrom, 2024-10-22:
@martinjaeger I performed an 80 A test without the heatsink using the latest hardware.

## Test Setup:
Libre Solar BMS C1 v0.4.1 (03/2024)

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
<div style="display: flex; justify-content: space-between;">
  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
</div>
Left: 80 A power source. Right: 80 A sink.

## Boundary Conditions:

Ambient Temperature: ~21°C

## Test Scenario 80 A without heatsink

- Current: 80 A
- Measured Temperature: ~58°C after 60 minutes
- BMS Position: horizontally on the table
- The thermal camera image below displays the temperature distribution upon concluding the test, highlighting the MOSFETs as the area of highest temperature.

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

Below graph shows the current profile, temperature rise of the internal sensors and thermal camera temperature areas over time.
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

martinjaeger, 2024-10-24:
Nice, thanks for posting the test results!

pasrom, 2024-10-24:
I added the 100 A test without a heatsink to the post. I believe 80 A without a heatsink is acceptable at temperatures below 60 °C, but 100 A without one is not recommended because it reaches nearly 90 °C.

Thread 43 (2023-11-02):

Overvoltage and Undervoltage Testing Issue with BMS_C1 Board

Ananyaaynana, 2023-11-02:
Issue Description:

We are currently in the process of testing the BMS C1 board, specifically by subjecting it to overvoltage and undervoltage tests. The expected behavior during an overvoltage or undervoltage condition is that the voltage across the PACK+ and PACK- terminals should be 0V. To monitor this, we have employed an oscilloscope to probe TP4 (charge pin of BQ76952) and TP6 (discharge pin of BQ76952) on the board.

However, we have encountered an issue with the behavior of TP6 during undervoltage conditions. According to our expectations, TP6 should remain at 0V during an undervoltage condition, but we have observed that the voltage at TP6 is fluctuating instead of staying at a stable 0V. Simultaneously, TP4 exhibits the anticipated high voltage.

Steps to Reproduce:

    1) Set up the BMS C1 board for undervoltage testing.
    2) Monitor the voltage at TP6 using an oscilloscope.
    3) Observe the fluctuating voltage at TP6 during the undervoltage condition.

Expected Behavior:

During an undervoltage condition, the voltage at TP6 should remain stable at 0V.

Actual Behavior:

The voltage at TP6 fluctuates instead of staying at a stable 0V.

Additional Information:

We have attached a snippet of the oscilloscope output when the probe is positioned at TP6 to provide a visual representation of the issue.

Attachment:

https://github.com/LibreSolar/bms-c1/assets/131510581/0ddd5d20-eb06-470d-b959-e04d02ece42b

Environment:

    Board: BMC C1.
    Oscilloscope model: KEYSIGHT EDUX1052A.
    Testing conditions: Positive terminal of oscilloscope placed at TP6 and negative terminal connected to BAT-.

Impact:

This issue may affect the accuracy and reliability of the BMS C1 board's undervoltage protection, potentially leading to unintended consequences in real-world applications.

We kindly request assistance in investigating and resolving this issue to ensure the board's proper functionality under undervoltage conditions.

Labels: #testing #undervoltage

martinjaeger, 2023-11-02:
Thanks for posting this issue.

I could not reproduce the behavior with [latest main](https://github.com/LibreSolar/bms-firmware/tree/55c2ea2cf5a2658ad180f9c9eff17e8308848b03) firmware on a BMS C1 v0.3.3 board with 4s cells. Once the BMS goes into undervoltage state the TP6 stays at around 0V all the time and only goes up again after the battery voltage rises above the reconnect threshold.

Which firmware version did you use?

martinjaeger, 2023-11-07:
Did you also try with the most recent firmware?

Also: If it appears only on one board, it may actually be a hardware issue.

Ananyaaynana, 2023-11-10:
Follow-up: Live Data Not Publishing, and Board Shutdown Issue with Latest Firmware

Issue:
I tried updating to the latest firmware version "v23.1-1-g55c2ea2-dirty," but encountered two issues:

    Live data is not being published on Cutecom.
    The board shuts down when attempting to flash the code and can only be turned on using the S2 button.

Steps Taken:

To address the live data issue, I created an overlay file (as in https://libre.solar/bms-firmware/src/dev/customization.html) in the app folder with the following code:
{
    chosen {
        thingset,serial = &usb_serial;
    };
}

I then built and flashed the code using the "west flash" command. When attempting to monitor the board using the "west espressif monitor" command, I encountered the following output:
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

Additionally, when I tried to flash the code again, red and green leds turn off but there is voltage at the bat+, bat-, pack+ and pack-. When the leds are off the  "west espressif monitor"command  gives this:
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

On exiting the espressif monitor not able to flash code again. On holding down the S2 button the leds turn back on after blinking for a few seconds:
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

I would appreciate any guidance on resolving these issues. Specifically, I need help with:

    1) Diagnosing and resolving the issue with live data not being published on Cutecom.
    2) Understanding why the board is shutting down during code flashing and how to prevent this from happening.

Additional Information:

    Board Model:  Libre Solar BMS C1 (v0.3)
    Firmware Version: v23.1-1-g55c2ea2-dirty.

Ananyaaynana, 2023-11-11:
Follow-up: Live Data Not Publishing, and Board Shutdown Issue with Latest Firmware

Issue:
I tried updating to the latest firmware version "v23.1-1-g55c2ea2-dirty," but encountered two issues:

    Live data is not being published on Cutecom.
    The board shuts down when attempting to flash the code and can only be turned on using the S2 button.

Steps Taken:

To address the live data issue, I created an overlay file (as in https://libre.solar/bms-firmware/src/dev/customization.html) in the app folder with the following code:
{
    chosen {
        thingset,serial = &usb_serial;
    };
}

I then built and flashed the code using the "west flash" command. When attempting to monitor the board using the "west espressif monitor" command, I encountered the following output:
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

Additionally, when I tried to flash the code again, red and green leds turn off but there is voltage at the bat+, bat-, pack+ and pack-. When the leds are off the  "west espressif monitor"command  gives this:
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

On exiting the espressif monitor not able to flash code again. On holding down the S2 button the leds turn back on after blinking for a few seconds:
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

I would appreciate any guidance on resolving these issues. Specifically, I need help with:

    1) Diagnosing and resolving the issue with live data not being published on Cutecom.
    2) Understanding why the board is shutting down during code flashing and how to prevent this from happening.

Additional Information:

    Board Model:  Libre Solar BMS C1 (v0.3)
    Firmware Version: v23.1-1-g55c2ea2-dirty.

martinjaeger, 2023-11-11:
If an issue is unrelated to the topic of this issue, please open a new one.

Live data publication on the USB serial is now disabled by default. As mentioned in the [release notes](https://github.com/LibreSolar/bms-firmware/releases/tag/v23.1), the Zephyr shell is now exposed to the USB serial. In order to enable publication messages on the shell, enable it [here](https://github.com/LibreSolar/bms-firmware/blob/cb89c75b74e85a036b7c6243424e31c68b3b3018/app/boards/bms_c1.conf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).

Regarding your problem with flashing: Did you keep the serial monitoring on while you tried to flash (espressif monitor or CuteCom)? That's not possible, as flashing uses the same serial interface.

Ananyaaynana, 2023-11-11:
Okay I will raise a new issue.

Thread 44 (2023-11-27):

BMS non-responsive after working for a few minutes.

Morynmoh, 2023-11-27:
Test on BMS carried out with mild success.

BMS powered through cell connectors - 3 cells used. We were even able to connect to it via BLE using the Thingset App.

However, when we connected the BAT - and then BAT +, the unit became non-responsive. The status LED lights are all off and the unit cannot be found on BLE. Tried the reset S2 and on/off S1 buttons in vain.

martinjaeger, 2023-11-27:
Thanks for the report.

Did you also short the unused cell channels? Basically all cell connections from Cell3+ onwards?

Also can you see if there is something printed on the virtual COM port if you connect to the USB?

Does it restart if you disconnect BAT+ and BAT- again?

Morynmoh, 2023-11-27:
Thanks for the quick response.

We initially connected 3 cells without shorting the unused cell channels (which worked shortly). Later after the BMS went unresponsive, we connected all 16 cells (it didn't work).

It doesn't work when we disconnect BAT + and BAT -.

I will explore the virtual COM port option.

Morynmoh, 2023-11-27:
We have 16 cells but we trialed with 3cells to test the BMS. We only added upto 16 to see if that will turn on the BMS.

The battery voltage was 9.6V for the 3 cell.  ![Uploading 20231124_104350.jpg …]()

Morynmoh, 2023-11-29:
Hi @martinjaeger - The USB virtual is nonresponsive . The Serial com port issue.
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

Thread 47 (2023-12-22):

Clarification needed on copper thickness of inner PCB layers

Selvakumar58, 2023-12-22:
In the PCB notes, we see the following text:

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

However, in the Board setup, the details are as follows:

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

Here the units are in mils, but when converted to um, we get:

105 um outer layers
35 um inner layers

Which is the right one?

Regards,
Selva.

pasrom, 2023-12-22:
Hello @Selvakumar58,

Could you confirm if you are using the latest commit? I noticed that in [PR #46 of the LibreSolar/bms-c1 repository](https://github.com/LibreSolar/bms-c1/pull/46), there doesn’t seem to be any difference. If you are not on the latest commit, it might be worth updating to see if that addresses your issue.

Selvakumar58, 2023-12-26:
Hello @pasrom ,

We are using V0.3.3 (Commit no: b7895e0fe39fa203ef21a05e899bce7c4bfe8ab3) to build a few prototypes before transitioning to the latest commit.

Any thoughts on the copper thicknesses for this commit?

Regards,
Selvakumar.

pasrom, 2023-12-26:
From what I understand, @martinjaeger manufactures his boards with a 70 μm thickness for all four layers. It would be great if @martinjaeger could confirm this.

martinjaeger, 2023-12-27:
Correct. We manufactured the first batch with 70u for inner and outer layer because the originally intended 105u were not suitble for the small pin pitch of the bq76952.

Both myself an @pasrom have tested the boards and 70u turns out to be sufficient for 100A with a heat sink.

Selvakumar58, 2024-01-09:
Thank you

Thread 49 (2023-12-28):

Minor - correction on schematics

robm0162, 2023-12-28:
Just a couple of minor observations in file bms-c1.pdf - schematic for FET section.  Page is numbered 7/5 as is the next page - page numbering needs reset.

More importantly, on page 7/5 - the section showing the FETs for reverse polarity and CHG signals, the note in the bottom left corner says the gate resistors is 470ohm and bases a calculation on this, while the schematic shows these are 47ohm, not 470ohm.

martinjaeger, 2024-01-17:
Thanks @robm0162 for the report. I didn't even know that the schematic numbers can be assigned (or have to be assigned) manually.

Also the calculation is now fixed. The time constant was reduced to allow for shorter switch-off during short circuit conditions, so 47 Ohm is correct.

Closed 2024-01-17.

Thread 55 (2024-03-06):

Fix NPTH clearance in v0.4

devbotas, 2024-03-06:
aisler.net complains about this:
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

And indeed, one of those USB connector holes got electroplated, shorting 3V3 to GND.

I (hopefully) fixed my PCBs by drilling a slightly larger hole.

martinjaeger, 2024-03-06:
Thanks a lot for reporting this issue.

I had ordered one PCB for validating the design, which worked fine. However, the NPTH of the USB connector looks indeed wrong. Also the KiCAD DRC didn't complain about this. That's very annoying, as I have already ordered a batch of assembled boards.

Will fix the issue and keep you updated.

martinjaeger, 2024-03-07:
The good news is: I could stop the assembly just before placement of the parts. I will get the PCBs for double-checking. Most probably we will have to re-order them.

@devbotas Your bug report came just in time. Thanks again! If you like, I can send you a fully assembled v0.3.3 board for free, so that you can immediately start working with the BMS. Please send me an email (martin at libre solar) with contact details.

devbotas, 2024-03-07:
Great to hear! Although your PCBs may still be OK.  The electrical test of my first batch was fine (or maybe they didn't do it, I don't know), but it was lost in shipping. It is the second batch that resulted in faulty tests.

martinjaeger, 2024-03-17:
@devbotas FYI: I tested the insulation resistance of approx. 20 of the v0.4.0 boards with a Fluke 1507 and got >11 GOhm (max. of measurement range) for all of them for a test voltage of 1000 V. Looks like these PCBs were fine. However, the clearance should still be fixed, of course.

Please see the PR linked above for the fix.

devbotas, 2024-03-17:
So you've got lucky, nice 👍

Closed 2024-04-06.

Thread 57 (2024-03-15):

CAN bus testing

Ananyaaynana, 2024-03-15:
We want to perform CAN bus testing with firmware at commit: 50b5bc5bdae9ee7609a8f9edb43ee9fb062481d9 for a custom board similar to 0.4v bms_c1.

The test document gives a brief description of the CAN bus testing. What are the steps to be followed for testing the CAN bus?

martinjaeger, 2024-03-15:
The device should automatically start sending reports once connected to a bus.

The protocol is described [here](https://thingset.io/spec/v0.6/transports/can.html). Also see [here](https://thingset.io/spec/v0.6/annex/b_tools.html#can-under-linux) for some recommended tools to use under Linux.

Ananyaaynana, 2024-03-16:
Thank you for the reply.

Closed 2024-03-16.

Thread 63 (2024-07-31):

Support for daisy chaining (or otherwise connecting) multiple LibreSolar BMS for stackable energy storage packs

rexlee2, 2024-07-31:
To connect multiple BMS in daisy chain manner (e.g. to implement stackable energy storage module) it seems that using CAN 2.0 bus would be most appropriate.

Can 11 bit DIP switches be added to assign 11-bit CAN ID supported by CAN 2.0A standard? Given the price of batteries, I believe LibraSolar should assume that most residential and commercial applications will require an easy method of scaling LibreSolar BMS without having to load unique BMS software to every single BMS unit within energy storage pack.

Appreciate your feedback and consideration!

martinjaeger, 2024-07-31:
The ThingSet protocol (used by default by the Libre Solar BMS) does already support automatic node address assignment, see [here](https://thingset.io/spec/v0.6/transports/can.html#network-management) for the details.

Daisy-chaining is more an electrical question. You need to make sure that you only connect two BMSs in parallel which have the same SOC and capacity. So you'd need to start communication before you switch on the MOSFETs. This is currently not implemented, but could be done on top of ThingSet.

Connecting multiple batteries in series is currently not supported, as it would require MOSFETs rated with the resulting overall pack voltage, which is not the case.

rexlee2, 2024-08-01:
Thanks for the detailed explanation Martin! This helps a lot.
I understand that the BMS units need to communicate and ensure that the SOCs and other parameters are aligned. Any thought or comment on how similar SOC or voltage levels need to be before turning on the MOSFETs? I wonder if there is a SOC mismatch that would be considered unsafe for parallel connection.

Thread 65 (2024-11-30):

Power Terminal blocks

fl4p, 2024-11-30:
Hi,

I am curious, why do you use SMD power terminals for the battery connection?
These appear to have low availability and a bit pricy.
I think THT has better mechanical stability and can directly connect to all copper layers.

This would be a cheap alternatives:
[M6 Nut ](https://www.digikey.com/en/products/detail/w%C3%BCrth-elektronik/S93515/10123864)
[M5 Screw](https://www.digikey.com/en/products/detail/w%C3%BCrth-elektronik/S93514/10123859)

fotherja, 2024-12-05:
Yes, I agree. I feel THT terminal blocks would carry the currents to all 4 copper layers better and be more robust overall. This is a nice part: [16 pin M5 180A rated](https://www.mouser.co.uk/ProductDetail/Wurth-Elektronik/7461383?qs=lykWx4dhCCFZ0JBsRfYENw%3D%3D)

fotherja, 2024-12-05:
Yes, I agree. I feel a THT terminal block would better carry the current to all 4 copper layers and be more robust. Here a nice [M5 Nut 180 A solution](https://www.mouser.co.uk/ProductDetail/Wurth-Elektronik/7461383?qs=lykWx4dhCCFZ0JBsRfYENw%3D%3D)

martinjaeger, 2024-12-11:
Thanks for the suggestions, @fl4p and @fotherja.

We considered THT parts, but could not find any suitable parts for the required amount of current which are available at the usual distributors.

As far as I know, the parts you linked are not "normal" THT parts, but press-fit parts. We actually used press-fit parts in previous versions of this BMS, but finally decided against them because they require special PCB treatment which is more expensive and not available at all PCB manufacturers.

One more advantage of the SMD terminals is that the bottom of the PCB remains completely flat, so that it can be easily mounted to a heat sink. As soon as you have press-fit terminals or THT terminals you will need milling / cutouts in the heat sink.

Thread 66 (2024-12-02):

Use unused GPIOs when RS485 is deactivated

pasrom, 2024-12-02:
I propose utilizing the currently unused RS485_RE and RS485_R̅E̅ pins when RS485 communication is disabled. These GPIOs could be repurposed to control an external actuator or serve other similar tasks.

Before proceeding, it would be necessary to evaluate whether there is sufficient space on the PCB for this modification.

Looking forward to hearing your thoughts on this enhancement!

pasrom, 2024-12-05:
What do you think about expanding the existing UART-JST connector to add these two additional pins? It would actually make sense, as the UART can also be used as GPIO when not in use, providing a total of four GPIOs. This approach would minimize space requirements compared to adding a new connector. However, one drawback is that the existing cables would not be compatible, so new cables would be needed.

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

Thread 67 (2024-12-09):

Short-circuit protection behavior and results

pasrom, 2024-12-09:
### Description

The short-circuit test was performed to evaluate the behavior of the BMS under fault conditions and ensure proper protection mechanisms are in place. The test helps determine if the system correctly detects and reacts to a short-circuit event by shutting down the power section.

### Configuration and determination of actual short-circuit current

The short-circuit delay was set to 1, as outlined in [datasheet](https://www.ti.com/lit/ug/sluuby2b/sluuby2b.pdf) section 13.6.7.2 `Protections: SCD: Delay`, which should trigger an immediate shutdown of the power section. The configuration for the short-circuit delay is:

`thingset =Conf {"sShortCircuitDelay_us":1}`

The short-circuit current limit was configured to 0, theoretically resulting in a 33.3 A limit. However, the measured short-circuit current was 38.5 A, determined by gradually increasing the current until the BMS initiated a power shutdown. The configuration for the short-circuit current limit is:

`thingset =Conf {"sShortCircuitLimit_A":0}`

Figure 1 shows the current (yellow) and pack voltage (red) traces during the short-circuit event. The orange point marks the moment when the current reaches the shutdown point of the BMS, determined by gradually increasing the current.

<figure>
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
<figcaption>Figure 1: Measurement of the actual short-circuit current</figcaption>
</figure>

### Short circuit test

The short-circuit test was performed with a continuous current of 35 A, using a Deutronic electronic load to apply the short circuit. Figure 2 illustrates the test results, with the blue line representing the gate voltage, the yellow line showing the current, and the red line indicating the pack voltage. When the current exceeds 38.5 A, it takes ~40 µs to initiate the gate shutdown of the MOSFETs. In total, ~80 µs is required from detection to safely power down the output.

<figure>
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
<figcaption>Figure 2: Short-circuit test results</figcaption>
</figure>

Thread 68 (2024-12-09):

Voltage spike damaging LMR during power-on with power supply and electronic load

pasrom, 2024-12-09:
During recent testing #67 of the short-circuit shutdown via MOSFETs on the BMS C1, I noticed an issue where turning on the lab power supply with an attached electronic load occasionally causes a voltage spike that damages the LMR38010. After replacing it, the BMS C1 functions normally again. The following figure shows a successful shutdown where the power supply reached the configured voltage limit and turns off. Unfortunately, I couldn’t capture a failure case.

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

We suspect this issue might be caused by the interaction between the electronic load and the power supply.
Has anyone else experienced something similar?

martinjaeger, 2025-01-28:
Thanks @pasrom for reporting the issue. Only found time today to try to reproduce it.

I used a bi-directional power supply from EA for the BAT+/- side (set to 12V, +-10A) and a "normal" one connected to PACK+/- (set to 14.4V, 10A). I started with only 12V, as I had a resistor network ready for that voltage to simulate the single cell voltages.

I can see a voltage spike higher than the voltage provided by the power supply upon connection of the power supply to PACK+/-:

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

When switching the CHG MOSFET on/off via ThingSet `thingset =Input {\"wChgEnable\":true}`, the spike is much lower, most probably due to pre-charging.

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

I'm guessing that the voltage spike is coming from the inductivity of the wires. My wires were approx. 2m long (both on BAT and PACK side).

Normally, D12 (SMCJ70A) should cut off voltage spikes below the max. voltage of the LMR3810 (85V). So I'm not exactly sure why it got damaged.

Did you find out anything new in the meantime, @pasrom? And how did you measure the current in your experiment?

pasrom, 2025-01-29:
Thanks a lot for trying it out.

To measure the current, I used a Teledyne LeCroy CP150-6M.

Ah, that explains why I didn’t see the pre-charging, the MOSFETs are already opening automatically. I should test it as intended: starting the load only when the MOSFETs are disabled (thingset = Input {"wChgEnable": false}). Thanks for pointing me in this direction.

What do you think, could the maximum breakdown voltage (V<sub>BR</sub>) of 86 V interfere with the LMR38010, since it exceeds its absolute maximum rating of 85 V?
I could solder an SMCJ64A instead of the SMCJ70A and test it again. I already have a BMS where I desoldered the SMCJ70A after it was damaged by accidental overvoltage.

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

martinjaeger, 2025-02-03:
> I could solder an SMCJ64A instead of the SMCJ70A and test it again. I already have a BMS where I desoldered the SMCJ70A after it was damaged by accidental overvoltage.

I doubt it would make a huge difference. If we have peak currents after switching off far beyond 10A, the TVS diode won't be able to handle properly anyway. I'll try to come up with an LT spice simulation to how much energy the spikes would have for typical cable lengths and large currents.

Jan-vi, 2025-02-10:
Did you consider intrinsic inductors of power line and cells? Assume 1uH before Mosfet and 0,5uH behind Mosfet. To test Mosfet current breaking  capability, a maximum load inductor needs to be specified.  Big inductivity gives time to switch off early. On the other hand, current goes on when Mosfet switches off. For several microseconds, there is full current and battery voltage over drain/source. This requires to have a TVS for both drain and source of Mosfet with short GND connection. At switch-off moment, my battery voltage goes up to about 85 Volt.  For a few microseconds, the Mosfets SOA is challenged with several kilowatts to survive.

martinjaeger, 2025-04-30:
@pasrom Do you remember some more details of the setup where the overvoltage spike happened, which destroyed the LMR? We are building up a more detailed simulation model.

The following points would be interesting:
- Wire length and cross-section
- Cell capacity and internal resistance
- Pack voltage (or number of cells)

pasrom, 2025-05-09:
@martinjaeger thank you for doing a more detailed simulation model.
- **Wire length and cross‑section**
Wire length (one path): ~ 2 m
Cross‑section: 25 mm²
- **Cell capacity and internal resistance**
I used two bidirectional power supplies when this situation occurred:
  - Source: [PSB 1075-120](https://elektroautomatik.com/shop/de/produkte/programmierbare-dc-laborstromversorgungen/dc-bidirektionale-laborstromversorgungen/dc-bidirektionale-laborstromversorgu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)
  - Sink: [IT-M3900C](https://www.itechate.com/en/product/dc-power-supply/IT-M3900C.html)
- **Pack voltage**
Simulated pack voltage: 60 - 65 V

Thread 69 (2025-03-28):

Clarification on the necessity of Diode D9 in the circuit

vybhav-nag, 2025-03-28:
I was reviewing the BMS-C1 circuit diagram, and I noticed the presence of Diode D9. According to the IC datasheet, this component does not seem to be required. The datasheet specifies that the IC has built-in diode, making the external diode unnecessary in typical applications.

Could you please clarify the purpose of Diode D9 in this design? Is it necessary, and if so, what specific function does it serve in this context?

IC datasheet : https://www.ti.com/lit/ds/symlink/lmr38010.pdf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

Datasheet
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

BMS C1
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

martinjaeger, 2025-03-28:
Good spot. I'm not exactly sure anymore. We used to have a different (lower abs. max voltage) buck converter because the LMR38010 was not available at the time we made the design (chip crisis). Maybe I had some alternative part in mind when doing the most recent version of the schematic, which had the same pinout, but required a diode.

Looks like we could/should get rid of the diode.

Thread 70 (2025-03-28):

Clarification on C34, C48, C51, and C52 in the BMS-C1 Circuit

vybhav-nag, 2025-03-28:
I’ve noticed C34, C48, C51, and C52, each with a value of 100nF. It seems these capacitors could be intended for noise filtering or stability, but the exact purpose isn’t immediately clear from the circuit.

Can you confirm what these capacitors are primarily for? Are they critical for proper operation, or could the circuit function reliably without them.

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

martinjaeger, 2025-03-28:
Yes, exactly. The intention is for noise filtering. And we are using two in series for improved reliability. If one fails short, the other one still prevents a short between + and -.

The caps were taken from the TI reference designs. I haven't tried what happens if they are not present.

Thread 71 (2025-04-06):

does it support charging? or just monitoring?

jlmxyz, 2025-04-06:
Hi,
what is the functions of the BMS? so called "Battery Management Systems" are in fact "Battery Protections System" : over current/short circuit, reverse polarity, overcharge, undercharge, over temperature protections and some "monitoring" (how much go in and out, saving charge information) but for me they don't MANAGE the battery, eg they don't handle the charge which is the most important part....
best regards

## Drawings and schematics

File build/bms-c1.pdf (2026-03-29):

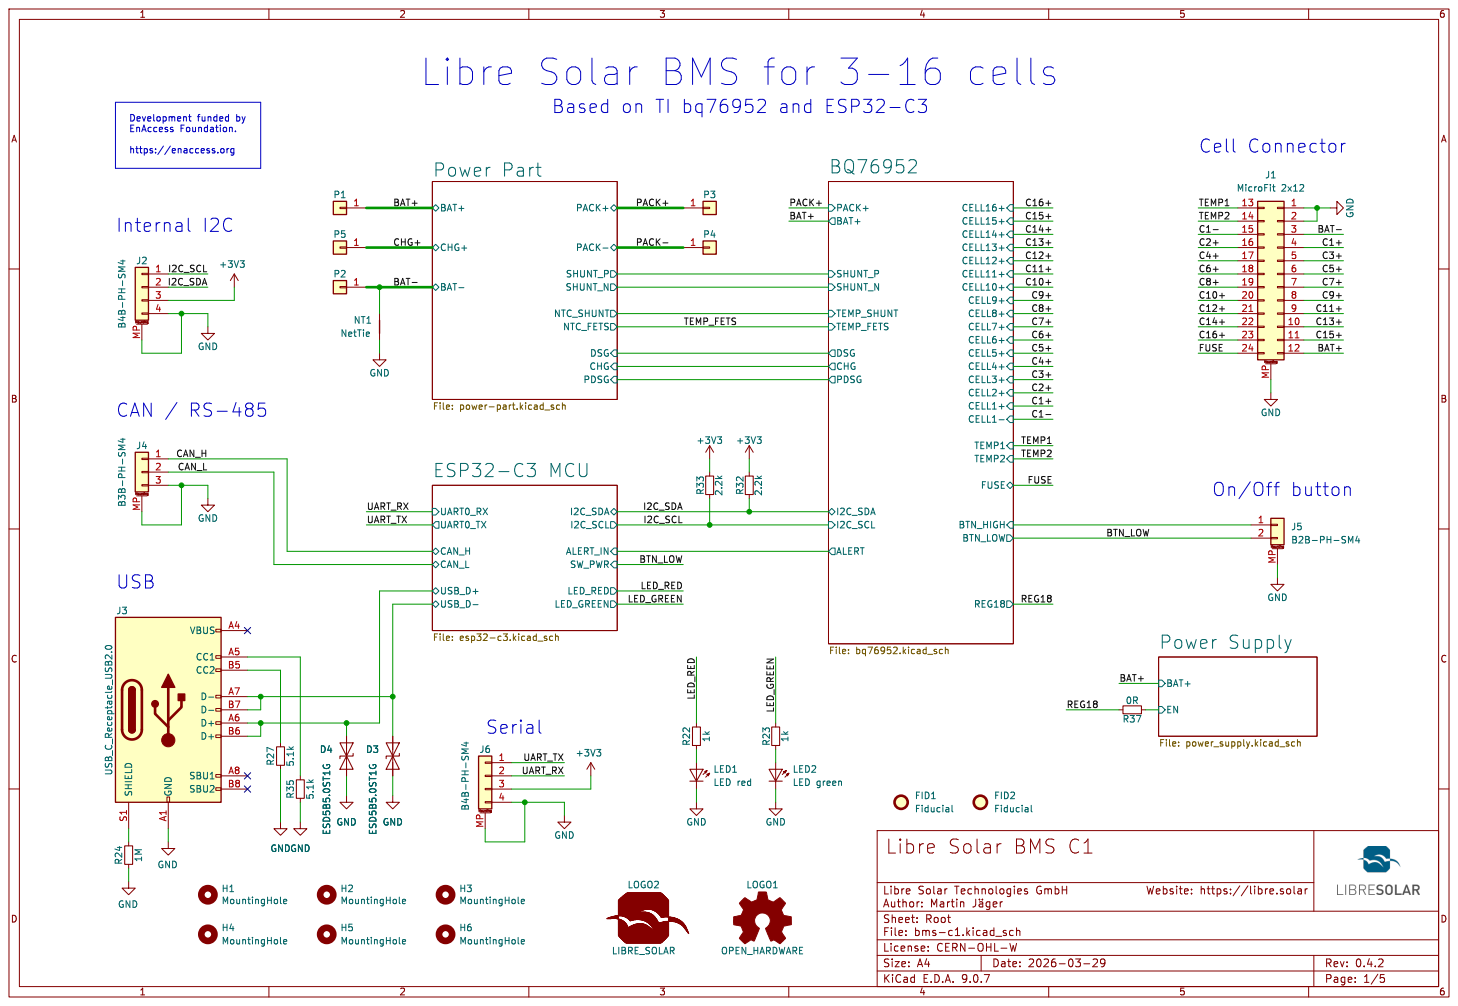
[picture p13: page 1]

Based on TI bq76952 and ESP32-C3

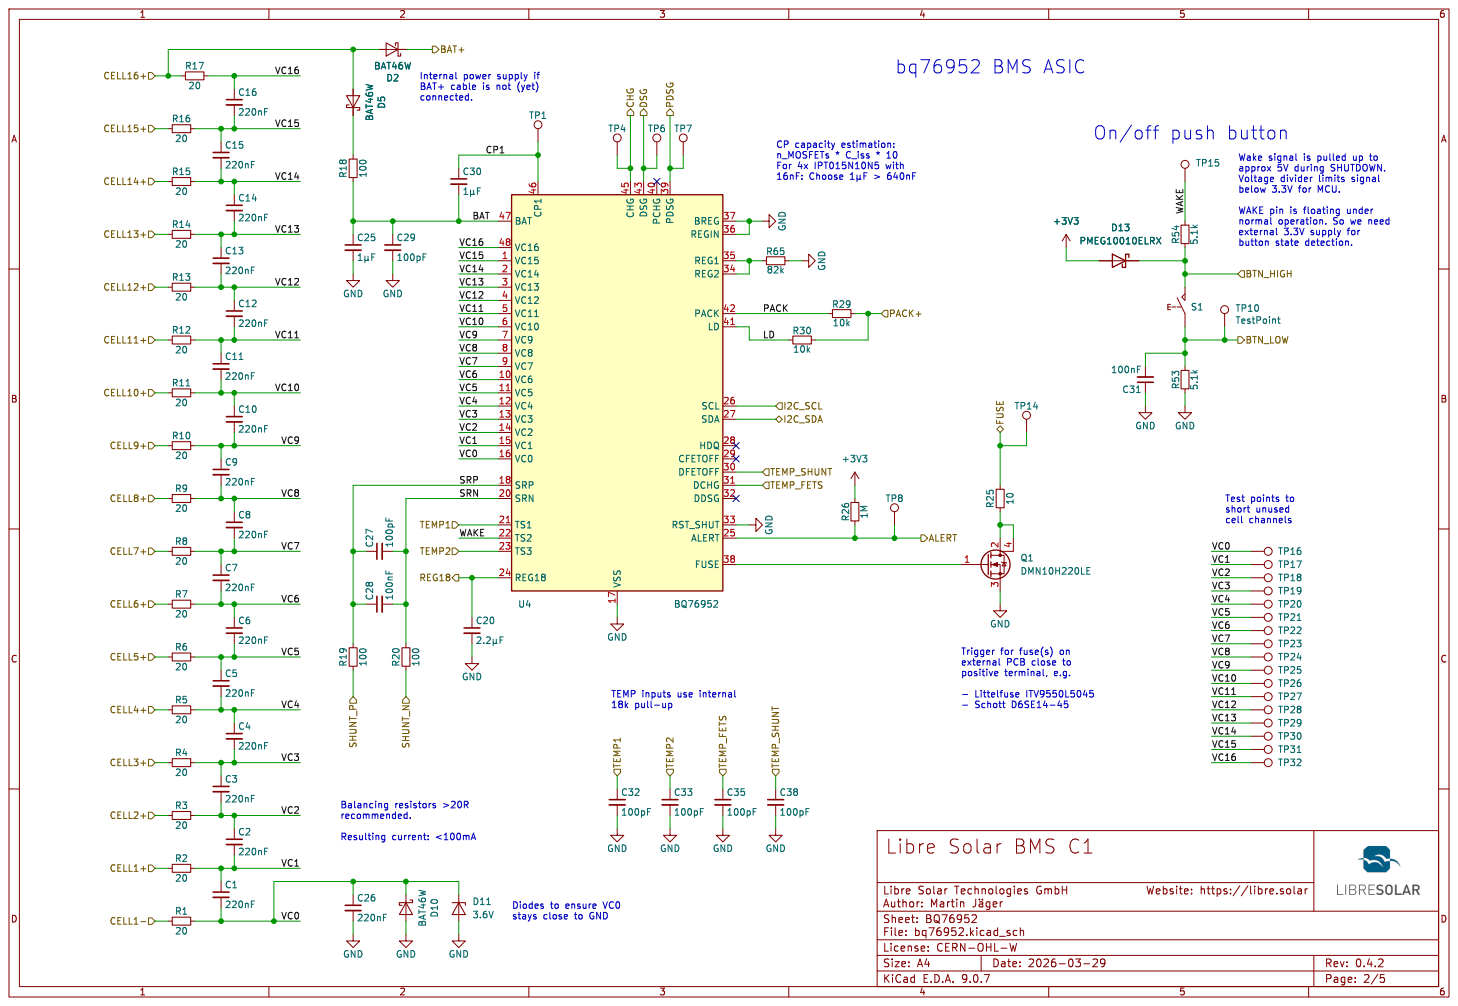
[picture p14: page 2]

Trigger for fuse(s) on

- Schott D6SE14-45 Diodes to ensure VC0

stays close to GND

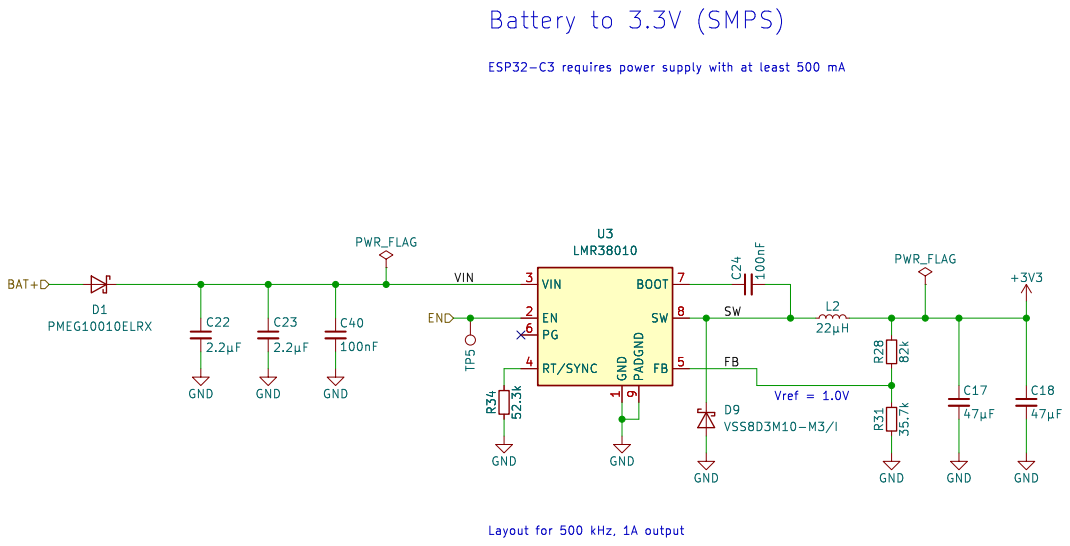
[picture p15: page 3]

FB Battery to 3.3V (SMPS)Vref = 1.0V

Layout for 500 kHz, 1A output U3
VIN

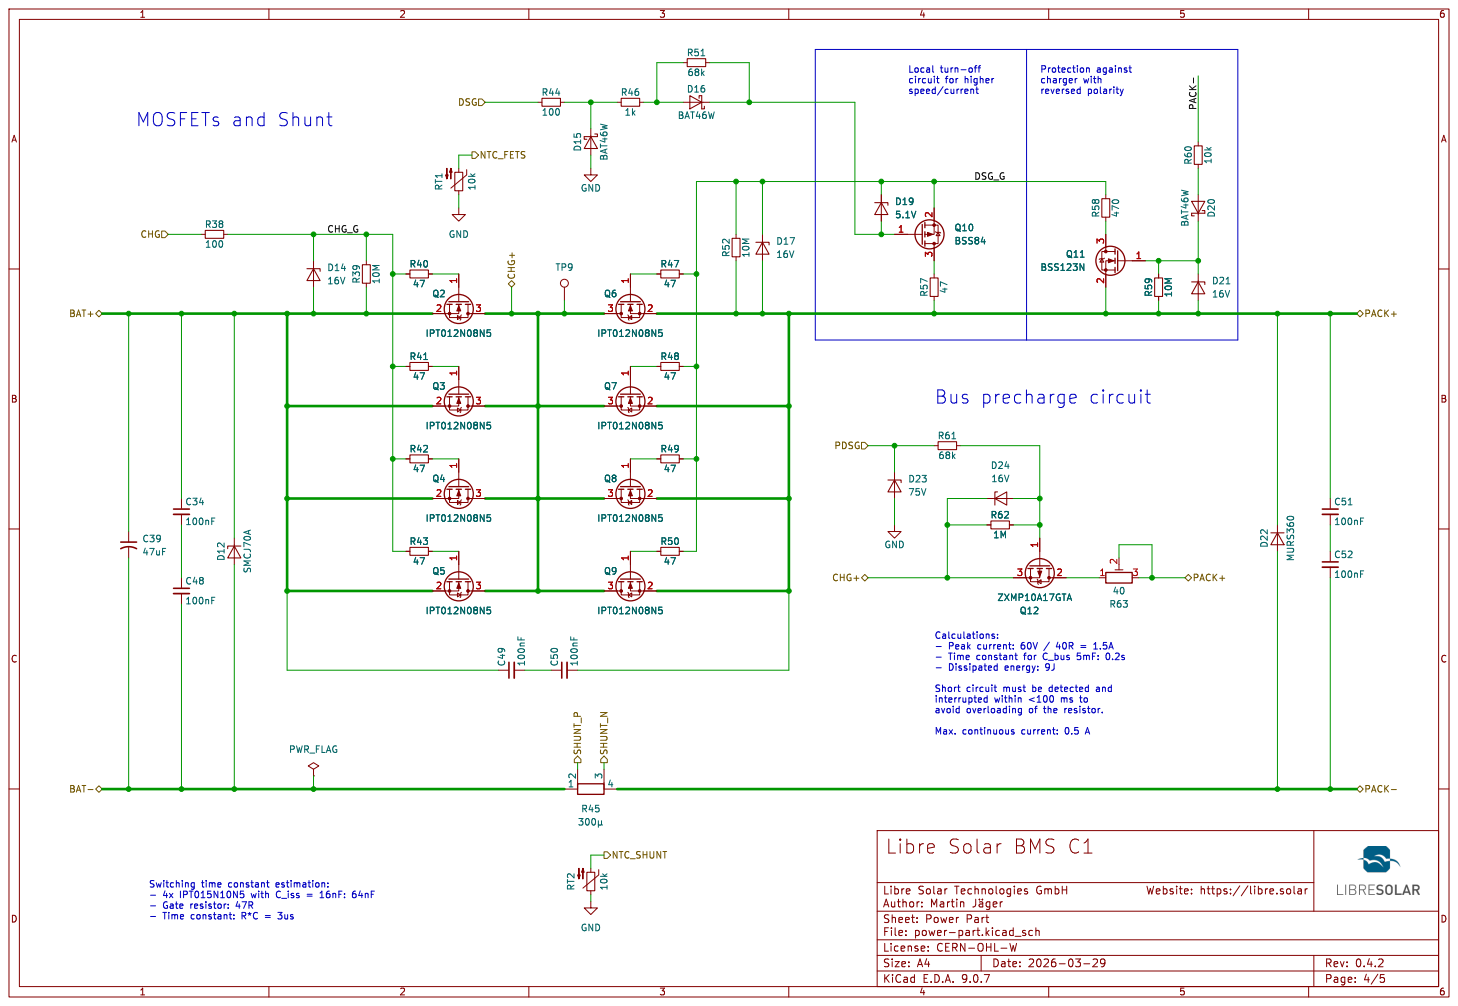
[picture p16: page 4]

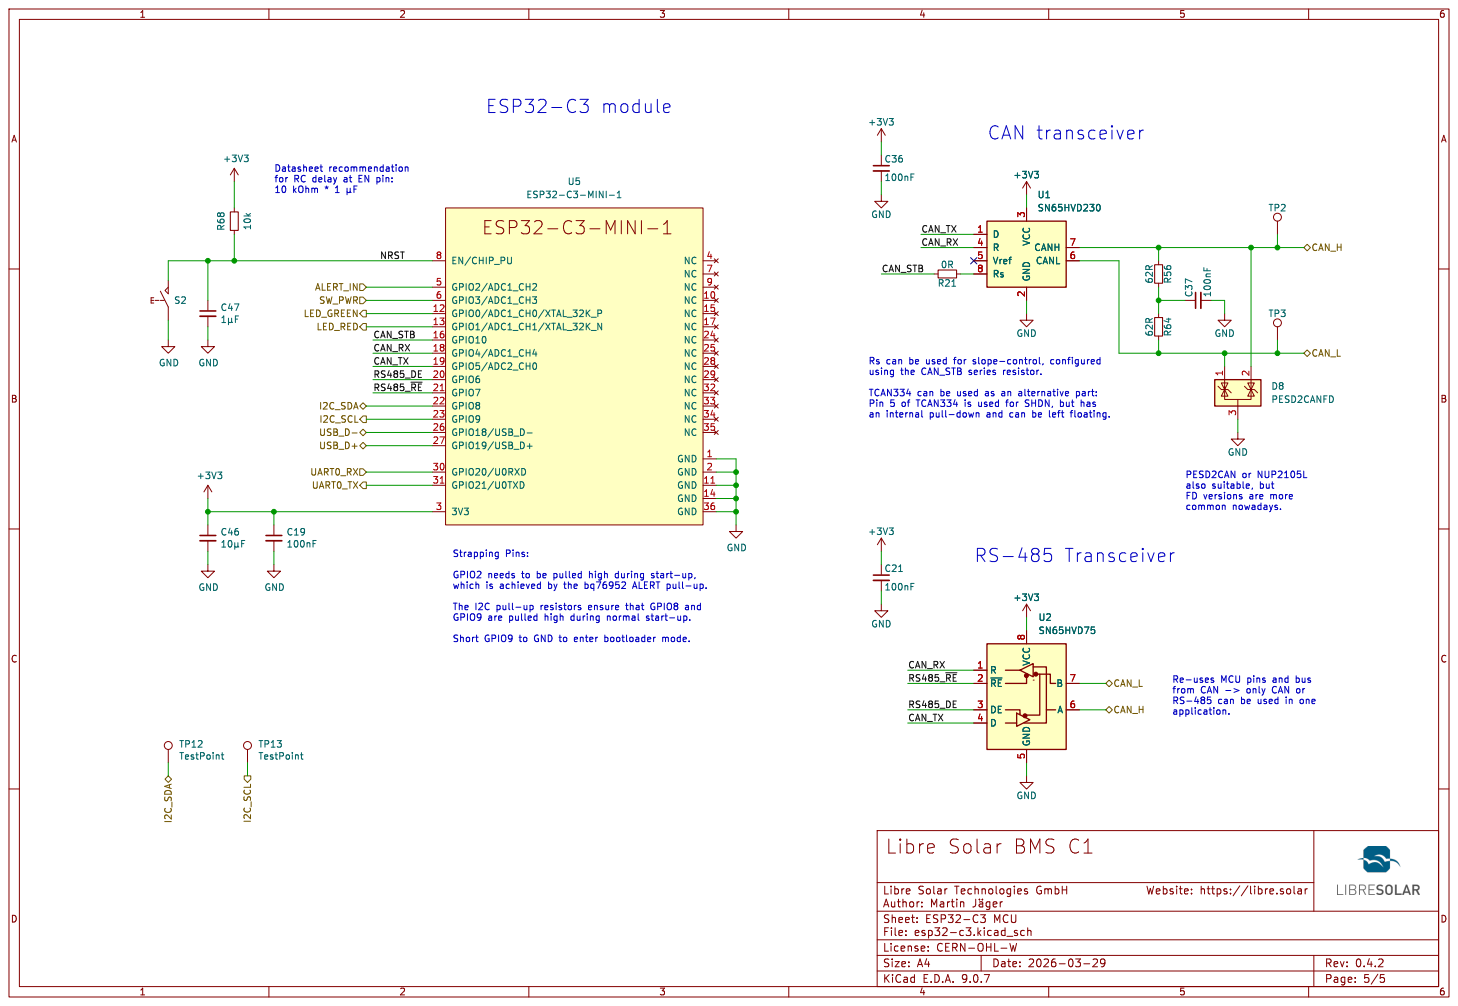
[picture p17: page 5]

for RC delay at EN pin: 10 kOhm * 1 þÿµF

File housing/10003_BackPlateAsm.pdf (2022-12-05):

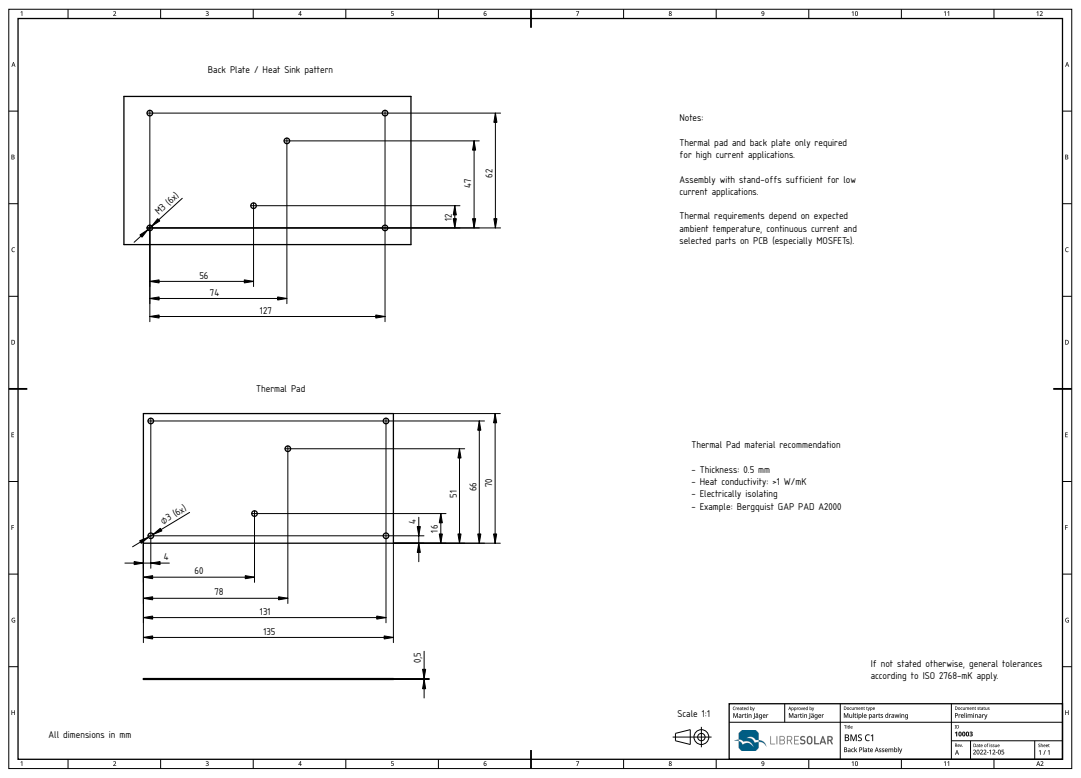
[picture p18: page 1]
Thermal Pad; Scale 1:1

Back Plate / Heat Sink pattern

Notes:
Thermal pad and back plate only required
for high current applications.
Assembly with stand-offs sufficient for low
current applications.
Thermal requirements depend on expected
ambient temperature, continuous current and
selected parts on PCB (especially MOSFETs).

Thermal Pad material recommendation
- Thickness: 0.5 mm
- Heat conductivity: >1 W/mK
- Electrically isolating
- Example: Bergquist GAP PAD A2000

If not stated otherwise, general tolerances
according to ISO 2768-mK apply.

All dimensions in mm

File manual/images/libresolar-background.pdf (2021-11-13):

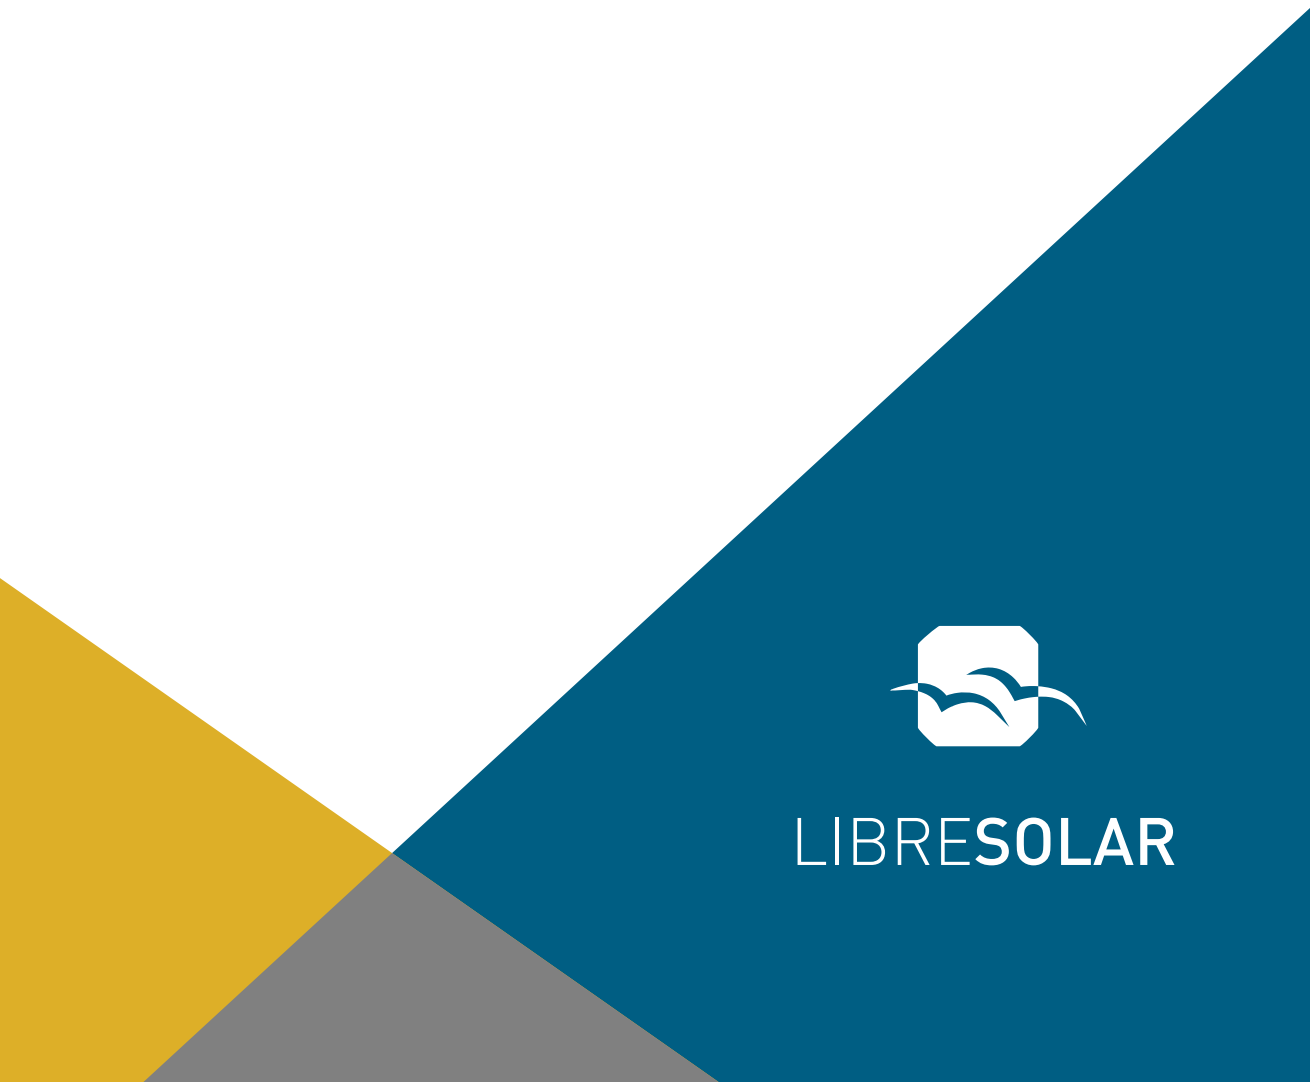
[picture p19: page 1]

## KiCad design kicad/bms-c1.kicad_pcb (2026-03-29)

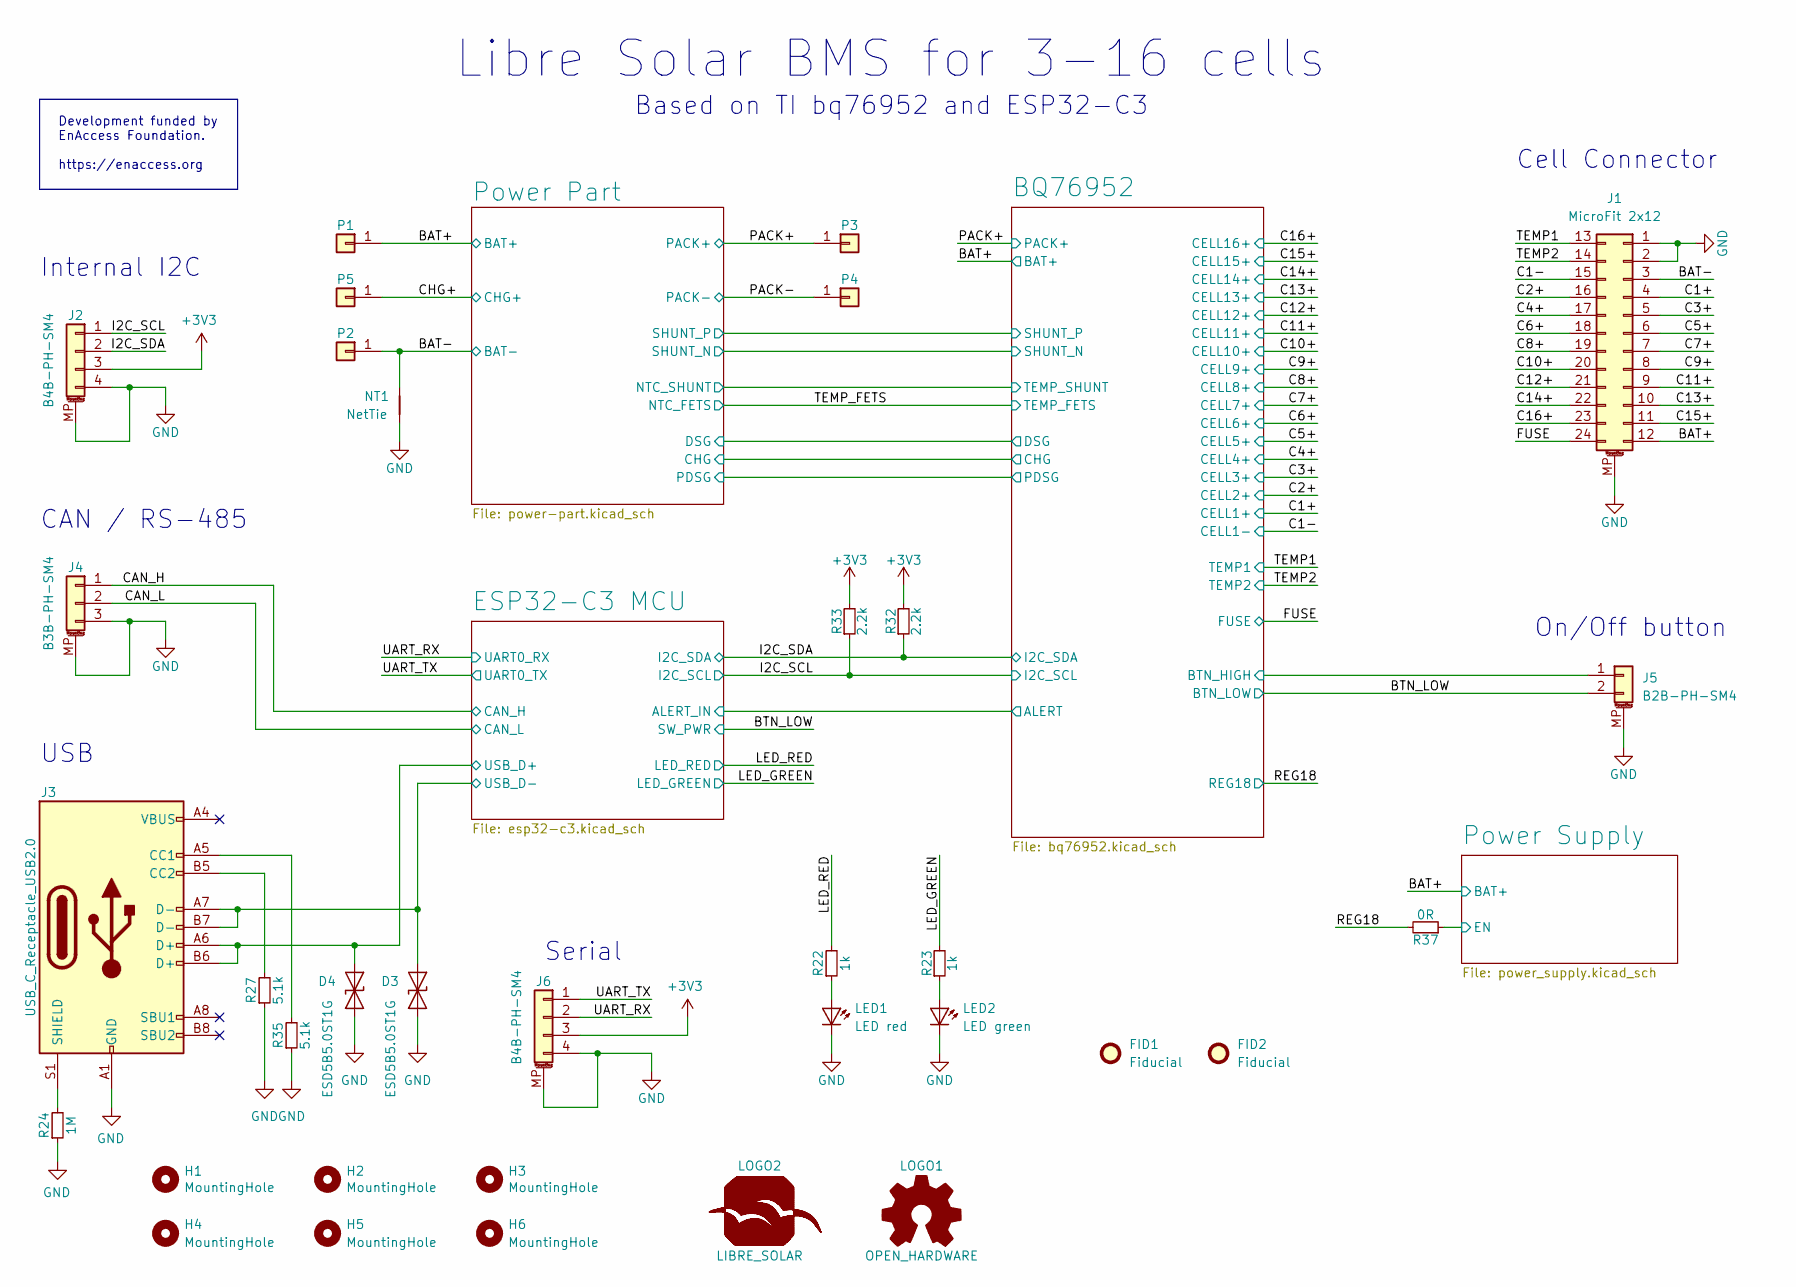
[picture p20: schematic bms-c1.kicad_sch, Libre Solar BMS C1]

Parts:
D3, D4: ESD5B5.0ST1G; D_SOD-523; PartNumber ESD5B5.0ST1G; LCSC C93623
FID1, FID2: Fiducial; Fiducial_1mm_Mask2mm
H1, H2, H3, H4, H5, H6: MountingHole; MountingHole_3.2mm_M3_Pad_TopBottom
J1: MicroFit 2x12; Molex_Micro-Fit_3.0_43045-2410_2x12-1MP_P3.00mm_Horizontal; PartNumber 662024231722
J2, J6: B4B-PH-SM4; JST_PH_B4B-PH-SM4-TB_1x04-1MP_P2.00mm_Vertical; PartNumber B4B-PH-SM4-TB(LF)(SN); LCSC C160354
J3: USB_C_Receptacle_USB2.0; USB_C_Receptacle_GCT_USB4105-xx-A_16P_TopMnt_Horizontal; PartNumber USB4105-GF-A
J4: B3B-PH-SM4; JST_PH_B3B-PH-SM4-TB_1x03-1MP_P2.00mm_Vertical; PartNumber B3B-PH-SM4-TB(LF)(SN); LCSC C160353
J5: B2B-PH-SM4; JST_PH_B2B-PH-SM4-TB_1x02-1MP_P2.00mm_Vertical; PartNumber B2B-PH-SM4-TB(LF)(SN); LCSC C160352
LED1: LED red; LED_0603_1608Metric; PartNumber LTST-C190KRKT; LCSC C94869
LED2: LED green; LED_0603_1608Metric; PartNumber LTST-C190KGKT; LCSC C125094
LOGO1: OPEN_HARDWARE; OSHW-Logo_5.7x6mm_SilkScreen
LOGO2: LIBRE_SOLAR; LIBRESOLAR_LOGO
NT1: NetTie; NetTie-2_SMD_Pad0.5mm
P1, P2, P3, P4: CONN_01X01; Wuerth_PowerOne_SMD_LF990005; PartNumber 225852-E; LCSC C3217898
P5: CONN_01X01; SolderWirePad_1x01_SMD_5x10mm
R22, R23: 1k; R_0603_1608; PartNumber RC0603FR-071KL
R24: 1M; R_0603_1608; PartNumber RC0603FR-071ML
R27, R35: 5.1k; R_0603_1608; PartNumber RC0603FR-075K1L
R32, R33: 2.2k; R_0603_1608; PartNumber RC0603FR-072K2L
R37: 0R; R_0603_1608; PartNumber RC0603FR-070RL

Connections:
+3V3: J2.3, J6.3, R32.2, R33.2; also elsewhere on the board
/BAT+: J1.12, P1.1; also elsewhere on the board
/BAT-: J1.3, NT1.1, P2.1; also elsewhere on the board
/BQ76952/BTN_HIGH: J5.1; also elsewhere on the board
/BTN_LOW: J5.2; also elsewhere on the board
/C1+: J1.4; also elsewhere on the board
/C1-: J1.15; also elsewhere on the board
/C2+: J1.16; also elsewhere on the board
/C3+: J1.5; also elsewhere on the board
/C4+: J1.17; also elsewhere on the board
/C5+: J1.6; also elsewhere on the board
/C6+: J1.18; also elsewhere on the board
/C7+: J1.7; also elsewhere on the board
/C8+: J1.19; also elsewhere on the board
/C9+: J1.8; also elsewhere on the board
/C10+: J1.20; also elsewhere on the board
/C11+: J1.9; also elsewhere on the board
/C12+: J1.21; also elsewhere on the board
/C13+: J1.10; also elsewhere on the board
/C14+: J1.22; also elsewhere on the board
/C15+: J1.11; also elsewhere on the board
/C16+: J1.23; also elsewhere on the board
/CAN_H: J4.1; also elsewhere on the board
/CAN_L: J4.2; also elsewhere on the board
/CHG+: P5.1; also elsewhere on the board
/ESP32-C3 MCU/USB_D+: D4.2 (A2), J3.A6 (D+), J3.B6 (D+); also elsewhere on the board
/ESP32-C3 MCU/USB_D-: D3.2 (A2), J3.A7 (D-), J3.B7 (D-); also elsewhere on the board
/FUSE: J1.24; also elsewhere on the board
/I2C_SCL: J2.1, R33.1; also elsewhere on the board
/I2C_SDA: J2.2, R32.1; also elsewhere on the board
/LED_GREEN: R23.2; also elsewhere on the board
/LED_RED: R22.2; also elsewhere on the board
/PACK+: P3.1; also elsewhere on the board
/PACK-: P4.1; also elsewhere on the board
/Power Supply/EN: R37.1; also elsewhere on the board
/REG18: R37.2; also elsewhere on the board
/TEMP1: J1.13; also elsewhere on the board
/TEMP2: J1.14; also elsewhere on the board
/UART_RX: J6.2; also elsewhere on the board
/UART_TX: J6.1; also elsewhere on the board
GND: D3.1 (A1), D4.1 (A1), J1.1, J1.2, J1.MP (MountPin), J2.4, J2.MP (MountPin), J3.A1 (GND), J3.A12 (GND), J3.B1 (GND), J3.B12 (GND), J4.3, J4.MP (MountPin), J5.MP (MountPin), J6.4, J6.MP (MountPin), LED1.1 (K), LED2.1 (K), NT1.2, R24.1, R27.1, R35.1; also elsewhere on the board
unnamed: J3.A5 (CC1), R35.2
unnamed: J3.B5 (CC2), R27.2
unnamed: J3.S1 (SHIELD), R24.2
unnamed: J3.A4 (VBUS), J3.A9 (VBUS), J3.B4 (VBUS), J3.B9 (VBUS)
unnamed: LED1.2 (A), R22.1
unnamed: LED2.2 (A), R23.1

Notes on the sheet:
Based on TI bq76952 and ESP32-C3
CAN / RS-485
Development funded by EnAccess Foundation. https://enaccess.org
USB
Serial
Libre Solar BMS for 3-16 cells
Cell Connector
Internal I2C
On/Off button

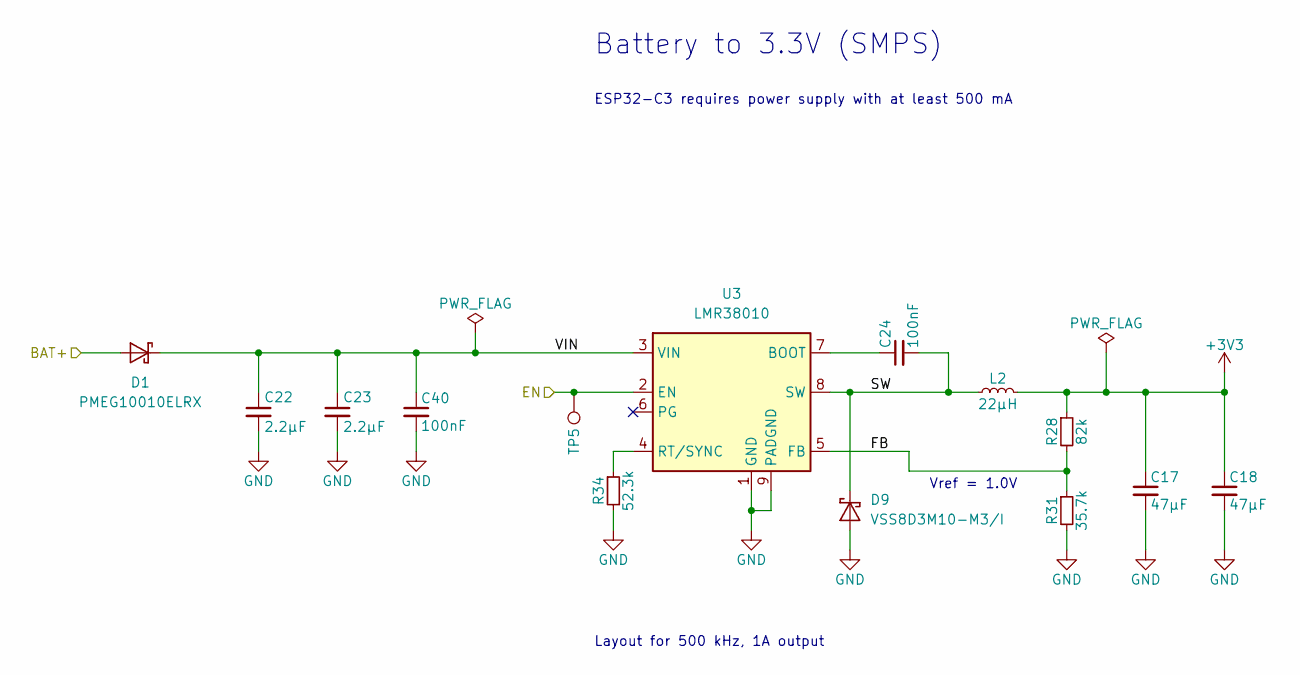
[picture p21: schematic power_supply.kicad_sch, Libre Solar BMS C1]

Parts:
C17, C18: 47µF; C_1206_3216; PartNumber CL31A476MPHNNNE; LCSC C525654
C22, C23: 2.2µF; C_1206_3216; PartNumber CL31B225KCHSNNE; LCSC C55151
C24, C40: 100nF; C_0603_1608; PartNumber CL10B104KC8NNNC; LCSC C15725
D1: PMEG10010ELRX; D_SOD-123F; PartNumber PMEG10010ELRX; LCSC C179426
D9: VSS8D3M10-M3/I; D_SOD-128; PartNumber VSS8D3M10-M3/H; LCSC C3760174
L2: 22µH; Bourns_SRN8040TA; PartNumber SRN8040-220M; LCSC C92946
R28: 82k; R_0603_1608; PartNumber RC0603FR-0782KL
R31: 35.7k; R_0603_1608; PartNumber RC0603FR-0735K7L
R34: 52.3k; R_0603_1608; PartNumber RC0603FR-0752K3L
TP5: TestPoint; TestPoint_Pad_D1.5mm
U3: LMR38010; SOIC-8-1EP_3.9x4.9mm_P1.27mm_EP2.4x3.1mm_ThermalVias; PartNumber LMR38010SDDAR; LCSC C3192337

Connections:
+3V3: C17.1, C18.1, L2.2, R28.1; also elsewhere on the board
/BAT+: D1.2 (A); also elsewhere on the board
/Power Supply/EN: TP5.1, U3.2 (EN); also elsewhere on the board
/Power Supply/FB: R28.2, R31.1, U3.5 (FB)
/Power Supply/SW: C24.2, D9.1 (K), L2.1, U3.8 (SW)
/Power Supply/VIN: C22.1, C23.1, C40.1, D1.1 (K), U3.3 (VIN)
GND: C17.2, C18.2, C22.2, C23.2, C40.2, D9.2 (A), R31.2, R34.2, U3.1 (GND), U3.9 (PADGND); also elsewhere on the board
unnamed: C24.1, U3.7 (BOOT)
unnamed: R34.1, U3.4 (RT/SYNC)

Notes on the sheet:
ESP32-C3 requires power supply with at least 500 mA
Layout for 500 kHz, 1A output
Battery to 3.3V (SMPS)
Vref = 1.0V

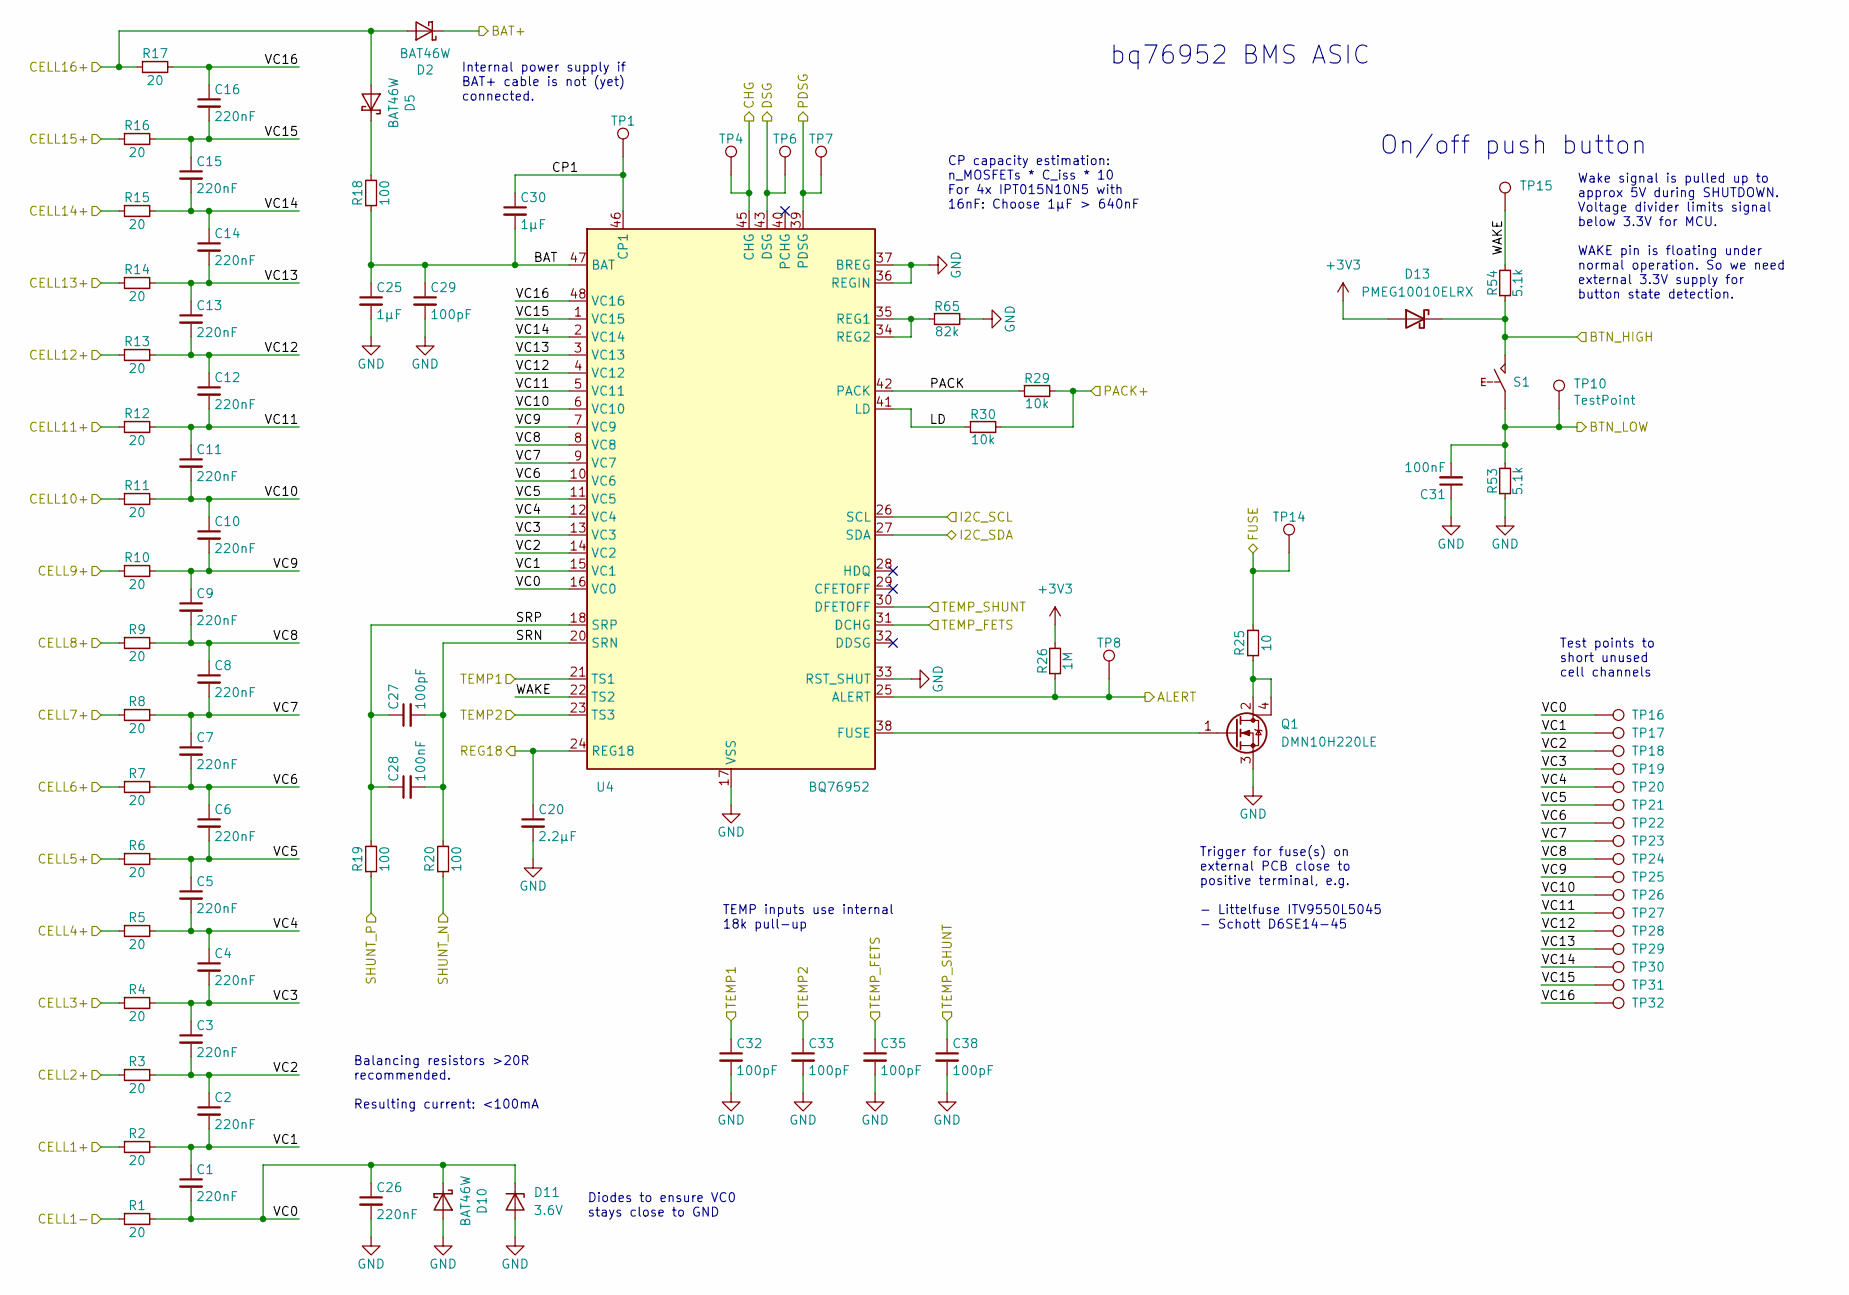
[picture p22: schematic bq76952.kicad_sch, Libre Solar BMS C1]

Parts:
C1, C2, C3, C4, C5, C6, C7, C8, C9, C10, C11, C12, C13, C14, C15, C16, C26: 220nF; C_0603_1608; PartNumber CL10B224KA8NNNC; LCSC C21120
C20: 2.2µF; C_0603_1608; PartNumber CL10A225KP8NNNC; LCSC C1607
C25: 1µF; C_1206_3216; PartNumber CL31B105KCHNNNE; LCSC C13832
C27, C29, C32, C33, C35, C38: 100pF; C_0603_1608; PartNumber CL10C101JC8NNNC; LCSC C296717
C28, C31: 100nF; C_0603_1608; PartNumber CL10B104KC8NNNC; LCSC C15725
C30: 1µF; C_0603_1608; PartNumber CL10A105KA8NNNC; LCSC C5673
D2, D5, D10: BAT46W; D_SOD-123; PartNumber BAT46W-7-F; LCSC C83152
D11: 3.6V; D_SOD-123; PartNumber MMSZ4685T1G; LCSC C66886
D13: PMEG10010ELRX; D_SOD-123F; PartNumber PMEG10010ELRX; LCSC C179426
Q1: DMN10H220LE; SOT-223; PartNumber DMN10H220LE; LCSC C258216
R1, R2, R3, R4, R5, R6, R7, R8, R9, R10, R11, R12, R13, R14, R15, R16, R17: 20; R_2010_5025; PartNumber RC2010JK-0720RL; LCSC C163344
R18: 100; R_1206_3216; PartNumber RC1206FR-07100RL
R19, R20: 100; R_0603_1608; PartNumber RC0603FR-07100RL
R25: 10; R_1206_3216; PartNumber RC1206FR-0710RL
R26: 1M; R_0603_1608; PartNumber RC0603FR-071ML
R29, R30: 10k; R_0603_1608; PartNumber RC0603FR-0710KL
R53, R54: 5.1k; R_0603_1608; PartNumber RC0603FR-075K1L
R65: 82k; R_0603_1608; PartNumber RC0603FR-0782KL
S1: SW_PUSH; SW_SPST_TL3305A; PartNumber TL3305AF160QG; LCSC C2886899
TP1, TP4, TP6, TP7, TP8, TP10, TP14, TP15: TestPoint; TestPoint_Pad_D1.5mm
TP16, TP17, TP18, TP19, TP20, TP21, TP22, TP23, TP24, TP25, TP26, TP27, TP28, TP29, TP30, TP31, TP32: TestPoint; TestPoint_Pad_1.0x1.0mm
U4: BQ76952; TQFP-48_7x7mm_P0.5mm; PartNumber BQ76952PFBR; LCSC C2862742

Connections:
+3V3: D13.2 (A), R26.2; also elsewhere on the board
/BAT+: D2.1 (K); also elsewhere on the board
/BQ76952/ALERT: R26.1, TP8.1, U4.25 (ALERT); also elsewhere on the board
/BQ76952/BAT: C25.1, C29.1, C30.2, R18.1, U4.47 (BAT)
/BQ76952/BTN_HIGH: D13.1 (K), R54.1, S1.2; also elsewhere on the board
/BQ76952/CHG: TP4.1, U4.45 (CHG); also elsewhere on the board
/BQ76952/CP1: C30.1, TP1.1, U4.46 (CP1)
/BQ76952/DSG: TP6.1, U4.43 (DSG); also elsewhere on the board
/BQ76952/LD: R30.1, U4.41 (LD)
/BQ76952/PACK: R29.1, U4.42 (PACK)
/BQ76952/PDSG: TP7.1, U4.39 (PDSG); also elsewhere on the board
/BQ76952/SHUNT_N: R20.1; also elsewhere on the board
/BQ76952/SHUNT_P: R19.1; also elsewhere on the board
/BQ76952/SRN: C27.2, C28.2, R20.2, U4.20 (SRN)
/BQ76952/SRP: C27.1, C28.1, R19.2, U4.18 (SRP)
/BQ76952/TEMP_SHUNT: C38.1, U4.30 (DFETOFF); also elsewhere on the board
/BQ76952/VC0: C1.2, C26.1, D10.1 (K), D11.1 (K), R1.2, TP16.1, U4.16 (VC0)
/BQ76952/VC1: C1.1, C2.2, R2.2, TP17.1, U4.15 (VC1)
/BQ76952/VC2: C2.1, C3.2, R3.2, TP18.1, U4.14 (VC2)
/BQ76952/VC3: C3.1, C4.2, R4.2, TP19.1, U4.13 (VC3)
/BQ76952/VC4: C4.1, C5.2, R5.2, TP20.1, U4.12 (VC4)
/BQ76952/VC5: C5.1, C6.2, R6.2, TP21.1, U4.11 (VC5)
/BQ76952/VC6: C6.1, C7.2, R7.2, TP22.1, U4.10 (VC6)
/BQ76952/VC7: C7.1, C8.2, R8.2, TP23.1, U4.9 (VC7)
/BQ76952/VC8: C8.1, C9.2, R9.2, TP24.1, U4.8 (VC8)
/BQ76952/VC9: C9.1, C10.2, R10.2, TP25.1, U4.7 (VC9)
/BQ76952/VC10: C10.1, C11.2, R11.2, TP26.1, U4.6 (VC10)
/BQ76952/VC11: C11.1, C12.2, R12.2, TP27.1, U4.5 (VC11)
/BQ76952/VC12: C12.1, C13.2, R13.2, TP28.1, U4.4 (VC12)
/BQ76952/VC13: C13.1, C14.2, R14.2, TP29.1, U4.3 (VC13)
/BQ76952/VC14: C14.1, C15.2, R15.2, TP30.1, U4.2 (VC14)
/BQ76952/VC15: C15.1, C16.2, R16.2, TP31.1, U4.1 (VC15)
/BQ76952/VC16: C16.1, R17.2, TP32.1, U4.48 (VC16)
/BQ76952/WAKE: R54.2, TP15.1, U4.22 (TS2)
/BTN_LOW: C31.2, R53.2, S1.1, TP10.1; also elsewhere on the board
/C1+: R2.1; also elsewhere on the board
/C1-: R1.1; also elsewhere on the board
/C2+: R3.1; also elsewhere on the board
/C3+: R4.1; also elsewhere on the board
/C4+: R5.1; also elsewhere on the board
/C5+: R6.1; also elsewhere on the board
/C6+: R7.1; also elsewhere on the board
/C7+: R8.1; also elsewhere on the board
/C8+: R9.1; also elsewhere on the board
/C9+: R10.1; also elsewhere on the board
/C10+: R11.1; also elsewhere on the board
/C11+: R12.1; also elsewhere on the board
/C12+: R13.1; also elsewhere on the board
/C13+: R14.1; also elsewhere on the board
/C14+: R15.1; also elsewhere on the board
/C15+: R16.1; also elsewhere on the board
/C16+: D2.2 (A), D5.2 (A), R17.1; also elsewhere on the board
/FUSE: R25.2, TP14.1; also elsewhere on the board
/I2C_SCL: U4.26 (SCL); also elsewhere on the board
/I2C_SDA: U4.27 (SDA); also elsewhere on the board
/PACK+: R29.2, R30.2; also elsewhere on the board
/REG18: C20.1, U4.24 (REG18); also elsewhere on the board
/TEMP1: C32.1, U4.21 (TS1); also elsewhere on the board
/TEMP2: C33.1, U4.23 (TS3); also elsewhere on the board
/TEMP_FETS: C35.1, U4.31 (DCHG); also elsewhere on the board
GND: C20.2, C25.2, C26.2, C29.2, C31.1, C32.2, C33.2, C35.2, C38.2, D10.2 (A), D11.2 (A), Q1.3 (S), R53.1, R65.2, U4.17 (VSS), U4.33 (RST_SHUT), U4.36 (REGIN), U4.37 (BREG); also elsewhere on the board
unnamed: D5.1 (K), R18.2
unnamed: Q1.2 (D), Q1.4 (D), R25.1
unnamed: Q1.1 (G), U4.38 (FUSE)
unnamed: R65.1, U4.34 (REG2), U4.35 (REG1)

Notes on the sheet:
TEMP inputs use internal 18k pull-up
CP capacity estimation: n_MOSFETs * C_iss * 10 For 4x IPT015N10N5 with 16nF: Choose 1µF > 640nF
bq76952 BMS ASIC
Wake signal is pulled up to approx 5V during SHUTDOWN. Voltage divider limits signal below 3.3V for MCU. WAKE pin is floating under normal operation. So we need external 3.3V supply for button state detection.
On/off push button
Trigger for fuse(s) on external PCB close to positive terminal, e.g. - Littelfuse ITV9550L5045 - Schott D6SE14-45
Balancing resistors >20R recommended. Resulting current: <100mA
Test points to short unused cell channels
Internal power supply if BAT+ cable is not (yet) connected.
Diodes to ensure VC0 stays close to GND

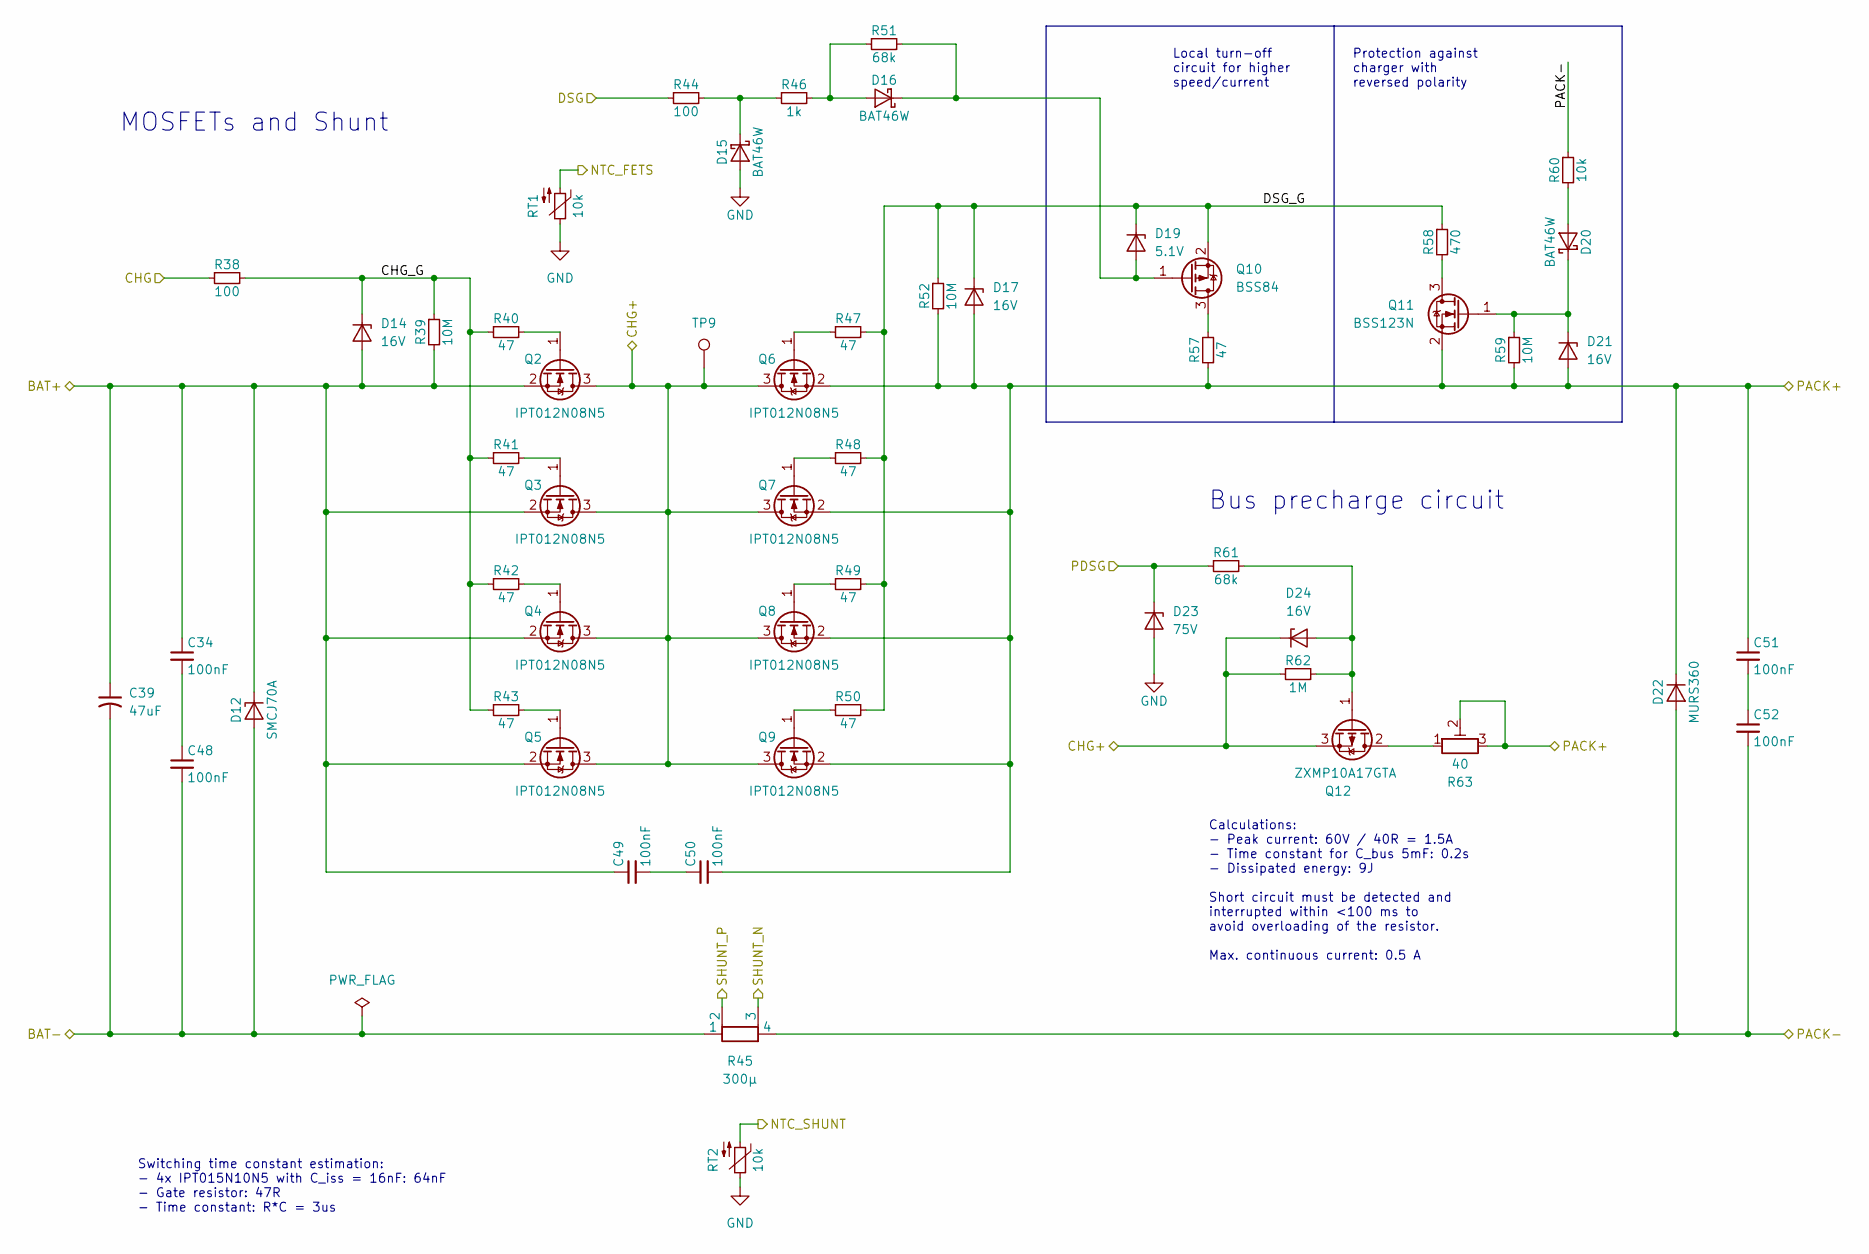
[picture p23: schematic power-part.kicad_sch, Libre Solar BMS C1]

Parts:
C34, C48, C49, C50, C51, C52: 100nF; C_0603_1608; PartNumber CL10B104KC8NNNC; LCSC C15725
C39: 47uF; CP_Elec_10x10; PartNumber AEK1010470M100R
D12: SMCJ70A; D_SMC; PartNumber SMCJ70A; LCSC C135194
D14, D17, D21, D24: 16V; D_SOD-123; PartNumber MMSZ5246B-7-F; LCSC C282317
D15, D16, D20: BAT46W; D_SOD-123; PartNumber BAT46W-7-F; LCSC C83152
D19: 5.1V; D_SOD-323; PartNumber BZT52C5V1S-7-F; LCSC C151348
D22: MURS360; D_SMC; PartNumber MURS360; LCSC C388245
D23: 75V; D_SOD-123; PartNumber MMSZ5267BT1G; LCSC C266795
Q2, Q3, Q4, Q5, Q6, Q7, Q8, Q9: IPT012N08N5; Infineon_PG-HSOF-8-1_ThermalVias; PartNumber IPT012N08N5; LCSC C531199
Q10: BSS84; SOT-23; PartNumber BSS84AK,215; LCSC C127273
Q11: BSS123N; SOT-23; PartNumber BSS123N H6327; LCSC C534594
Q12: ZXMP10A17GTA; SOT-223-3_TabPin2; PartNumber ZXMP10A17GTA; LCSC C32998
R38, R44: 100; R_0603_1608; PartNumber RC0603FR-07100RL
R39, R52, R59: 10M; R_0603_1608; PartNumber RC0603FR-0710ML
R40, R41, R42, R43, R47, R48, R49, R50, R57: 47; R_0603_1608; PartNumber RC0603FR-0747RL
R45: 300µ; R_Shunt_5931_Kelvin; PartNumber WSLP5931L3000FEA
R46: 1k; R_0603_1608; PartNumber RC0603FR-071KL
R51, R61: 68k; R_0603_1608; PartNumber RC0603FR-0768KL
R58: 470; R_0603_1608; PartNumber RC0603FR-07470RL
R60: 10k; R_0603_1608; PartNumber RC0603FR-0710KL
R62: 1M; R_0603_1608; PartNumber RC0603FR-071ML
R63: 40; Bourns_PWR163; PartNumber PWR163S-25-40R0FE
RT1, RT2: 10k; R_0603_1608; PartNumber NTCG163JF103FT1S; LCSC C406719
TP9: TestPoint; TestPoint_Pad_D1.5mm

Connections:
/BAT+: C34.1, C39.1, C49.1, D12.1 (K), D14.2 (A), Q2.2 (S), Q3.2 (S), Q4.2 (S), Q5.2 (S), R39.2; also elsewhere on the board
/BAT-: C39.2, C48.2, D12.2 (A), R45.1; also elsewhere on the board
/BQ76952/CHG: R38.1; also elsewhere on the board
/BQ76952/DSG: R44.1; also elsewhere on the board
/BQ76952/PDSG: D23.1 (K), R61.1; also elsewhere on the board
/BQ76952/SHUNT_N: R45.3; also elsewhere on the board
/BQ76952/SHUNT_P: R45.2; also elsewhere on the board
/BQ76952/TEMP_SHUNT: RT2.2; also elsewhere on the board
/CHG+: D24.1 (K), Q2.3 (D), Q3.3 (D), Q4.3 (D), Q5.3 (D), Q6.3 (D), Q7.3 (D), Q8.3 (D), Q9.3 (D), Q12.3 (S), R62.1, TP9.1; also elsewhere on the board
/PACK+: C50.2, C51.1, D17.2 (A), D21.2 (A), D22.1 (K), Q6.2 (S), Q7.2 (S), Q8.2 (S), Q9.2 (S), Q11.2 (S), R52.2, R57.1, R59.2, R63.2, R63.3; also elsewhere on the board
/PACK-: C52.2, D22.2 (A), R45.4, R60.1; also elsewhere on the board
/Power Part/CHG_G: D14.1 (K), R38.2, R39.1, R40.1, R41.1, R42.1, R43.1
/Power Part/DSG_G: D17.1 (K), D19.1 (K), Q10.2 (S), R47.2, R48.2, R49.2, R50.2, R52.1, R58.1
/TEMP_FETS: RT1.2; also elsewhere on the board
GND: D15.2 (A), D23.2 (A), RT1.1, RT2.1; also elsewhere on the board
unnamed: C34.2, C48.1
unnamed: C49.2, C50.1
unnamed: C51.2, C52.1
unnamed: D15.1 (K), R44.2, R46.1
unnamed: D16.2 (A), R46.2, R51.1
unnamed: D16.1 (K), D19.2 (A), Q10.1 (G), R51.2
unnamed: D20.2 (A), R60.2
unnamed: D20.1 (K), D21.1 (K), Q11.1 (G), R59.1
unnamed: D24.2 (A), Q12.1 (G), R61.2, R62.2
unnamed: Q2.1 (G), R40.2
unnamed: Q3.1 (G), R41.2
unnamed: Q4.1 (G), R42.2
unnamed: Q5.1 (G), R43.2
unnamed: Q6.1 (G), R47.1
unnamed: Q7.1 (G), R48.1
unnamed: Q8.1 (G), R49.1
unnamed: Q9.1 (G), R50.1
unnamed: Q10.3 (D), R57.2
unnamed: Q11.3 (D), R58.2
unnamed: Q12.2 (D), R63.1

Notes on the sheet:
Protection against charger with reversed polarity
Switching time constant estimation: - 4x IPT015N10N5 with C_iss = 16nF: 64nF - Gate resistor: 47R - Time constant: R*C = 3us
MOSFETs and Shunt
Local turn-off circuit for higher speed/current
Bus precharge circuit
Calculations: - Peak current: 60V / 40R = 1.5A - Time constant for C_bus 5mF: 0.2s - Dissipated energy: 9J Short circuit must be detected and interrupted within <100 ms to avoid overloading of the resistor. Max. continuous current: 0.5 A

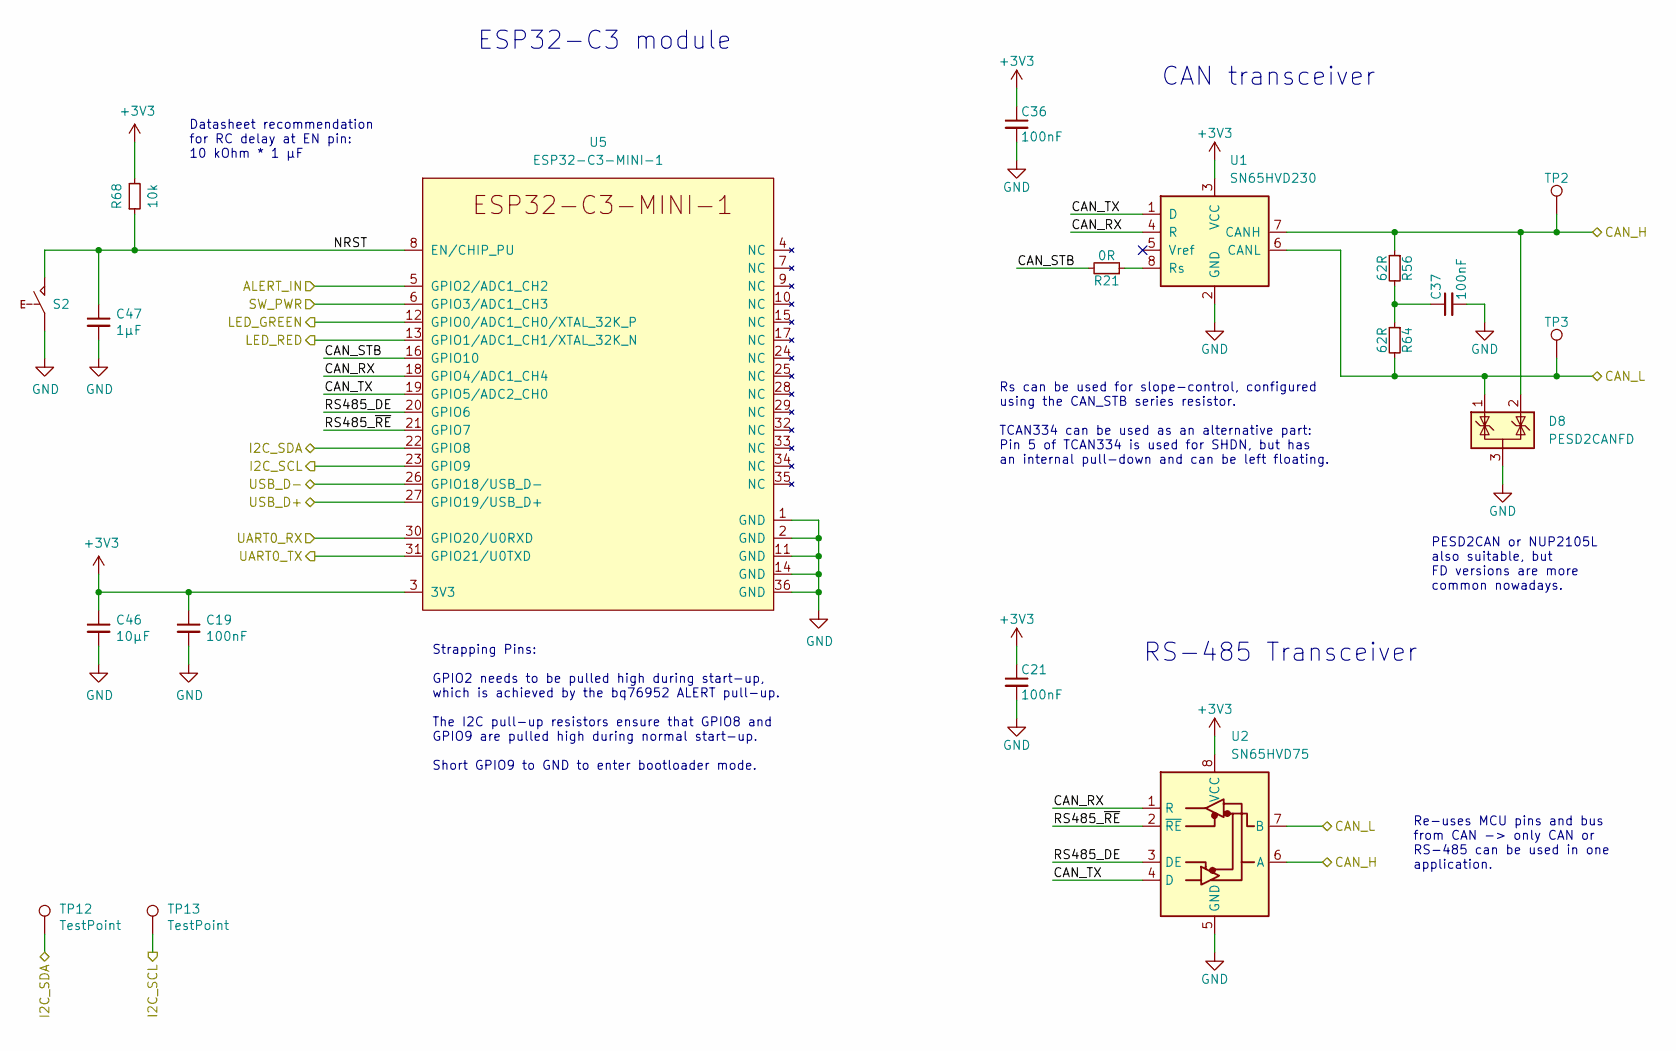
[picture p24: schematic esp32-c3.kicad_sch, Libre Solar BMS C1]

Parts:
C19, C21, C36, C37: 100nF; C_0603_1608; PartNumber CL10B104KC8NNNC; LCSC C15725
C46: 10µF; C_0805_2012; PartNumber CL21A106KPFNNNE; LCSC C17024
C47: 1µF; C_0603_1608; PartNumber CL10A105KA8NNNC; LCSC C5673
D8: PESD2CANFD; SOT-23; PartNumber PESD2CANFD24V-TR; LCSC C552486
R21: 0R; R_0603_1608; PartNumber RC0603FR-070RL
R56, R64: 62R; R_0603_1608; PartNumber RC0603FR-0762RL
R68: 10k; R_0603_1608; PartNumber RC0603FR-0710KL
S2: SW_PUSH; SW_SPST_TL3305A; PartNumber TL3305AF160QG; LCSC C2886899
TP2, TP3, TP12, TP13: TestPoint; TestPoint_Pad_D1.5mm
U1: SN65HVD230; SOIC-8_3.9x4.9mm_P1.27mm; PartNumber SN65HVD230DR; LCSC C12084
U2: SN65HVD75; SOIC-8_3.9x4.9mm_P1.27mm; PartNumber SN65HVD75DR; LCSC C57928
U5: ESP32-C3-MINI-1; PartNumber ESP32-C3-MINI-1-N4; LCSC C2838502

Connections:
+3V3: C19.1, C21.1, C36.1, C46.1, R68.2, U1.3 (VCC), U2.8 (VCC), U5.3 (3V3); also elsewhere on the board
/BQ76952/ALERT: U5.5 (GPIO2/ADC1_CH2); also elsewhere on the board
/BTN_LOW: U5.6 (GPIO3/ADC1_CH3); also elsewhere on the board
/CAN_H: D8.2 (K), R56.1, TP2.1, U1.7 (CANH), U2.6 (A); also elsewhere on the board
/CAN_L: D8.1 (K), R64.2, TP3.1, U1.6 (CANL), U2.7 (B); also elsewhere on the board
/ESP32-C3 MCU/CAN_RX: U1.4 (R), U2.1 (R), U5.18 (GPIO4/ADC1_CH4)
/ESP32-C3 MCU/CAN_STB: R21.2, U5.16 (GPIO10)
/ESP32-C3 MCU/CAN_TX: U1.1 (D), U2.4 (D), U5.19 (GPIO5/ADC2_CH0)
/ESP32-C3 MCU/NRST: C47.1, R68.1, S2.2, U5.8 (EN/CHIP_PU)
/ESP32-C3 MCU/RS485_DE: U2.3 (DE), U5.20 (GPIO6)
/ESP32-C3 MCU/RS485_~RE: U2.2 (~RE), U5.21 (GPIO7)
/ESP32-C3 MCU/USB_D+: U5.27 (GPIO19/USB_D+); also elsewhere on the board
/ESP32-C3 MCU/USB_D-: U5.26 (GPIO18/USB_D-); also elsewhere on the board
/I2C_SCL: TP13.1, U5.23 (GPIO9); also elsewhere on the board
/I2C_SDA: TP12.1, U5.22 (GPIO8); also elsewhere on the board
/LED_GREEN: U5.12 (GPIO0/ADC1_CH0/XTAL_32K_P); also elsewhere on the board
/LED_RED: U5.13 (GPIO1/ADC1_CH1/XTAL_32K_N); also elsewhere on the board
/UART_RX: U5.30 (GPIO20/U0RXD); also elsewhere on the board
/UART_TX: U5.31 (GPIO21/U0TXD); also elsewhere on the board
GND: C19.2, C21.2, C36.2, C37.2, C46.2, C47.2, D8.3 (A), S2.1, U1.2 (GND), U2.5 (GND), U5.1 (GND), U5.2 (GND), U5.11 (GND), U5.14 (GND), U5.36 (GND); also elsewhere on the board
unnamed: C37.1, R56.2, R64.1
unnamed: R21.1, U1.8 (Rs)

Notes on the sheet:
Datasheet recommendation for RC delay at EN pin: 10 kOhm * 1 µF
Strapping Pins: GPIO2 needs to be pulled high during start-up, which is achieved by the bq76952 ALERT pull-up. The I2C pull-up resistors ensure that GPIO8 and GPIO9 are pulled high during normal start-up. Short GPIO9 to GND to enter bootloader mode.
RS-485 Transceiver
Re-uses MCU pins and bus from CAN -> only CAN or RS-485 can be used in one application.
PESD2CAN or NUP2105L also suitable, but FD versions are more common nowadays.
CAN transceiver
ESP32-C3 module
Rs can be used for slope-control, configured using the CAN_STB series resistor. TCAN334 can be used as an alternative part: Pin 5 of TCAN334 is used for SHDN, but has an internal pull-down and can be left floating.

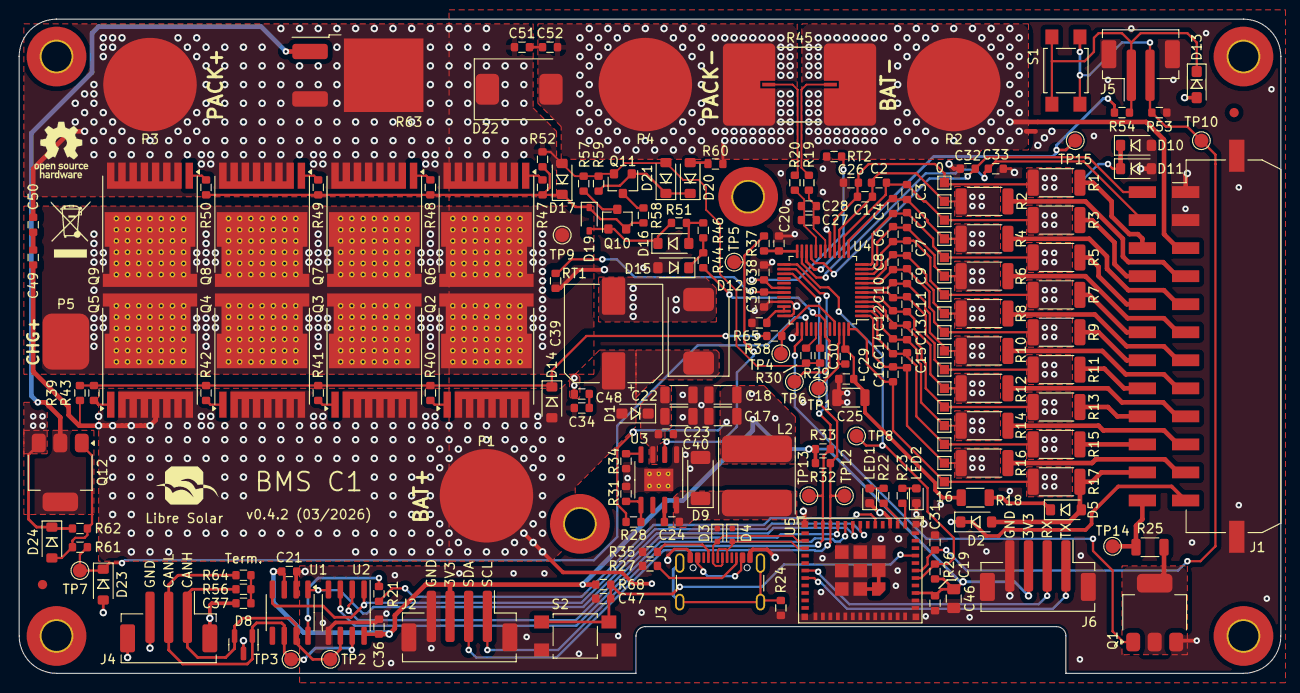
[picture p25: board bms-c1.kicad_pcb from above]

Board: 4 copper layers, 135.0 x 70.0 mm, 209 parts (0 on the bottom side), 118 nets.

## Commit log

2021-11-25 Fix some typos and improve BMS overview image
2021-11-25 Add connector, comms and shunt information
2021-11-30 First placement tests for spec document
    [bms-control-16s.kicad_pcb, bms-control-16s.kicad_sch, bms-power-100a.kicad_pcb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]
2021-12-19 Update spec based on initial reviews and feedback
    - More common SMD shunt resistor (issue #2)
    - High current connection using custom busbar instead of expensive press-fit
    terminals (issue #3)
    - RJ45 connectors for CAN not on board anymore (issue #4)
2021-12-19 Update KiCad files based on spec updates
    [bms-control-16s.kicad_pcb, bms-control-16s.kicad_sch, bms-power-100a.kicad_pcb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]
2022-01-21 WIP: Schematic almost finished
    [bms-control-16s.kicad_pcb, bms-control-16s.kicad_sch, bms-power-100a.kicad_pcb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]
2022-02-24 v0.1 design ready for review
    [bms-control-16s.kicad_pcb, bms-control-16s.kicad_sch, bms-control-16s_bom.csv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]
2022-02-25 Add heat transfer calculation and assembly picture
    [bms-100a_cooling-estimation.ods]
2022-03-15 Updates based on review comments (v0.2)
    This is the design revision that was ordered for the first prototype build.
    The pinout of the cell connector and the board-to-board connector changed
    compared to v0.1, hence it got a minor revision update.
    The control board is now a 4-layer board to improve the grounding of the
    PCB. Various other suggested improvements from the design review are also
    included in this update.
    Fixes #11, #12, #13, #17, #18, #19
    [bms-control-16s.kicad_pcb, bms-control-16s.kicad_sch, bms-control-16s_bom.csv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]
2022-08-27 Major update for BMS C1 v0.3
    This commit contains major updates of the PCB after the first prototype
    build-up and testing. Changes include:
    - Single PCB instead of stacked PCBs to simplify design and reduce cost.
    - STM32 MCU was removed due to supply shortage. Only ESP32-C3 supported.
    - Custom connectors replaced with off-the-shelf Würth Power Elements.
    - 5V power rail removed to simplify design (CAN runs on 3V3 transceiver).
    - Larger Shunt with improved footprint.
    - Optimized layout to reduce distance between IC and shunt.
    [bms-c1.kicad_pcb, bms-c1.kicad_sch, bms-c1_bom.csv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]
2022-09-27 BOM updates with a few more alternative parts
    [bms-c1.kicad_pcb, bms-c1.kicad_sch, bms-c1_bom.csv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]
2022-09-30 Board v0.3.1: Add test point for GPIO9 (BOOT) pin
    Fixes #34
    [bms-c1.kicad_pcb, bms-c1.kicad_sch, bq76952.kicad_sch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]
2022-10-28 Fix BMS overview image
2022-10-28 Add ESP32-C3 and switch part numbers
    [bq76952.kicad_sch, esp32-c3.kicad_sch]
2022-10-28 Swap D and S of Q12
    Fixes #36
    [bms-c1.kicad_pcb, power-part.kicad_sch]
2022-11-03 Remove FUSE_DETECT circuit
    Q13 was not properly tied to ground, so it was not switching on the
    voltage divider. A voltage divider that is continuously on would
    draw current even in deepsleep mode, so it is not viable for a BMS.
    I could not come up with an easy circuit that allows monitoring the
    voltage without any power consumption, so the fuse diagnosis
    mechanism is removed for now.
    [bms-c1.kicad_pcb, bms-c1.kicad_sch, bq76952.kicad_sch]
2022-11-07 Move mounting holes and improve routing
    [bms-c1.kicad_pcb, bq76952.kicad_sch]
2022-11-07 v3.2.2: Switch to SMD terminals instead of press-fit
    Rationale: These are easier to manufacture (no additional step required)
    and the PCB can be mounted onto a heat sink without any milling required.
    [bms-c1.kicad_pcb, bms-c1.kicad_sch, bms-c1_bom.csv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]
2022-11-08 All schematics on A4 and small fixes for BOM
    [bms-c1.kicad_sch, bms-c1_bom.csv, power-part.kicad_sch]
2022-11-21 v0.3.3: Final version for BMS challenge with EnAccess
    Updates compared to v0.3.2:
    - Optimization of some copper planes
    - Net tie with thicker connection to GND
    - D12 connected to Bat-
    No parts were changed, the BOM is same as before.
    [bms-c1.kicad_pcb, bms-c1.kicad_sch, bms-c1_bom.csv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]
2022-12-05 Add mechanical design files for housing integration
    [bms-c1_bom_mechanical.csv]
2023-01-20 Mirror cell connector in schematic to match with board
    [bms-c1.kicad_sch]
2023-08-30 Docs: Fix typo for LFP battery configuration (#41)
2023-12-01 v0.4.0: Multiple improvements for new board revision
    - Use LMR38010 for internal power supply (max. 80V instead of 60V)
    - Change USB connector from Micro-A to C and remove 5V power supply
    which was not working anyway. The board cannot be powered by USB
    only.
    - Add TS2 (connected to DFETOFF) to measure shunt temperature
    - Add RS-485 transceiver (sharing the connector with CAN)
    - Switch I2C pins of ESP32-C3 to GPIO8/9. This allows to re-use the
    I2C pull-ups for strapping configuration and frees two pins for the
    RS-485 transceiver RE and DE pins. Also we may get rid of the I2C
    glitches during start-up.
    - Use 80V instead of 100V power MOSFETs to reduce Rds(on).
    - Reduce DSG gate resist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
    [bms-c1.kicad_pcb, bms-c1.kicad_sch, bms-c1_bom.csv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]
2024-01-15 ci: Integrate KiBot checks for KiCad design validation
    Added a KiBot workflow to automatically validate KiCad schematics and PCB designs on push and pull request. This ensures design consistency and error checking.
    Updated .gitignore to exclude kibot outputs.
    Also, added the KiBot configuration file to define specific checks and filters, where all occurred errors are treated as warnings, providing visibility for later fixing.
2024-01-15 Docs: Fix datasheet table
    Widened the column containing `RS-485 (connector shared with CAN)` in the datasheet table to prevent text overflow into the Value column, ensuring proper layout.
2024-01-17 Fix schematic page numbers and MOSFET time constant calc
    Fixes #49
    [bms-c1.kicad_sch, power-part.kicad_sch]
2024-01-24 ci: Add PDF-diff commenting to PR workflow
    Implemented a two-stage GitHub Actions workflow for KiCad diff generation based on best practices for security. This approach, detailed in GitHub Security Lab's article (https://securitylab.github.com/research/github-actions-preventing-pwn-requests), helps prevent potential security vulnerabilities associated with the automatic execution of workflows from forked repositories. The first workflow ('kibot_diff.yml') runs the KiBot diff process, while the second workflow ('kibot_run_comment.yml') safely comments the results on pull requests.
2024-03-07 ci: pin gh action to v2_k7_1_6_3 to resolve build errors
    Fixed a build error by specifying the version of a GitHub Action to v2_k7_1_6_3. This addresses an issue where the command `git worktree add --detach --force /tmp/tmpy_4q2jth main` failed. The error was resolved by using v2_k7_1_6_3 until the changes in commit https://github.com/INTI-CMNB/KiBot/commit/d66188014c67307d9820ad9a72239d624488c446 are included in the LTS tag v2_k7. Following the resolution of issue https://github.com/INTI-CMNB/KiBot/issues/589, it will then be necessary to change `main` to `origin/main` in `diff.kibot.yaml`.
2024-03-08 fix: Field Remarks of component Q2-Q8 contains extra spaces
    kibot throws following warnings:
    WARNING:(W037) Field Remarks of component Q5 (Q_NMOS_GSD IPT012N08N5) contains extra spaces: `Alternative: Huayi HYG012N08NS1TA ` removing them. (kibot - v5_sch.py:1057)
    WARNING:(W037) Field Remarks of component Q3 (Q_NMOS_GSD IPT012N08N5) contains extra spaces: `Alternative: Huayi HYG012N08NS1TA ` removing them. (kibot - v5_sch.py:1057)
    WARNING:(W037) Field Remarks of component Q4 (Q_NMOS_GSD IPT012N08N5) contains extra spaces: `Alternative: Huayi HYG012N08NS1TA ` removing them. (kibot - v5_sch.py:1057)
    WARNING:(W037) Field Remarks of component Q9 (Q_NMOS_GSD IPT012N08N5) contains extra spaces: `Alt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
    [power-part.kicad_sch]
2024-03-17 Increase clearance around NPTH (v0.4.1)
    The NPTHs of the USB connector are very close to the pads, such that a
    clearance of 0.25 mm as required by some manufacturers was not possible.
    The clearance is now 0.2 mm.
    Fixes #55
    [bms-c1.kicad_pcb, bms-c1.kicad_sch, bq76952.kicad_sch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]
2024-04-26 Update files to KiCad v8
    [bms-c1.kicad_pcb, bms-c1.kicad_sch, bq76952.kicad_sch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]
2024-04-26 Include KiCad libraries as git submodules
2024-06-12 [User Manual] Added example when less than 16cells are used. (#62)
    * Adding extra 12s wiring example.
    Minor change on main connection diagram, changed color on BMS supply
    * Added details and extra example in Signal connections section
    * Link to proper flashing doc
    * Spaces fix for pdf generation
2024-10-08 Docs: Add test wiring harness documentation
2026-03-25 ci: Update KiBot action to v2_k9 for KiCad v9 support
2026-03-29 Add 10mm electrolytic cap to fix overvoltage spikes (#74)
    * changes done by jc-efactory:
    capacitor integrated, a 10mm SMD electrolitic footprint to test fix for issue #68, update to Kicad V9, rerouting, like the 3V3 plane was removed, now a GND layer as well and had to change a couple of capacitor to be able to fit the changes without any major redesign.
    * Fix in the design — connect/mark the unconnected pins and adjust the clearances to 0.1910 mm
    [bms-c1.kicad_pcb, bms-c1.kicad_sch, bms-c1_bom.csv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]
2026-03-29 Bump PCB version to v0.4.2
    [bms-c1.kicad_pcb, bms-c1.kicad_sch, bq76952.kicad_sch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]

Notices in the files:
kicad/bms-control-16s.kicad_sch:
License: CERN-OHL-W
